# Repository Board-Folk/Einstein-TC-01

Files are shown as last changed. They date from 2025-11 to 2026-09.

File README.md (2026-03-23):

# Einstein TC-01

Repository for the 2025 Board Folk recreation of the main board of the Einstein TC-01 computer from Tatung.

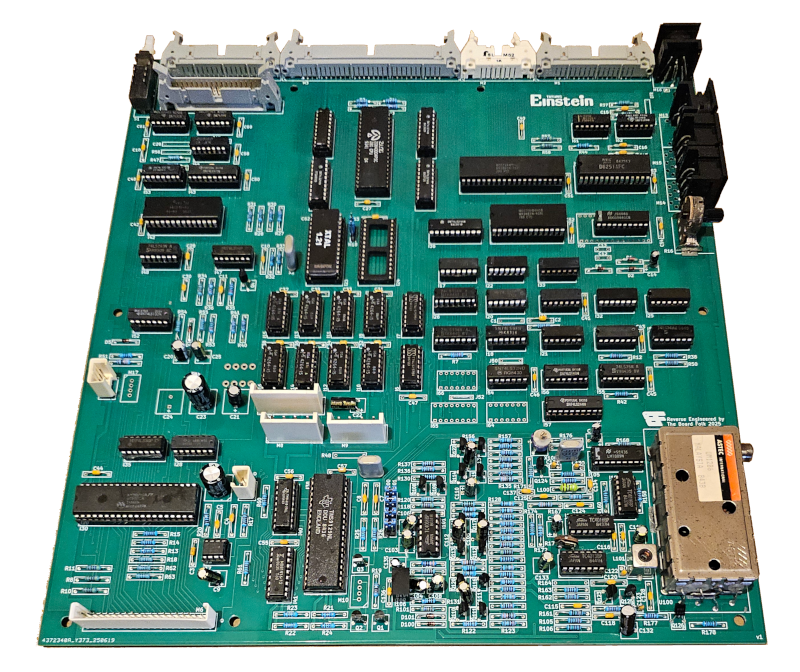
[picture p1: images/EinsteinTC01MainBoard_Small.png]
Built TC-01 board in Green


This repository contains the Bill-of-Materials (iBOM), Gerbers and Kicad files for a remake of the Tatung Einstein TC-01 main board.

Projects are in Kicad 9.

## Revisions

* Version 1.1 Initial Public Release

## Modifications

* The 3 digit references have been abridged so they work in Kicad
* The factory modifications (cuts and bodge wires) for the reset circuit have been included on the board
* Bodge capacitor C70 included on board for printer port strobe delay
* A solder jumper next to socket M16 provides the common modification of 5V power to pin 6 on the video output socket as you'd have on a BBC Micro
* Some small silkscreen improvements have been made to avoid confusion

## Build Notes

* Power connectors are 5.08mm pin headers
* M6 keyboard pin header is 2.5mm not 2.54mm pitch
* Corner line indicator on transistor footprints signifies flat front side direction, NOT pin 1
* BC307 can be subtituted for BC557
* BC308 can be subtituted for BC558
* Reset switch is the same as the one found on the TRS-80 Model I
* The ADC0844 alternative footprint is a µPD7002 which requires C13 populating with 33nF (untested)
* The value/range of L101 "Chrominance Rejector" is at this time unknown

## Archive

Currently contains the original copy of the v1.1 main board, which hasn't changed. The updated main Kicad folder now contains additional symbols and footprints only.

## Credit

Mainboard PCB layout by Rob Taylor @peepouk. Schematics recreated by Ian Cudlip @grandoldian.

## Expansions

### TMSAdapterTC01

Adapter board to allow the use of a TMS9929 chip on the Tatung Einstein TC-01.

### EinsteinTC01PS2

Arduino Nano based PS/2 Keyboard Adapter for the TC-01.

### EinsteinTC01PS2Mini

ATMEGA328 based PS/2 Keyboard Adapter for the TC-01.

### V9958AdapterTC01

Yamaha V9958/V9938 Adapter with 192K Video RAM for the TC-01.

### TC02Mini

Simple non-replica remake of the TC-02 80 column adapter for the TC01.

### Joystick Adapters

#### TC01AtariJoystick

Dual Atari Digital Joystick Adapter.

#### Withdrawn Tandy Joystick Adapter

It turns out the y axis on Tandy joysticks is connected the other way round, which means it will require circuitry to make it work for Einstein games. Trying to think of something clever for that.

## Remixes

### Einstein CE

Simplified Einstein with bits removed to fit on a small board. See description in folder.

## Coming Soon

* Another, comprehensive remix with expansions

## Links

   [10.6875MHz HC-49U Crystal](https://slawmir.com.pl/rezonator-10-6875mhz-hc49u-x5-p-6105.html)  
   [5 pin "Domino" DIN Socket for Serial Port](https://vintage.imitation.parts/products/bbc-micro-parts/din-5-pcb-socket)  
   [Modifyable bracket for holding standard Volume Pot](https://sonicsynths.com/products/pcb_mounting_bracket_for_16mm_commercial_grade_pots)

## Thanks

  * The rest of the Board Folk Team

## Legal

As the product of this project is a replica of a proprietary product, the the author makes no claim of copyright to the schematics nor PCB layouts and releases these into the public domain, solely for the purposes of study and historical preservation.

You are free to produce PCBs based on this project's designs at your own risk and without limitation, for your own use or for sale and/or repair at a reasonable price. Attribution is appreciated. The authors are not obliged to provide support of any kind. 

Under no circumstances will the authors be held responsible or liable in any way for losses, damages or costs resulting from the use of the information and/or resources of this project. 

The resources are provided "as-is" without warranty of any kind, either expressed or implied, including, but not limited to, the implied warranties of merchantability and fitness for a particular purpose.

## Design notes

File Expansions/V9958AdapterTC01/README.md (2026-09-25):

# Einstein TC-01 V9958/V9938 VDP adapter

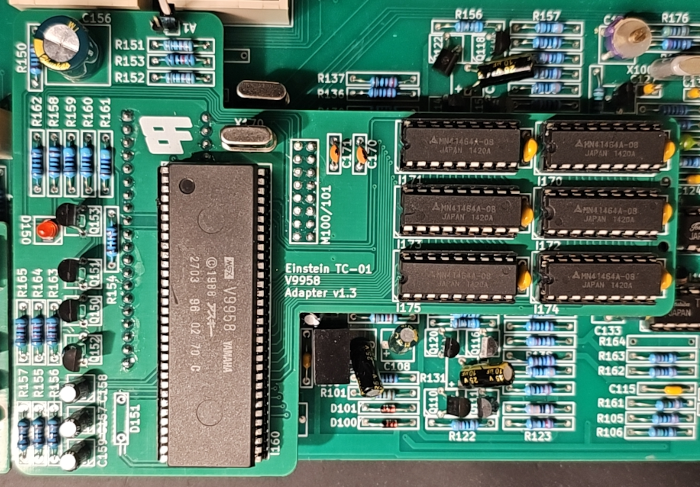
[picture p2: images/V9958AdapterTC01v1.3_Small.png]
Built TC-01 V9958 adapter board in green fitted on a TC-01


Adapter board to allow the use of a Yamaha V9958 or V9938 VDP chip on the Tatung Einstein TC-01. The board requires 192KB RAM, as 6 of 4464 (41464) RAM chips, to make the video capability of the board same as (or better than) the Einstein 256, and works with the ROM from that machine, e.g. XTAL MOS 2.1.

The board plugs into the existing VDP socket, replacing the original TMS VDP chip, and connects to video output by replacing the jumpers at M100/101 outputting RGB to the socket on the back of the TC-01. This disconnects the other video circuitry and RF output on the main board, that being YUV based.

The VDP plug to get the right height has been tested with 2 of 20 pin 15mm single pin headers and for connection for video output, 2x08 PC104 pin plug with a single spacer. Careful, as big pins can bork a DIP-40 socket, so be prepared to change that if necessary. Holes for nylon standoffs have been included at the other end of the board for support, though this isn't really necessary.

Address line A1 needs connecting up for this to function as it's not present on the original VDP socket. This is the pin with a box on the two pin header on the edge of this board. The nearest point on the main board for buffered A1 is pin 3 of I28.

Video output is provided by simple transistor based circuits. It seems fine, but some resistor values may need tweaking.

You do not need to fit the video RAM chips on the main board at I40 and I41 with this installed.

Not used or tested at the moment is the other pin on the header next to A1 which is for /WAIT which may or may not be used by any software at all, don't know about this, so connected this with a diode D151 (flagged DNP) between the VDP and the pin header. There isn't anything on the main board that uses /WAIT - that only connects to the Tatung Tube expansion port. This doesn't need connecting unless software uses it, and isn't required to function generally.

Note: The pre-connected solder bridge on the bottom of the board - required for the V9958 - should be cut if installing a V9938. This has now been tested and works fine.

Some fake/relabelled AliExpress RAM got very hot and died on this board after passing regular RAM tests, so be careful what you use. Not sure of the official speed requirements. Equally, there are plenty of completely fake V9958, many labelled copyright 1901.

## Update

A couple of issues have been noted when installing this on an original factory built TC-01 that didn't crop up in testing on the replica build. The first relating to this board, the second relating to the use of the Einstein 256 ROM in the TC-01.

### Fix 1

The original voltage regulator at I106 as factory fitted is a LM350T5, which with this VDP adapter fitted overheats and cuts out causing the system to crash. This needs replacing with a higher rating compatible regulator, 1 Amp or greater. Fitting the wrong voltage regulator or voltage regulator the wrong way round will cause serious damage. This has been successfully tested with a Traco TSR 1-2450. You can test the voltage either side of C057 (C57 on the replica) before fitting any VDP for 5V.

### Fix 2

On some systems with the Einstein 256 ROM fitted, Alph lock randomly enables and disables. This is due to a port being missing at address 26h that is present on the Einstein 256 and not on the TC-01. A patch to the ROM is needed to stop this happening.

Port 26h is read and checked for bit 0 for the Alph key being pressed in 3 places in the ROM code, first offset 7d8h. The three occurrences of db26e601 can be replaced with with db26e600 - removing the bit comparison for the Alph key.

## Photos

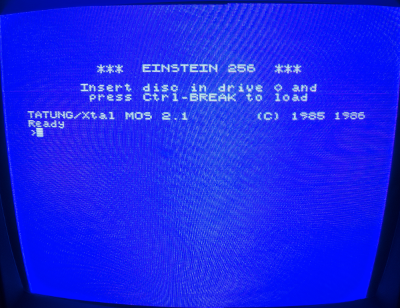
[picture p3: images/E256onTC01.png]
Einstein 256 boot screen on a TC-01


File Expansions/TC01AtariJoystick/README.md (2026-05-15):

# Einstein TC01 Dual Atari Digital Joystick Adapter v1.1

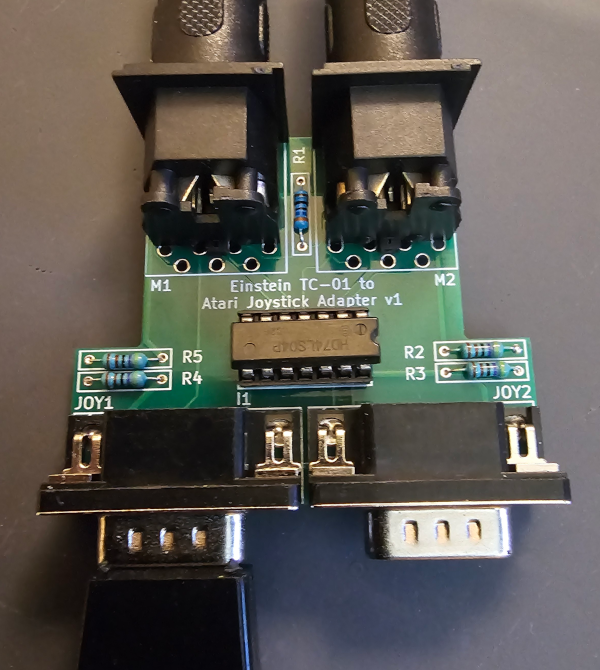
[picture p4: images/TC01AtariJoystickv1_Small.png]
Built TC01 Dual Atari joystick adapter board v1 in Green


Dual joystick adapter for Atari and compatible (Kempston/C64/Amiga/ST etc) digital joysticks. Tested with SVI Quickshot II Plus.

Based on Wizard Development 'BBC' joystick interface. Very clever, many thanks.

Update: Turns out having a fixed resistor at R1 was a bad idea as the output of the Vref circuit seems to be different between main board builds. This makes the analogue centre different. You can patch in a variable resistor/pot as an adjustment. One board needed changing to ~1K. Will post an update soon and some BASIC code for adjustment/tweaking.

## Versions

v1.1 Fix for x direction

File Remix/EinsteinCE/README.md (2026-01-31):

# Einstein CE

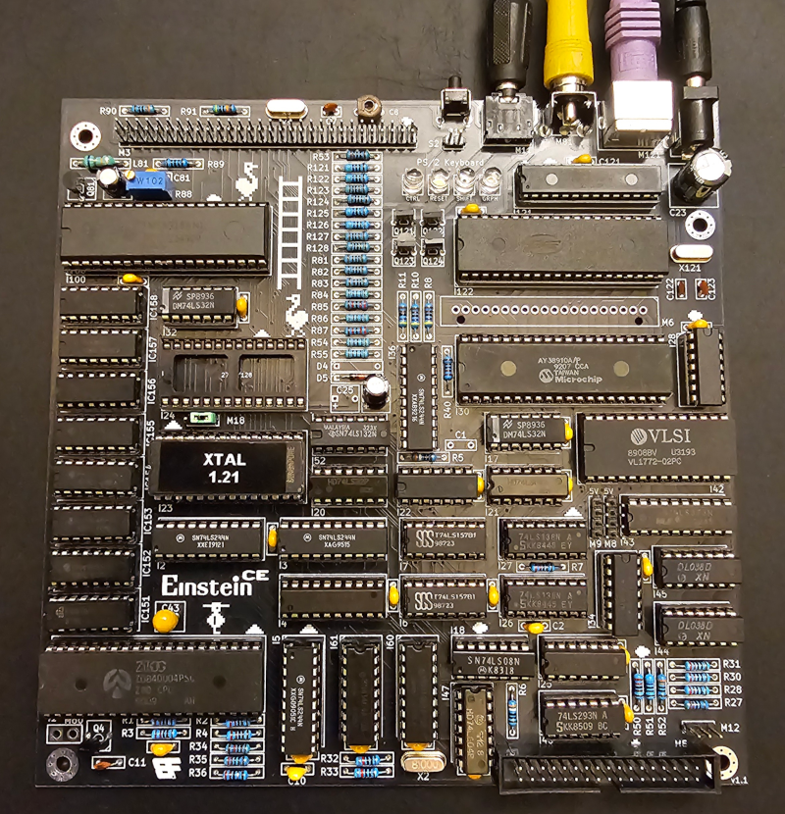
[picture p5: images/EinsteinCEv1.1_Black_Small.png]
Built Einstein CE system board in black


A simplified Einstein.

This isn't particularly serious and it's going to have some haters, so an explanation is needed first off. The idea was to do an as simple as possible Einstein - bits removed or substituted - to fit on a mini-ITX board (170x170mm) as 5V only to prove some schematics. It's cheap to make, being small and the VDP being substituted, the only particularly expensive chip being the WD1770.

The theme, as it suggests is a minimum to run Chuckie Egg. Will runs other games and things too, but nothing that requires the bits removed, with the idea of doing an overlay board to add some things back later if need be. It's not particularly beautiful, it's 50% autorouted then tidied, but it works well enough.

Video output is simple, NTSC colour composite out. PAL would be much more expensive/complex - it wouldn't fit. It's a bit of fun and means to an end.

## Revisions

* Version 1.1 Initial Public Release

## Things Removed

  * CTC
  * PIO
  * Serial port
  * Analogue joystick ports
  * YUV/RGB and RF modulator
  * Audio amplifier

## Things Changed

  * VDP and video RAM - TMS9918 and 8 of 1 bit (16K x 1) RAM
  * 4464/41464 System RAM (not 4164)
  * Simplified keyboard (IO only as no interrupt thing)
  * 2 drive support (not 4)

## Things Added

  * Stereo 3.5mm audio out (similar to Amstrad CPC)
  * PS/2 keyboard interface on board
  * Reset switch (rear right angle, and pin header)
  * Composite out (NTSC)

## Things to Note

### Power

  * Power's provided by a standard DC power jack, 5V regulated, centre positive
  * M60 header is provided as a separate 5V input - might do an adapter for an ATX type supply at some point for this
  * M8 and M9 headers for floppy power are also 5V only, pin 1 is disconnected. This is fine for Gotek

### Video RAM

As it the whole board is 5V only, the video RAM is 5V, *not* the traditional 4116 as you'd typically have with a TMS9918. Specified is MB8118 RAM if you can find it, but cheaper, 8 of the more available 4164 or 41256 RAM can be used in it place (mostly wasted, but it works).

### Known Compatibility Issues

More will follow in time

  * It appears the Einstein Speculator uses the CTC, so that's not going to work sadly

## Build Notes

  * To reiterate (sorry) in Kicad, the square pin is pin 1. On an electrolytic capacitor this is positive, the long leg. On an LED, this is K, cathode, the short leg
  * M6 remains to connect an original keyboard if necessary, and probably isn't required. This is still 2.50mm
  * C8 trims the NTSC clock frequency
  * R88 adjusts the composite brightness
  * 3.5mm Stereo Socket and RCA socket are available from Amazon (links below)
  * TMS9918 is not to be confused with TMS9118

## Links

   [3.5mm Jack Connector](https://www.amazon.co.uk/dp/B07422MCSX)  
   [RCA/Phono Jack Connector](https://www.amazon.co.uk/dp/B07PL9C7X8)  

## Credit

Schematics and PCB Layout by Ian Cudlip @grandoldian. Footprints by Rob Taylor @peepouk.

## Thanks

  * Special thanks to Chrissy (@chris_jh), Jens Restemeier (@JensRestemeier) and Leo Oliveira (@leo__oliveira).
  * The rest of the Board Folk Team.

## Photos

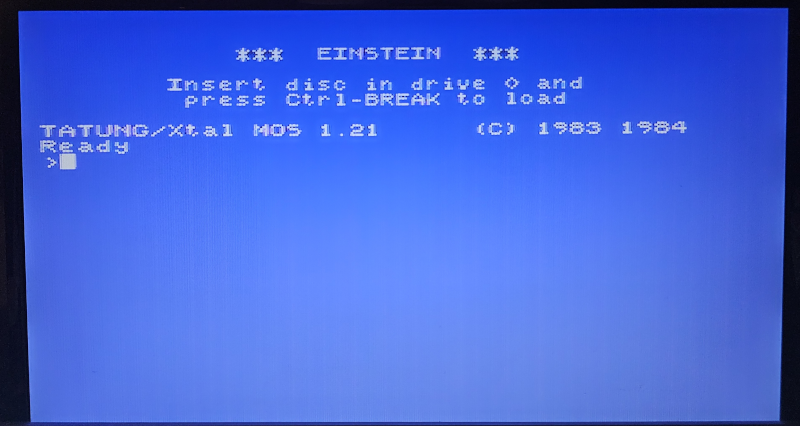
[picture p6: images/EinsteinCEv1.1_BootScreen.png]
Poor photo of Einstein CE on the Boot Screen

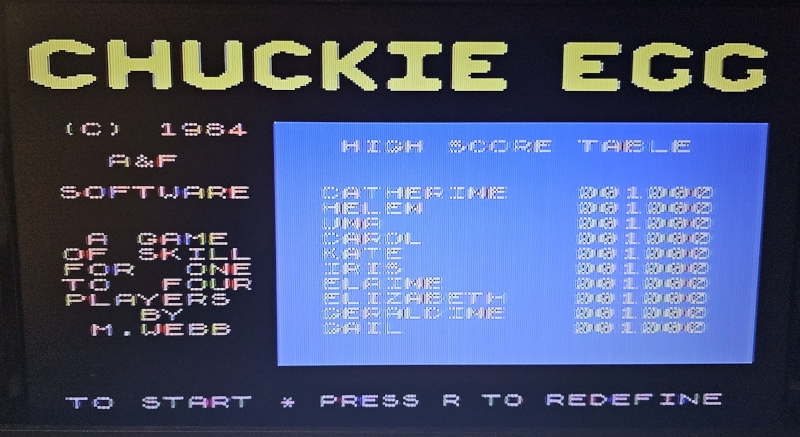
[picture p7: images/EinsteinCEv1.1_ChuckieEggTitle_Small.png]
Poor photo of Chuckie Egg Title Screen

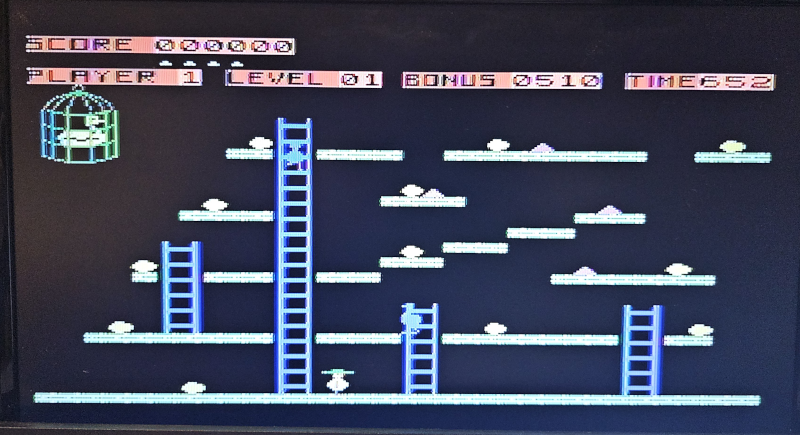
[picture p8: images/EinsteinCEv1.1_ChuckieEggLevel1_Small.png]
Poor photo of Chuckie Egg Level 1


(does look better than the photos show, though clearly NTSC)

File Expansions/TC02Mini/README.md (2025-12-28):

# Einstein TC-02Mini 80 Column Adapter

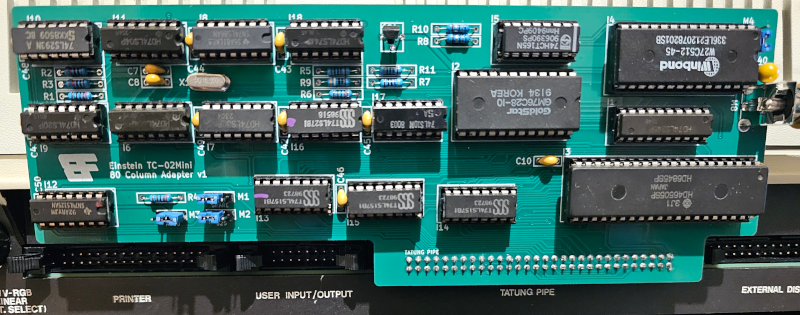
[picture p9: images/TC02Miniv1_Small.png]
Built TC-02Mini v1 adapter board in Green


A simple, non-replica (schematics the same) remake of the TC-02 80 column board. Could be mounted on a ribbon cable, or as pictured on PC104 pin sockets (at full stretch). Required Character ROM at I4 in CHARROM folder. Please see the original manual for instructions for use.

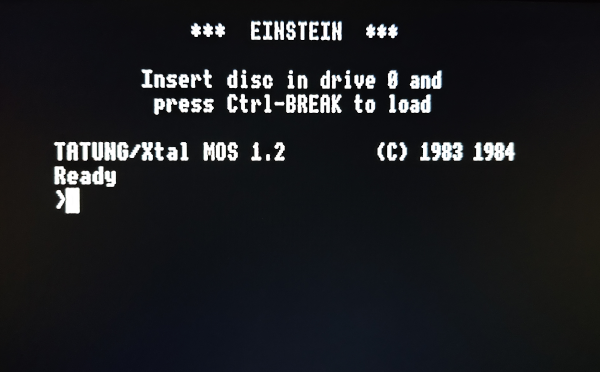
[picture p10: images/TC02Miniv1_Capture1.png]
Screenshot showing the Einstein Boot Screen


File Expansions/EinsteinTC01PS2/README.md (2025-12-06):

# EinsteinTC01PS2 v1.2

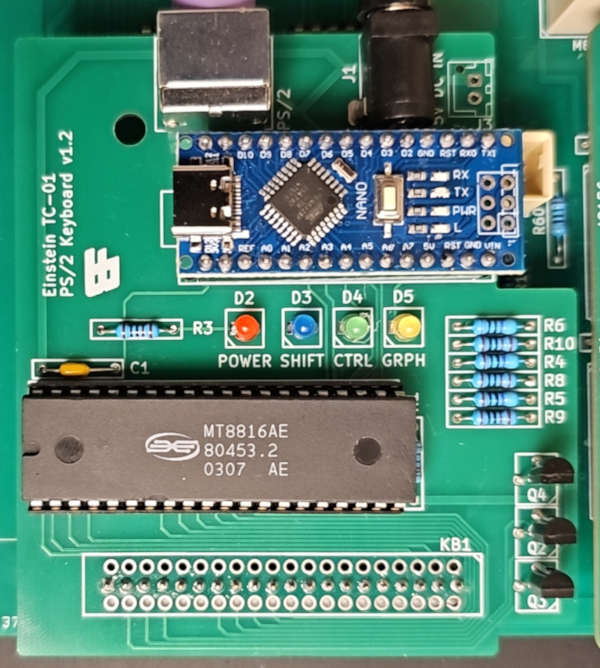
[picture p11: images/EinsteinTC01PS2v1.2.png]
Image of PS2 Nano version 1.2 board in green


The Arduino Nano version of a PS/2 keyboard adapter for the Einstein TC-01. This is a larger version of the board intended for development of the Arduino code for it, though is perfectly usable. The board uses separate pins from the Nano to pull Shift, Ctrl and Grph through BC517 darlington pairs.

The board needs a separate 5V power connection as there is no power output on the Einstein's keyboard header. Footprints for both a barrel jack and 2 pin XH connector are provided for this.

There are 3 rows of pin headers, the centre row being 2.54mm, the other 2 2.50mm same as the main board. This arrangement could be use for passthrough to an existing keyboard if necessary.

## Code

The Arduino folder contains the code and can be loaded with Arduino IDE. This is based on C64Keyboard by Robert VanHazinga. Key mappings can be found in keymapping.h. This code is the same for smaller EinsteinTC02PS2, the built binaries for which are in the build folder.

The code is usable as is, but will improve over time. Sometimes gets stuck needing a hard reset. It includes code for future remix versions of the project, including keyboard reset and separate Alph for the 256.

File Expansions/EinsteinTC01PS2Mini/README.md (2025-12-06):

# EinsteinTC01PS2Mini v1

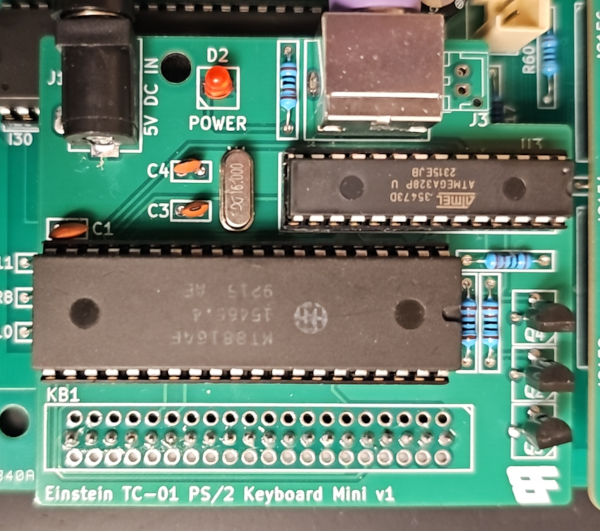
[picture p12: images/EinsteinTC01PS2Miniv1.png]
Image of PS2 ATMEGA328 version 1 board in green


The smaller ATMEGA328 version of a PS/2 keyboard adapter for the Einstein TC-01. The board uses separate pins from the Nano to pull Shift, Ctrl and Grph through BC517 darlington pairs. This version doesn't include indicator LEDs for these.

The board needs a separate 5V power connection as there is no power output on the Einstein's keyboard header. Footprints for both a barrel jack and 2 pin XH connector are provided for this.

There are 3 rows of pin headers, the centre row being 2.54mm, the other 2 2.50mm same as the main board. This arrangement could be use for passthrough to an existing keyboard if necessary.

## Code

Code can be found in the EinsteinTC01PS2 folder, including the compiled binaries for the ATMEGA328. See any notes in there. The Minipro TL866 II can be use to program that. These settings work:

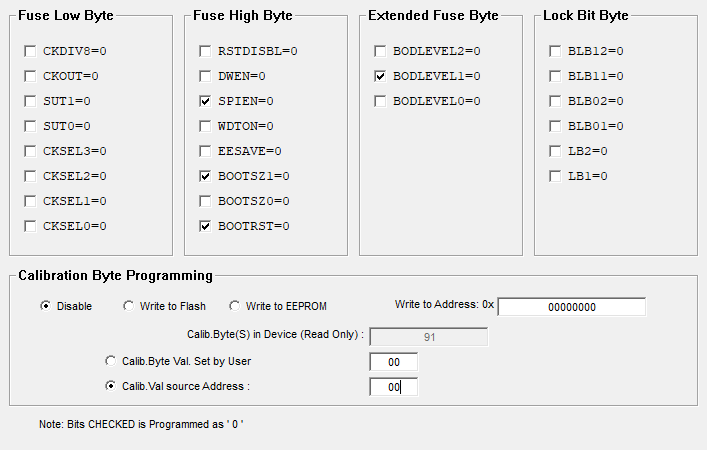
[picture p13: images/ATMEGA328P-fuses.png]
Windows Minipro software settings for programming the ATMEGA328 for this board


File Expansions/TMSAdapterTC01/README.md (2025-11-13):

# Einstein TC-01 TMS9929 adapter

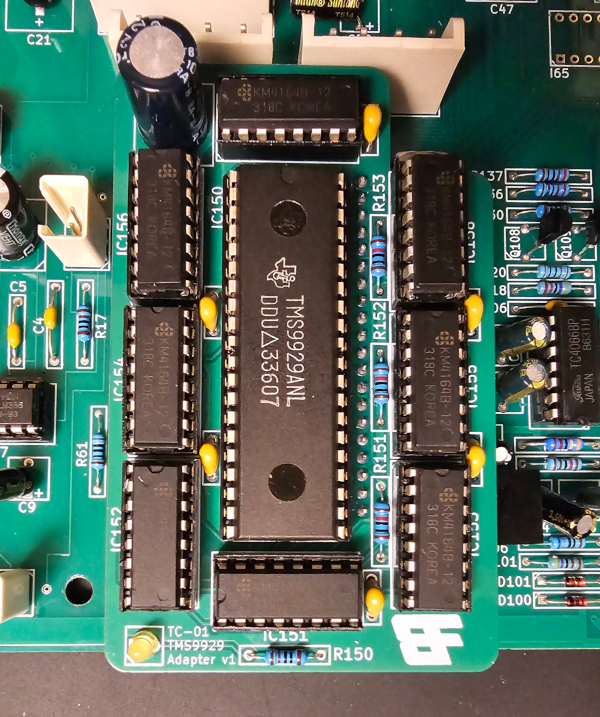
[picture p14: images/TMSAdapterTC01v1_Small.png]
Built TC-01 TMS9929 adapter board in Green


Adapter board to allow the use of a TMS9929 chip on the Tatung Einstein TC-01. The TMS9929 is easier to find than the original VDP, but requires a different type of RAM which needs fitting to the adapter.

Intended to work with 5V 1x16K DRAM chips, e.g. MB8118 or compatible, but can accept 4164 and 41256 RAM, which although is a waste as the majority of the RAM isn't used are more easily and cheaply obtained. This will not work with 4116 RAM as the board doesn't provide the correct voltages.

You do not need to fit the video RAM chips on the main board at I40 and I41 with this installed.

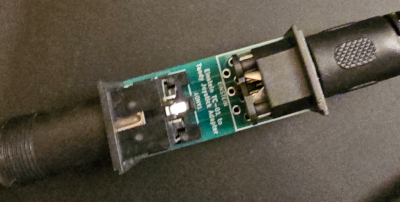
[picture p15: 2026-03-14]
images/TC01TandyJoystickv1_Small.png

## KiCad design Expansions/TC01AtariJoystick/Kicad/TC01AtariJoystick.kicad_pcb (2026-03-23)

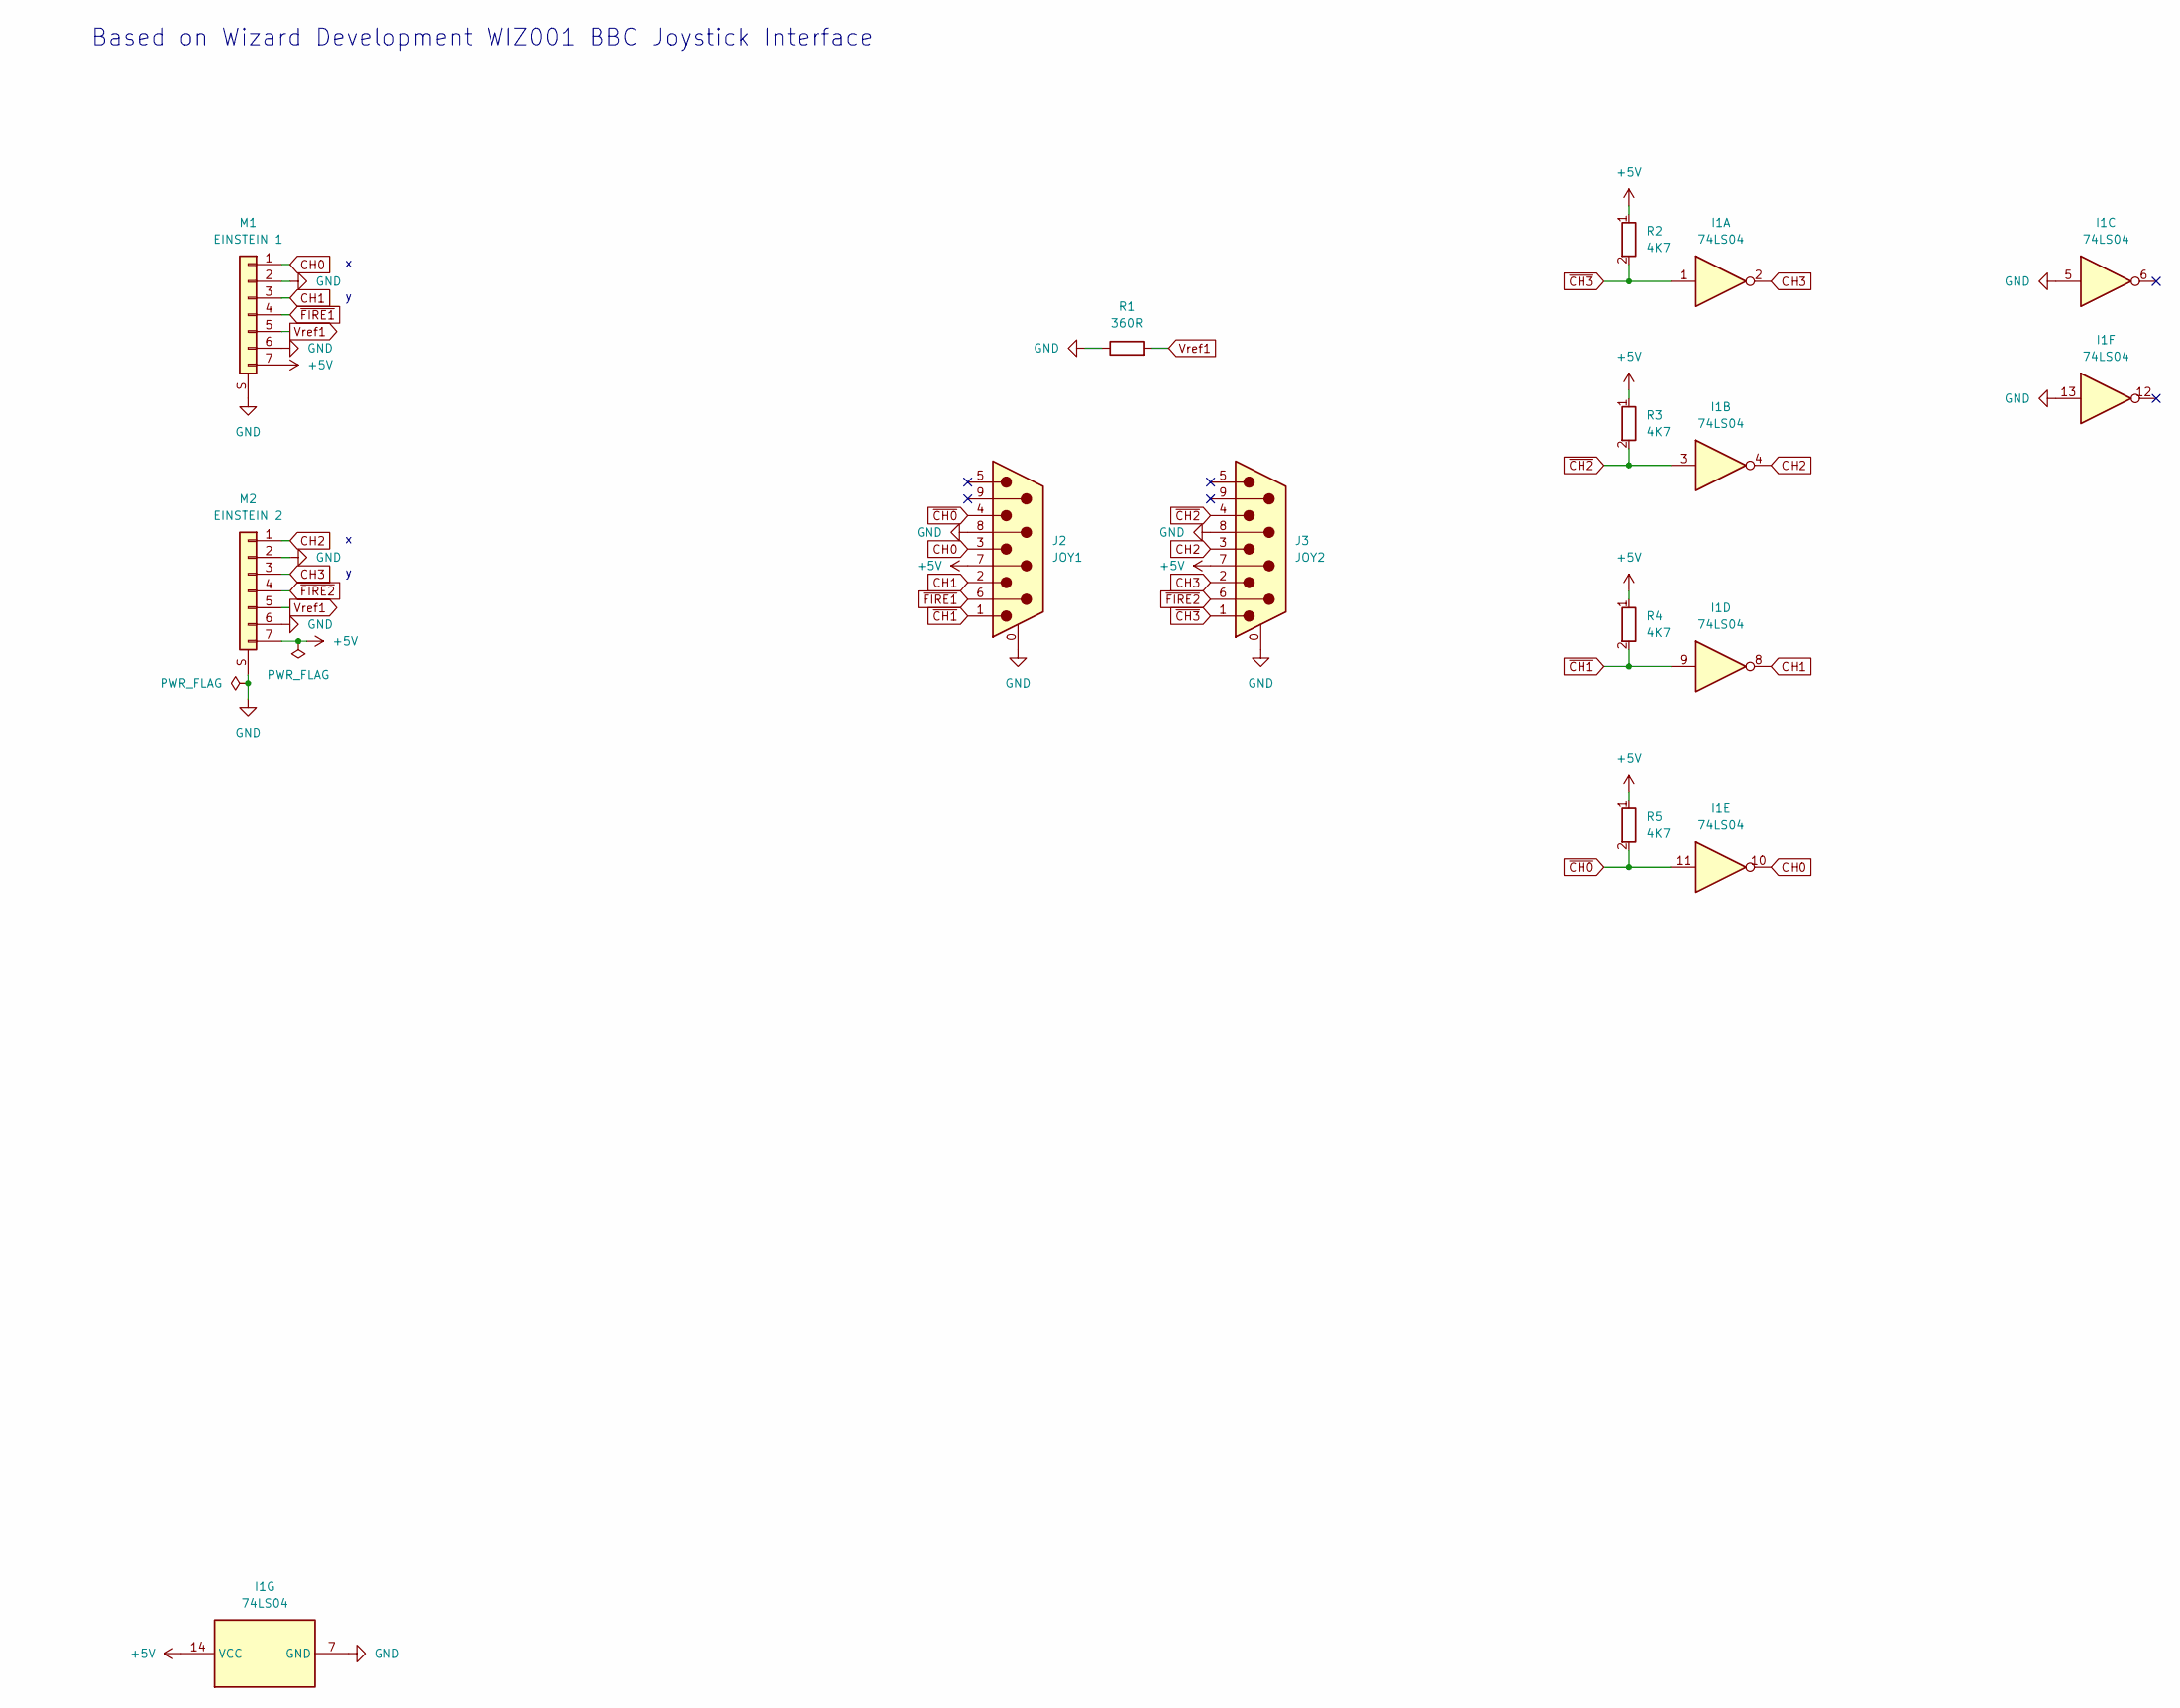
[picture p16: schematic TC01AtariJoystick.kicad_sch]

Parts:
I1: 74LS04; DIP-14_W7.62mm
J2: JOY1; DSUB-9_Pins_7.70mm_9.12mm
J3: JOY2; DSUB-9_Pins_7.70mm_9.12mm
M1: EINSTEIN 1; DIN7_3WAYS
M2: EINSTEIN 2; DIN7_3WAYS
R1: 360R; Resistor 10.16mm
R2, R3, R4, R5: 4K7; Resistor 10.16mm

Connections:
+5V: I1.14 (VCC), J2.7, J3.7, M1.7, M2.7, R2.1, R3.1, R4.1, R5.1
CH0: I1.10, J2.3, M1.1
CH1: I1.8, J2.2, M1.3
CH2: I1.4, J3.3, M2.1
CH3: I1.2, J3.2, M2.3
GND: I1.5, I1.7 (GND), I1.13, J2.0 (PAD), J2.8, J3.0 (PAD), J3.8, M1.2, M1.6, M1.S (Shield), M2.2, M2.6, M2.S (Shield), R1.1
Vref1: M1.5, M2.5, R1.2
~CH0: I1.11, J2.4, R5.2
~CH1: I1.9, J2.1, R4.2
~CH2: I1.3, J3.4, R3.2
~CH3: I1.1, J3.1, R2.2
~FIRE1: J2.6, M1.4
~FIRE2: J3.6, M2.4

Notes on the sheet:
Based on Wizard Development WIZ001 BBC Joystick Interface

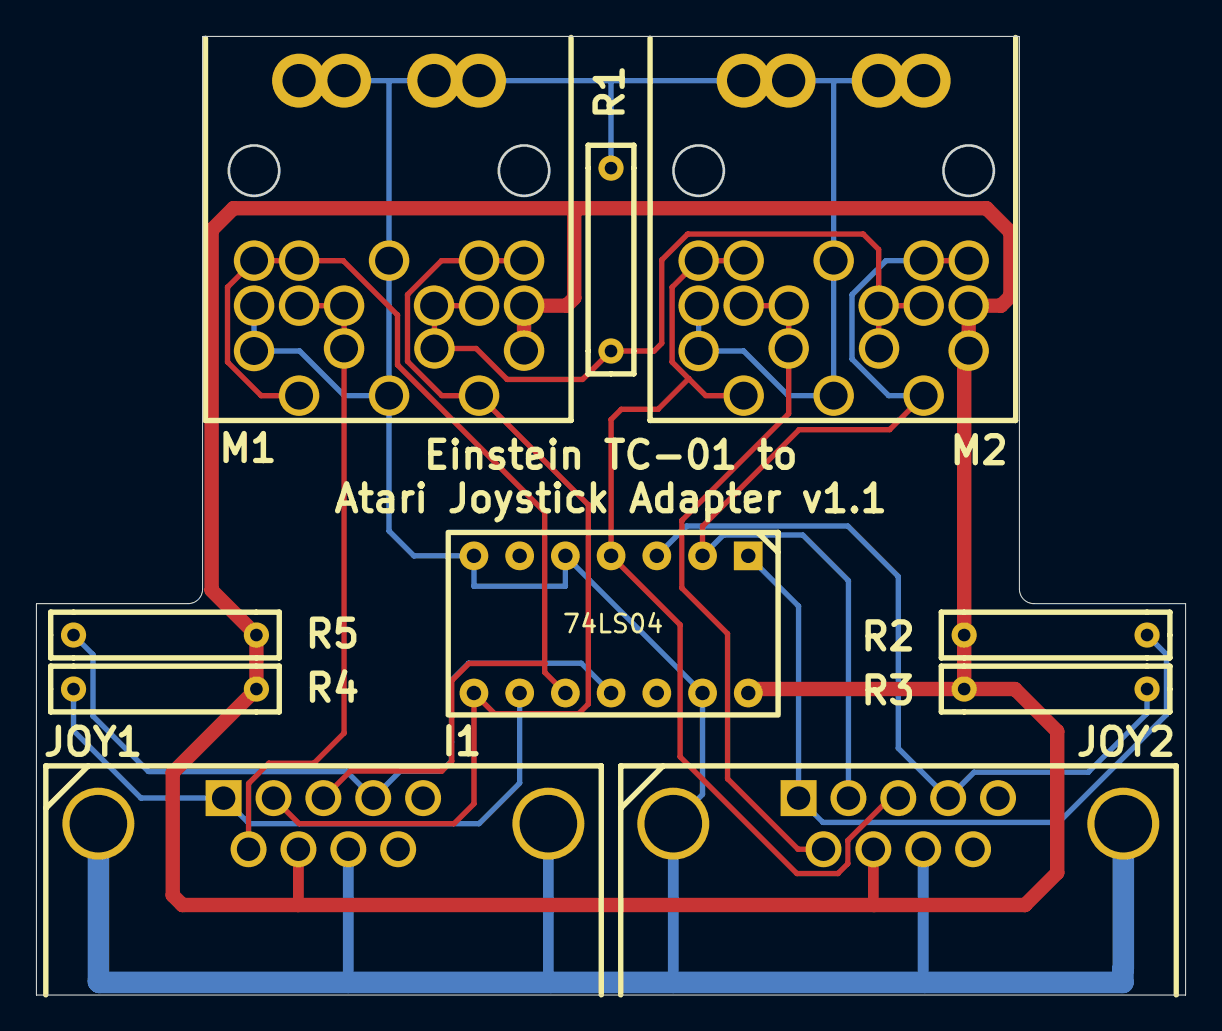
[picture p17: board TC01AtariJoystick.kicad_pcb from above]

Board: 2 copper layers, 63.8 x 53.3 mm, 10 parts (0 on the bottom side), 13 nets.

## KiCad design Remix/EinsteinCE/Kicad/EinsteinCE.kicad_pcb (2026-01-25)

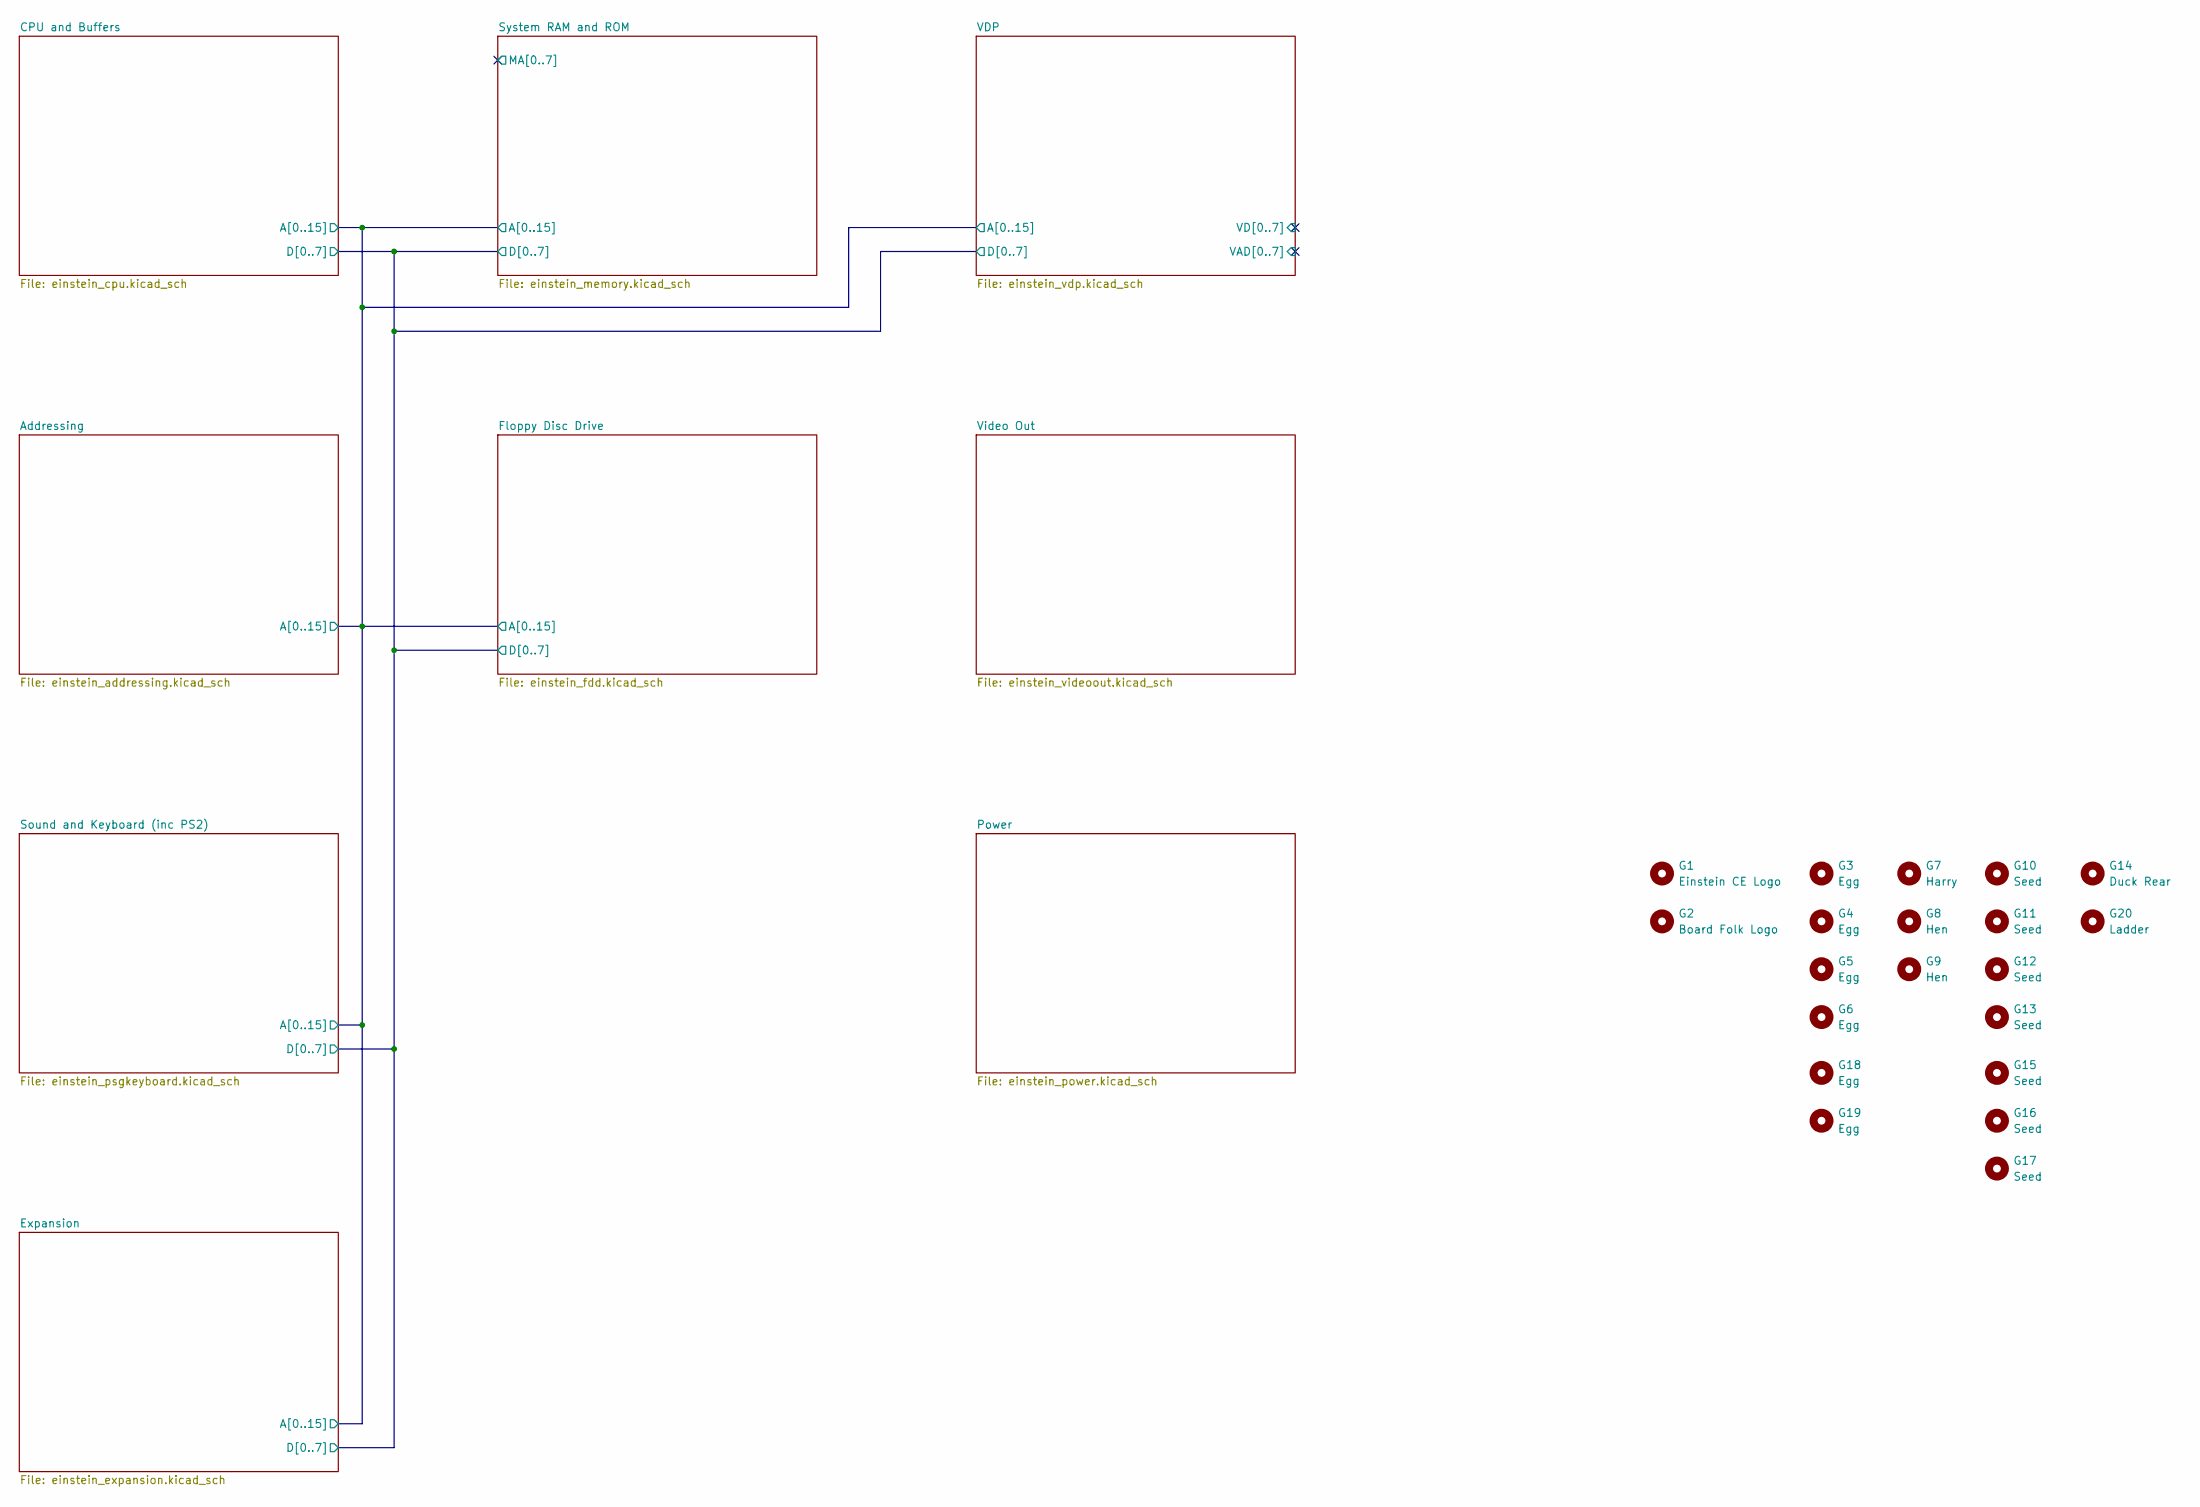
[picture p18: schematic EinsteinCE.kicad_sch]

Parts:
G1: Einstein CE Logo; EinsteinCELogo28mm
G2: Board Folk Logo; BF8
G3, G4, G5, G6, G18, G19: Egg; Egg5mm
G7: Harry; Harry8mm
G8: Hen; Hen8mm
G9: Hen; Hen_Left_8mm
G10, G11, G12, G13, G15, G16, G17: Seed; Seed6mm
G14: Duck Rear; Duck166mm
G20: Ladder

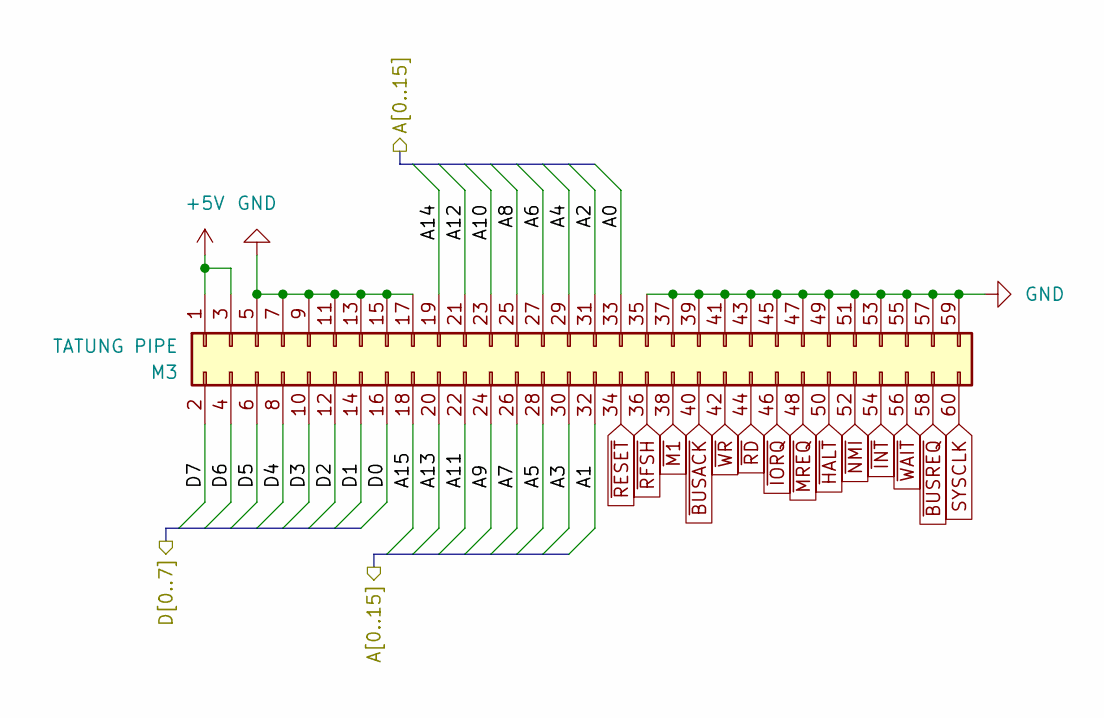
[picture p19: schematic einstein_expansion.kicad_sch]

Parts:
M3: TATUNG PIPE; M3 PinHeader_2x30_P2.54mm

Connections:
+5V: M3.1, M3.3; also elsewhere on the board
/Addressing/A0: M3.33; also elsewhere on the board
/Addressing/A1: M3.32; also elsewhere on the board
/Addressing/A2: M3.31; also elsewhere on the board
/Addressing/A3: M3.30; also elsewhere on the board
/Addressing/A4: M3.29; also elsewhere on the board
/Addressing/A5: M3.28; also elsewhere on the board
/Addressing/A6: M3.27; also elsewhere on the board
/Addressing/A7: M3.26; also elsewhere on the board
/Addressing/A8: M3.25; also elsewhere on the board
/Addressing/A9: M3.24; also elsewhere on the board
/Addressing/A10: M3.23; also elsewhere on the board
/Addressing/A11: M3.22; also elsewhere on the board
/Addressing/A12: M3.21; also elsewhere on the board
/Addressing/A13: M3.20; also elsewhere on the board
/Addressing/A14: M3.19; also elsewhere on the board
/Addressing/A15: M3.18; also elsewhere on the board
/CPU and Buffers/D0: M3.16; also elsewhere on the board
/CPU and Buffers/D1: M3.14; also elsewhere on the board
/CPU and Buffers/D2: M3.12; also elsewhere on the board
/CPU and Buffers/D3: M3.10; also elsewhere on the board
/CPU and Buffers/D4: M3.8; also elsewhere on the board
/CPU and Buffers/D5: M3.6; also elsewhere on the board
/CPU and Buffers/D6: M3.4; also elsewhere on the board
/CPU and Buffers/D7: M3.2; also elsewhere on the board
GND: M3.5, M3.7, M3.9, M3.11, M3.13, M3.15, M3.17, M3.35, M3.37, M3.39, M3.41, M3.43, M3.45, M3.47, M3.49, M3.51, M3.53, M3.55, M3.57, M3.59; also elsewhere on the board
SYSCLK: M3.60; also elsewhere on the board
~BUSACK: M3.40; also elsewhere on the board
~BUSREQ: M3.58; also elsewhere on the board
~HALT: M3.50; also elsewhere on the board
~INT: M3.54; also elsewhere on the board
~IORQ: M3.46; also elsewhere on the board
~M1: M3.38; also elsewhere on the board
~MREQ: M3.48; also elsewhere on the board
~NMI: M3.52; also elsewhere on the board
~RD: M3.44; also elsewhere on the board
~RESET: M3.34; also elsewhere on the board
~RFSH: M3.36; also elsewhere on the board
~WAIT: M3.56; also elsewhere on the board
~WR: M3.42; also elsewhere on the board

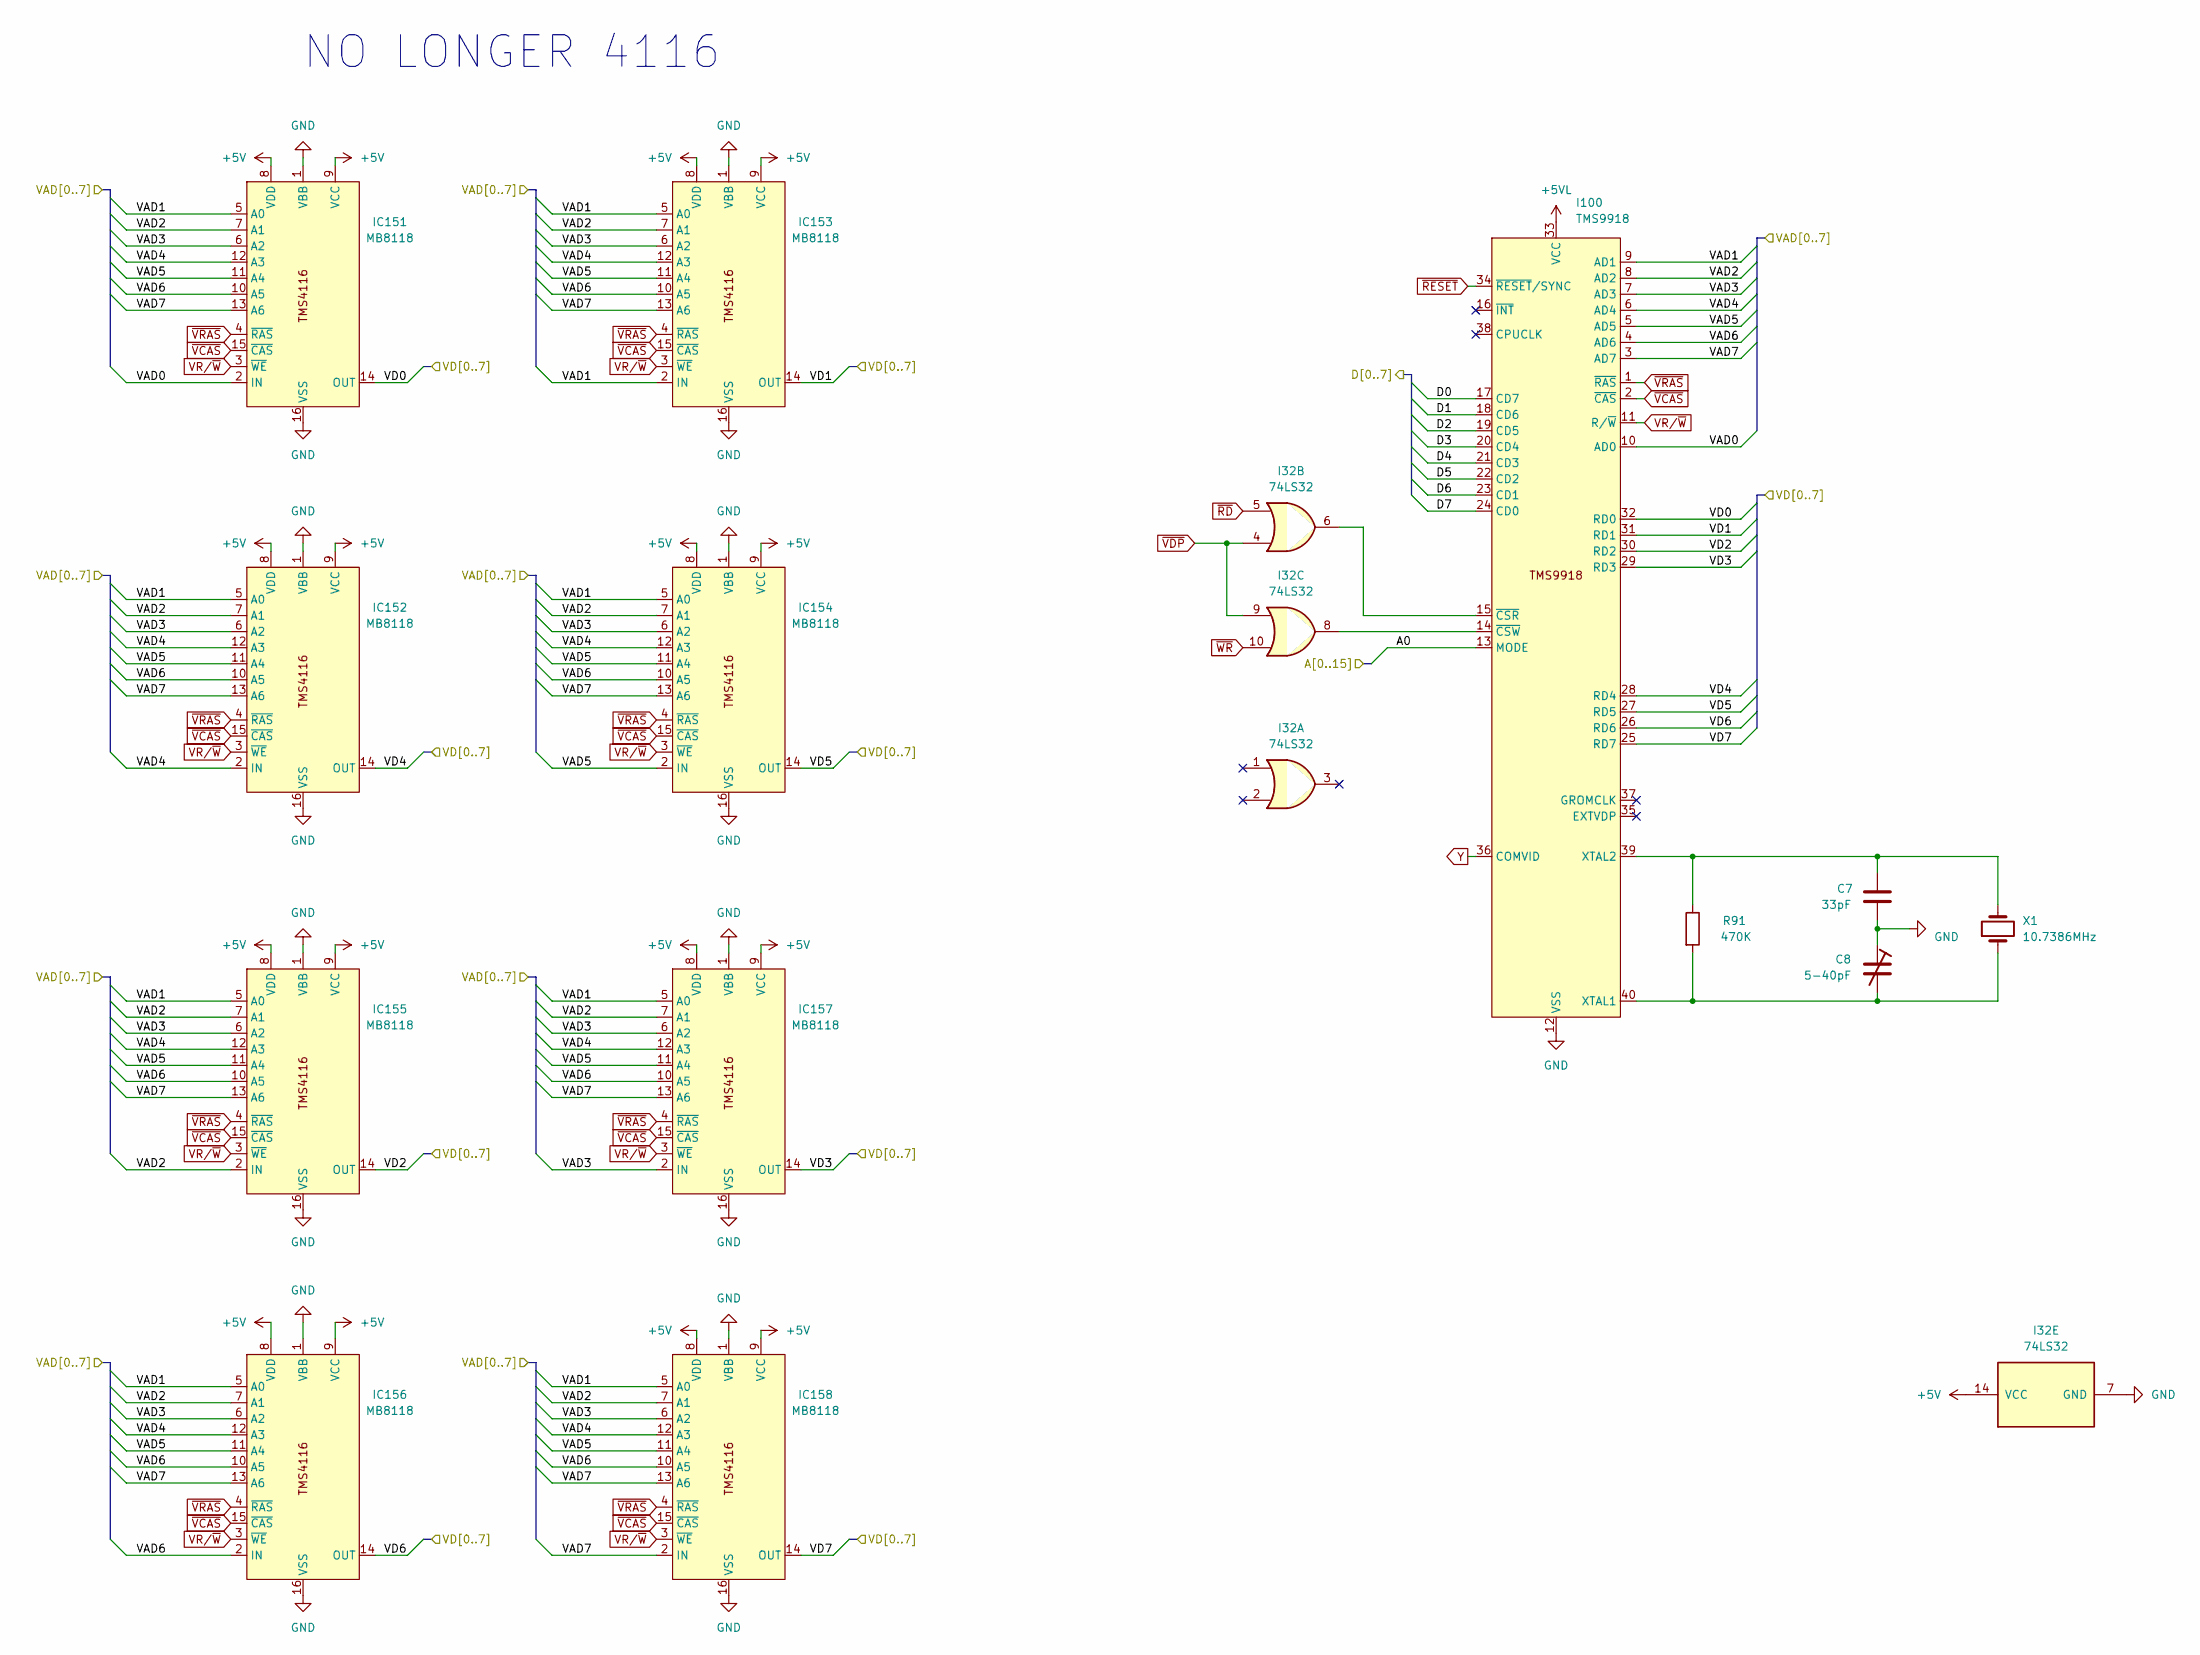
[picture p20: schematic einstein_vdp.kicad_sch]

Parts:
C7: 33pF; C_Disc_2.54mm
C8: 5-40pF; CVN6500
I32: 74LS32; DIP-14_W7.62mm
I100: TMS9918; DIP-40_W15.24mm
IC151, IC152, IC153, IC154, IC155, IC156, IC157, IC158: MB8118; DIP-16_W7.62mm
R91: 470K; Resistor 10.16mm
X1: 10.7386MHz; Crystal

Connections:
+5V: I32.14 (VCC), IC151.8 (VDD), IC151.9 (VCC), IC152.8 (VDD), IC152.9 (VCC), IC153.8 (VDD), IC153.9 (VCC), IC154.8 (VDD), IC154.9 (VCC), IC155.8 (VDD), IC155.9 (VCC), IC156.8 (VDD), IC156.9 (VCC), IC157.8 (VDD), IC157.9 (VCC), IC158.8 (VDD), IC158.9 (VCC); also elsewhere on the board
+5VL: I100.33 (VCC); also elsewhere on the board
/Addressing/A0: I100.13 (MODE); also elsewhere on the board
/CPU and Buffers/D0: I100.17 (CD7); also elsewhere on the board
/CPU and Buffers/D1: I100.18 (CD6); also elsewhere on the board
/CPU and Buffers/D2: I100.19 (CD5); also elsewhere on the board
/CPU and Buffers/D3: I100.20 (CD4); also elsewhere on the board
/CPU and Buffers/D4: I100.21 (CD3); also elsewhere on the board
/CPU and Buffers/D5: I100.22 (CD2); also elsewhere on the board
/CPU and Buffers/D6: I100.23 (CD1); also elsewhere on the board
/CPU and Buffers/D7: I100.24 (CD0); also elsewhere on the board
/VDP/VAD0: I100.10 (AD0), IC151.2 (IN)
/VDP/VAD1: I100.9 (AD1), IC151.5 (A0), IC152.5 (A0), IC153.2 (IN), IC153.5 (A0), IC154.5 (A0), IC155.5 (A0), IC156.5 (A0), IC157.5 (A0), IC158.5 (A0)
/VDP/VAD2: I100.8 (AD2), IC151.7 (A1), IC152.7 (A1), IC153.7 (A1), IC154.7 (A1), IC155.2 (IN), IC155.7 (A1), IC156.7 (A1), IC157.7 (A1), IC158.7 (A1)
/VDP/VAD3: I100.7 (AD3), IC151.6 (A2), IC152.6 (A2), IC153.6 (A2), IC154.6 (A2), IC155.6 (A2), IC156.6 (A2), IC157.2 (IN), IC157.6 (A2), IC158.6 (A2)
/VDP/VAD4: I100.6 (AD4), IC151.12 (A3), IC152.2 (IN), IC152.12 (A3), IC153.12 (A3), IC154.12 (A3), IC155.12 (A3), IC156.12 (A3), IC157.12 (A3), IC158.12 (A3)
/VDP/VAD5: I100.5 (AD5), IC151.11 (A4), IC152.11 (A4), IC153.11 (A4), IC154.2 (IN), IC154.11 (A4), IC155.11 (A4), IC156.11 (A4), IC157.11 (A4), IC158.11 (A4)
/VDP/VAD6: I100.4 (AD6), IC151.10 (A5), IC152.10 (A5), IC153.10 (A5), IC154.10 (A5), IC155.10 (A5), IC156.2 (IN), IC156.10 (A5), IC157.10 (A5), IC158.10 (A5)
/VDP/VAD7: I100.3 (AD7), IC151.13 (A6), IC152.13 (A6), IC153.13 (A6), IC154.13 (A6), IC155.13 (A6), IC156.13 (A6), IC157.13 (A6), IC158.2 (IN), IC158.13 (A6)
/VDP/VD0: I100.32 (RD0), IC151.14 (OUT)
/VDP/VD1: I100.31 (RD1), IC153.14 (OUT)
/VDP/VD2: I100.30 (RD2), IC155.14 (OUT)
/VDP/VD3: I100.29 (RD3), IC157.14 (OUT)
/VDP/VD4: I100.28 (RD4), IC152.14 (OUT)
/VDP/VD5: I100.27 (RD5), IC154.14 (OUT)
/VDP/VD6: I100.26 (RD6), IC156.14 (OUT)
/VDP/VD7: I100.25 (RD7), IC158.14 (OUT)
GND: C7.2, C8.1, I32.7 (GND), I100.12 (VSS), IC151.1 (VBB), IC151.16 (VSS), IC152.1 (VBB), IC152.16 (VSS), IC153.1 (VBB), IC153.16 (VSS), IC154.1 (VBB), IC154.16 (VSS), IC155.1 (VBB), IC155.16 (VSS), IC156.1 (VBB), IC156.16 (VSS), IC157.1 (VBB), IC157.16 (VSS), IC158.1 (VBB), IC158.16 (VSS); also elsewhere on the board
unnamed: C8.2, I100.40 (XTAL1), R91.2, X1.1
unnamed: C7.1, I100.39 (XTAL2), R91.1, X1.2
unnamed: I32.6, I100.15 (~CSR)
unnamed: I32.8, I100.14 (~CSW)
VR/~W: I100.11 (R/~W), IC151.3 (~WE), IC152.3 (~WE), IC153.3 (~WE), IC154.3 (~WE), IC155.3 (~WE), IC156.3 (~WE), IC157.3 (~WE), IC158.3 (~WE)
Y: I100.36 (COMVID); also elsewhere on the board
~RD: I32.5; also elsewhere on the board
~RESET: I100.34 (~RESET/SYNC); also elsewhere on the board
~VCAS: I100.2 (~CAS), IC151.15 (~CAS), IC152.15 (~CAS), IC153.15 (~CAS), IC154.15 (~CAS), IC155.15 (~CAS), IC156.15 (~CAS), IC157.15 (~CAS), IC158.15 (~CAS)
~VDP: I32.4, I32.9; also elsewhere on the board
~VRAS: I100.1 (~RAS), IC151.4 (~RAS), IC152.4 (~RAS), IC153.4 (~RAS), IC154.4 (~RAS), IC155.4 (~RAS), IC156.4 (~RAS), IC157.4 (~RAS), IC158.4 (~RAS)
~WR: I32.10; also elsewhere on the board

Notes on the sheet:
NO LONGER 4116

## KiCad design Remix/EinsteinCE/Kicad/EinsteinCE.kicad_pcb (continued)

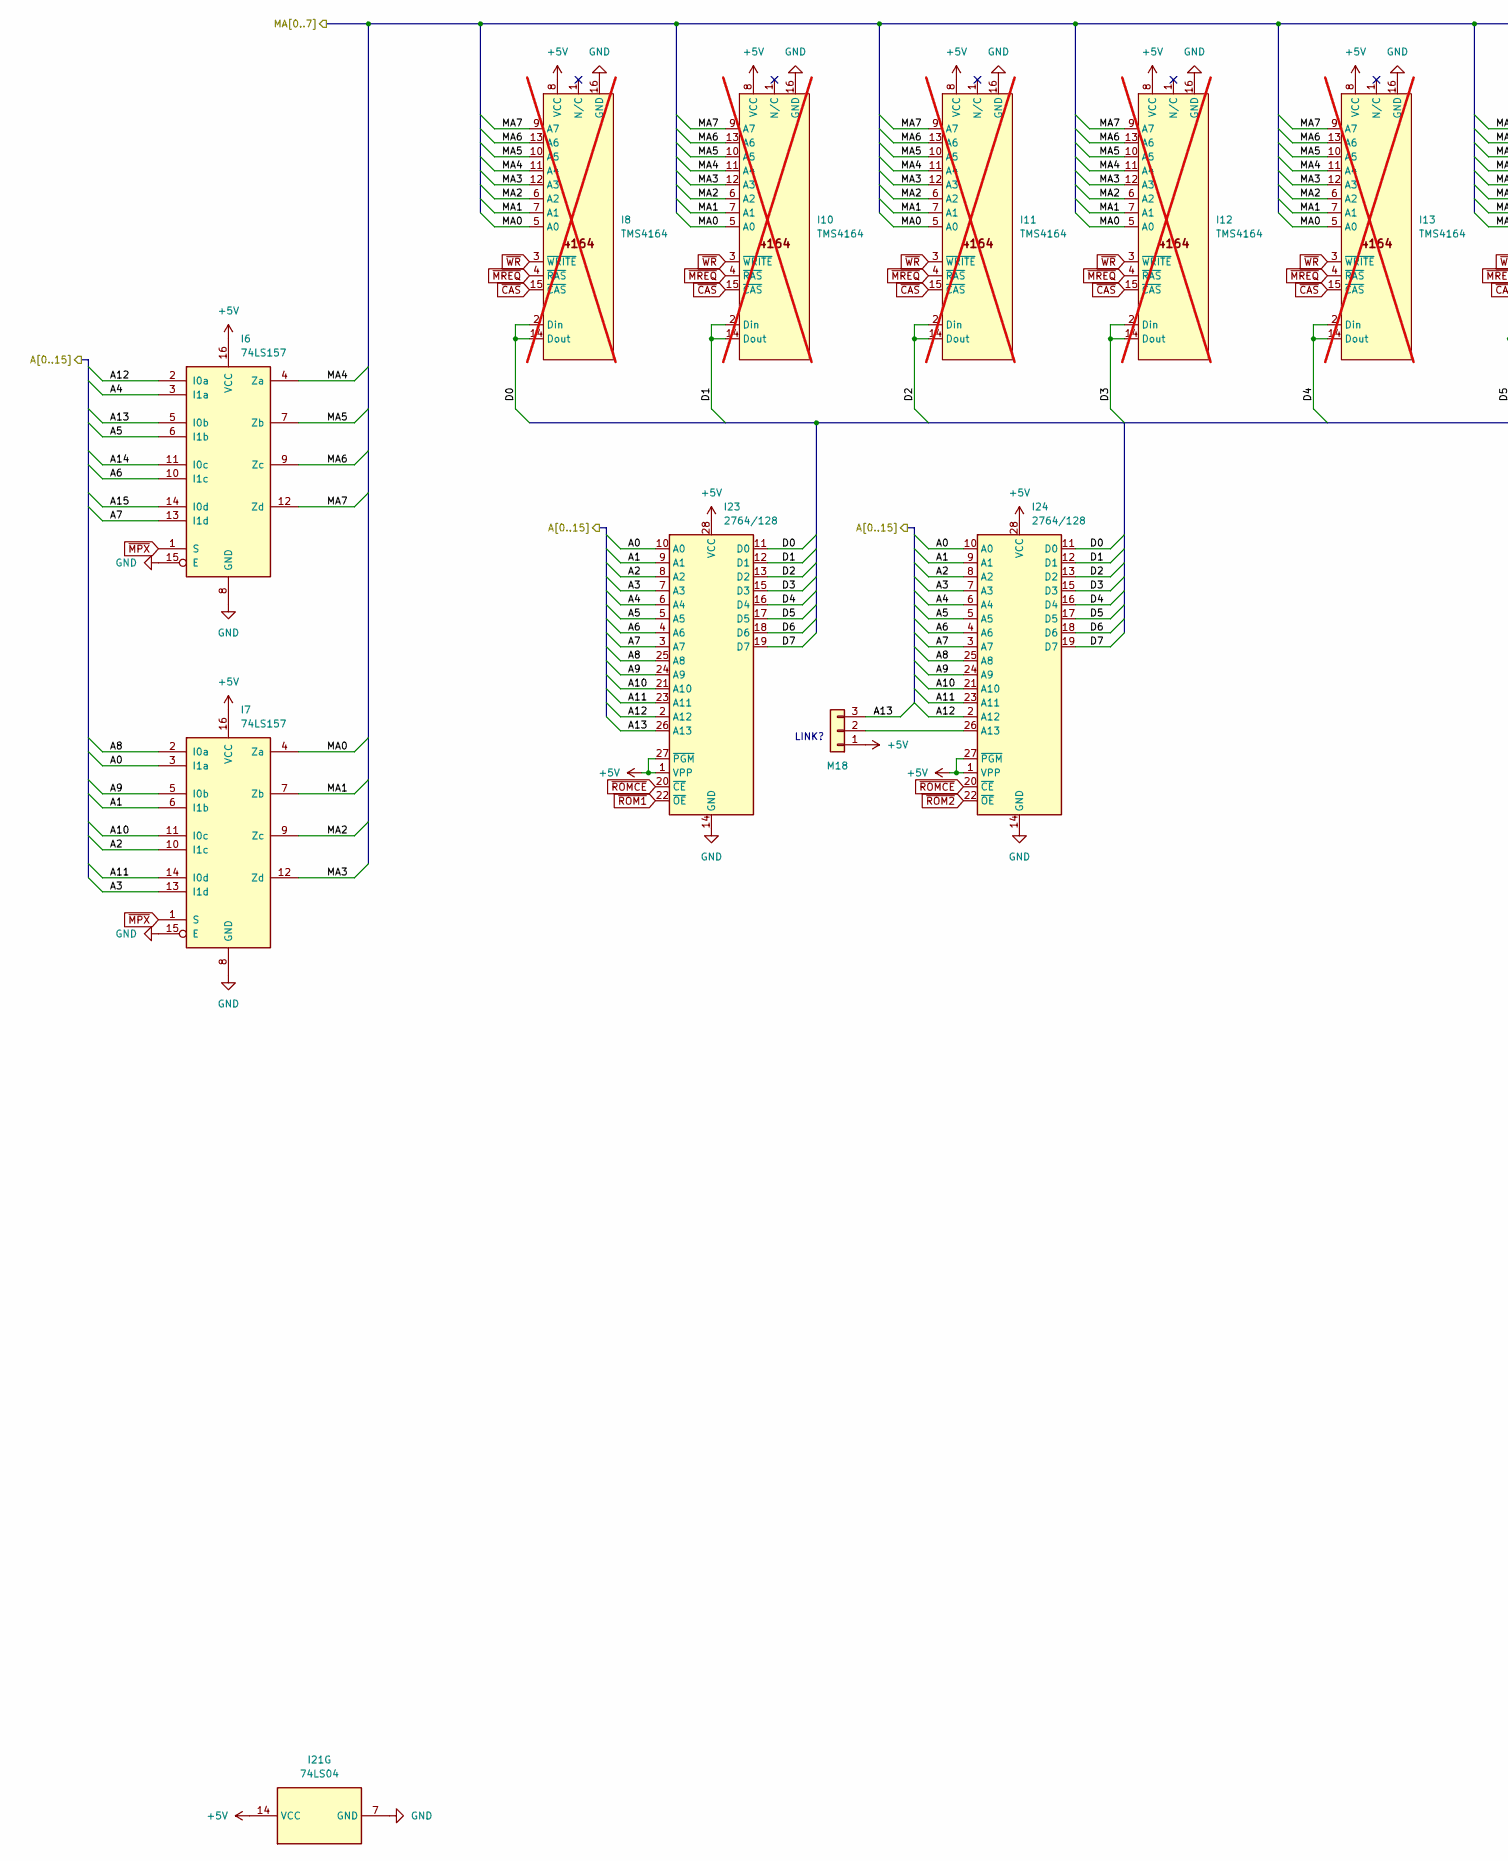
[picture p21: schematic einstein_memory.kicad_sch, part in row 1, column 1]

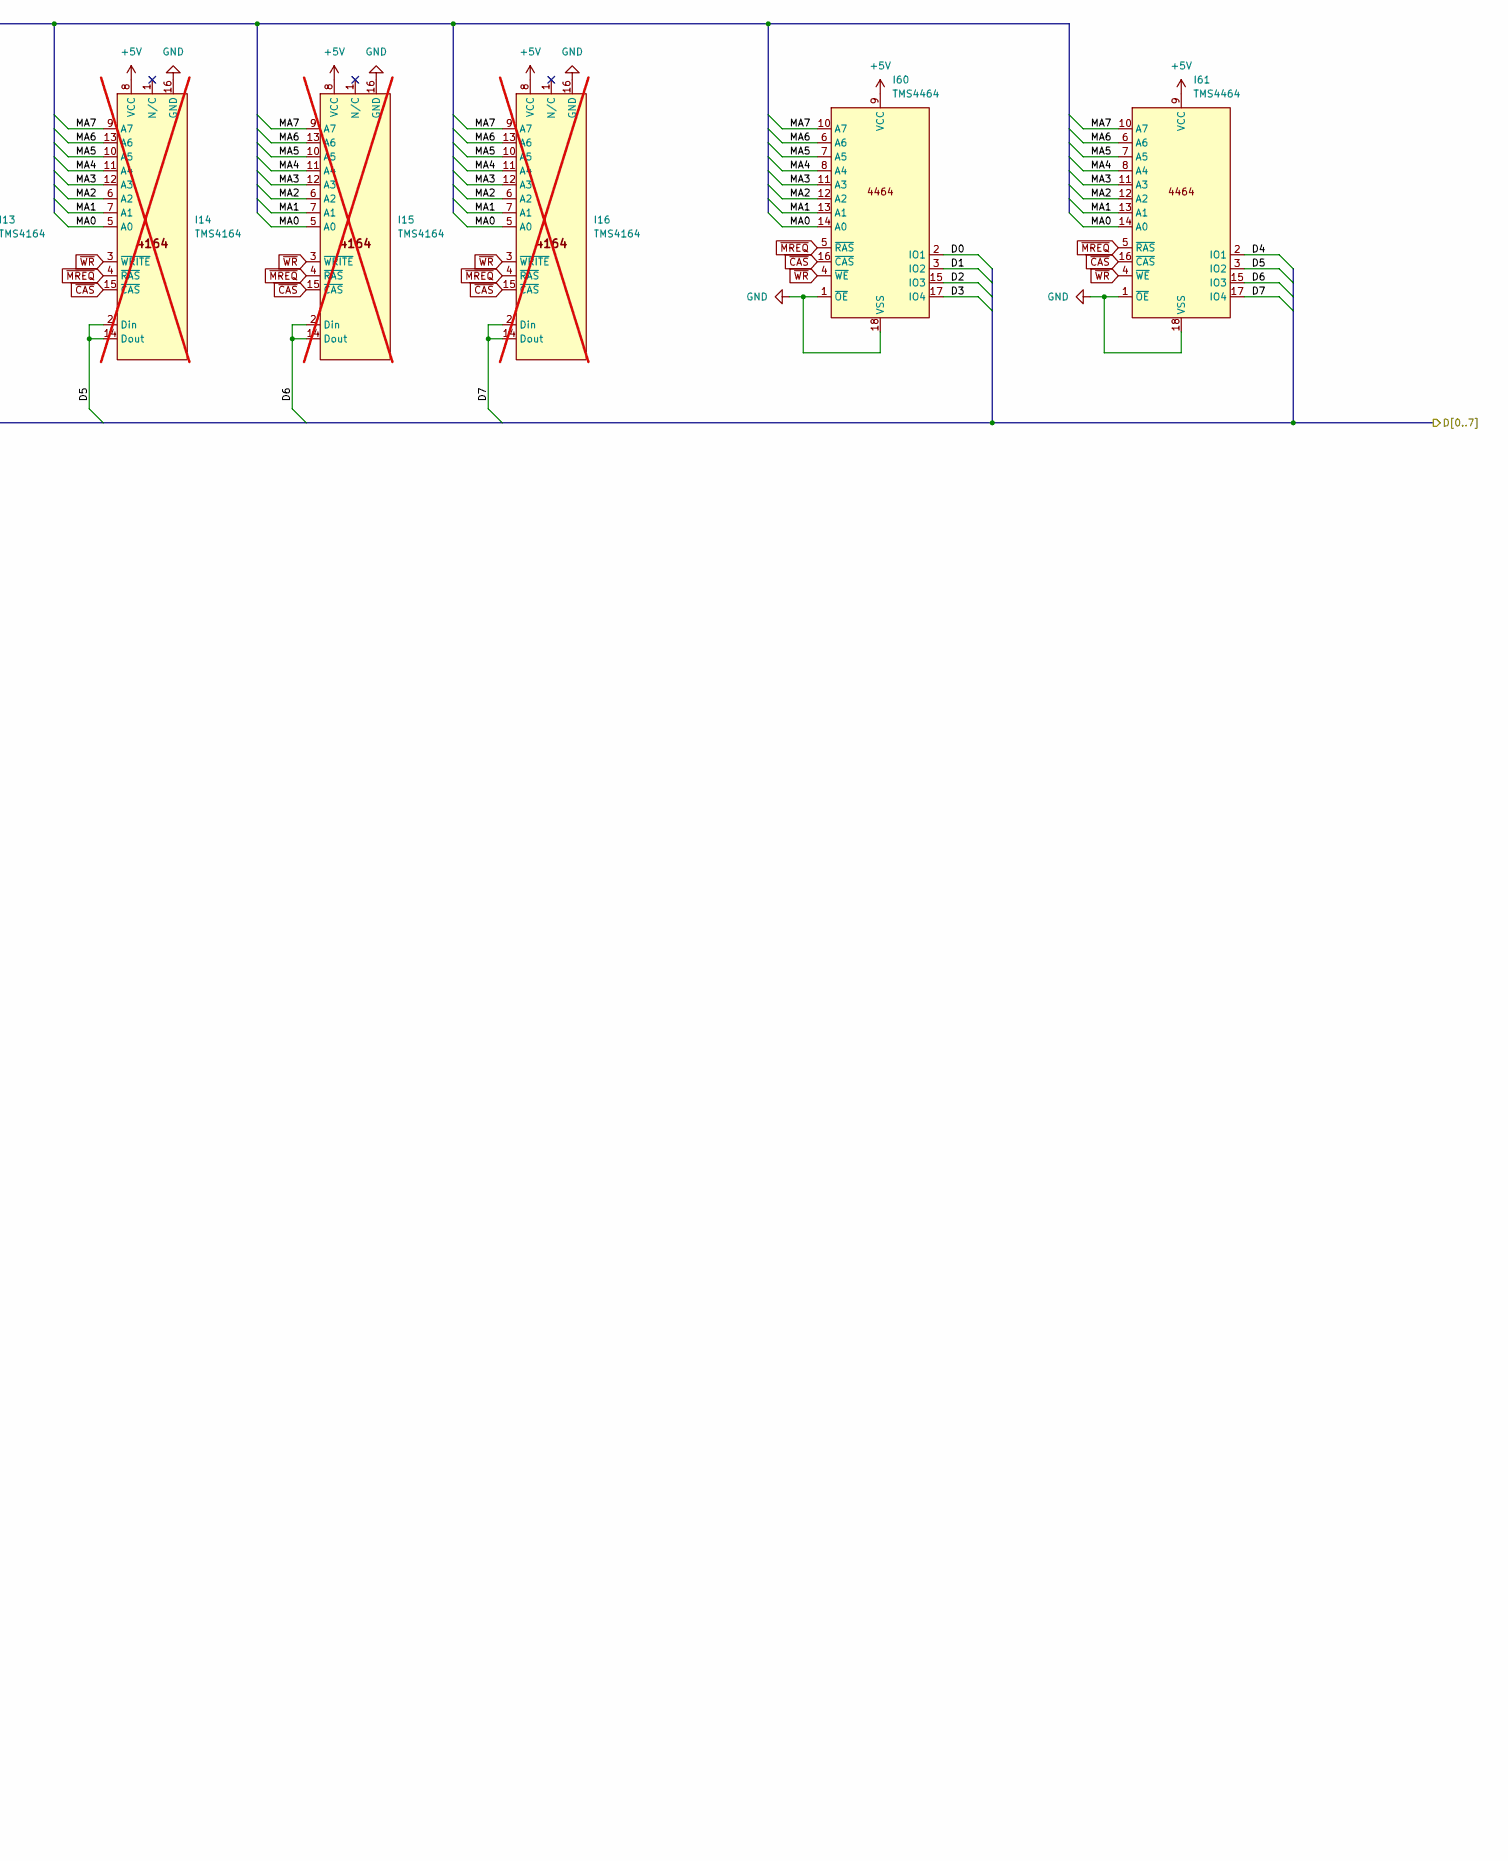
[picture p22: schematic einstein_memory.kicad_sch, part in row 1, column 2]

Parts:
I6, I7: 74LS157; DIP-16_W7.62mm
I8, I10, I11, I12, I13, I14, I15, I16: TMS4164; DIP-16_W7.62mm; not fitted
I21: 74LS04; DIP-14_W7.62mm
I23, I24: 2764/128; DIP-28_W15.24mm
I60, I61: TMS4464; DIP-18_W7.62mm
M18: ROM; M18 PinHeader_1x03_P2.54mm

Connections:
+5V: I6.16 (VCC), I7.16 (VCC), I8.8 (VCC), I10.8 (VCC), I11.8 (VCC), I12.8 (VCC), I13.8 (VCC), I14.8 (VCC), I15.8 (VCC), I16.8 (VCC), I21.14 (VCC), I23.1 (VPP), I23.27 (~PGM), I23.28 (VCC), I24.1 (VPP), I24.27 (~PGM), I24.28 (VCC), I60.9 (VCC), I61.9 (VCC), M18.1; also elsewhere on the board
/Addressing/A0: I7.3 (I1a), I23.10 (A0), I24.10 (A0); also elsewhere on the board
/Addressing/A1: I7.6 (I1b), I23.9 (A1), I24.9 (A1); also elsewhere on the board
/Addressing/A2: I7.10 (I1c), I23.8 (A2), I24.8 (A2); also elsewhere on the board
/Addressing/A3: I7.13 (I1d), I23.7 (A3), I24.7 (A3); also elsewhere on the board
/Addressing/A4: I6.3 (I1a), I23.6 (A4), I24.6 (A4); also elsewhere on the board
/Addressing/A5: I6.6 (I1b), I23.5 (A5), I24.5 (A5); also elsewhere on the board
/Addressing/A6: I6.10 (I1c), I23.4 (A6), I24.4 (A6); also elsewhere on the board
/Addressing/A7: I6.13 (I1d), I23.3 (A7), I24.3 (A7); also elsewhere on the board
/Addressing/A8: I7.2 (I0a), I23.25 (A8), I24.25 (A8); also elsewhere on the board
/Addressing/A9: I7.5 (I0b), I23.24 (A9), I24.24 (A9); also elsewhere on the board
/Addressing/A10: I7.11 (I0c), I23.21 (A10), I24.21 (A10); also elsewhere on the board
/Addressing/A11: I7.14 (I0d), I23.23 (A11), I24.23 (A11); also elsewhere on the board
/Addressing/A12: I6.2 (I0a), I23.2 (A12), I24.2 (A12); also elsewhere on the board
/Addressing/A13: I6.5 (I0b), I23.26 (A13), M18.3; also elsewhere on the board
/Addressing/A14: I6.11 (I0c); also elsewhere on the board
/Addressing/A15: I6.14 (I0d); also elsewhere on the board
/CPU and Buffers/D0: I8.2 (Din), I8.14 (Dout), I23.11 (D0), I24.11 (D0), I60.2 (IO1); also elsewhere on the board
/CPU and Buffers/D1: I10.2 (Din), I10.14 (Dout), I23.12 (D1), I24.12 (D1), I60.3 (IO2); also elsewhere on the board
/CPU and Buffers/D2: I11.2 (Din), I11.14 (Dout), I23.13 (D2), I24.13 (D2), I60.15 (IO3); also elsewhere on the board
/CPU and Buffers/D3: I12.2 (Din), I12.14 (Dout), I23.15 (D3), I24.15 (D3), I60.17 (IO4); also elsewhere on the board
/CPU and Buffers/D4: I13.2 (Din), I13.14 (Dout), I23.16 (D4), I24.16 (D4), I61.2 (IO1); also elsewhere on the board
/CPU and Buffers/D5: I14.2 (Din), I14.14 (Dout), I23.17 (D5), I24.17 (D5), I61.3 (IO2); also elsewhere on the board
/CPU and Buffers/D6: I15.2 (Din), I15.14 (Dout), I23.18 (D6), I24.18 (D6), I61.15 (IO3); also elsewhere on the board
/CPU and Buffers/D7: I16.2 (Din), I16.14 (Dout), I23.19 (D7), I24.19 (D7), I61.17 (IO4); also elsewhere on the board
/System RAM and ROM/MA0: I7.4 (Za), I8.5 (A0), I10.5 (A0), I11.5 (A0), I12.5 (A0), I13.5 (A0), I14.5 (A0), I15.5 (A0), I16.5 (A0), I60.14 (A0), I61.14 (A0)
/System RAM and ROM/MA1: I7.7 (Zb), I8.7 (A1), I10.7 (A1), I11.7 (A1), I12.7 (A1), I13.7 (A1), I14.7 (A1), I15.7 (A1), I16.7 (A1), I60.13 (A1), I61.13 (A1)
/System RAM and ROM/MA2: I7.9 (Zc), I8.6 (A2), I10.6 (A2), I11.6 (A2), I12.6 (A2), I13.6 (A2), I14.6 (A2), I15.6 (A2), I16.6 (A2), I60.12 (A2), I61.12 (A2)
/System RAM and ROM/MA3: I7.12 (Zd), I8.12 (A3), I10.12 (A3), I11.12 (A3), I12.12 (A3), I13.12 (A3), I14.12 (A3), I15.12 (A3), I16.12 (A3), I60.11 (A3), I61.11 (A3)
/System RAM and ROM/MA4: I6.4 (Za), I8.11 (A4), I10.11 (A4), I11.11 (A4), I12.11 (A4), I13.11 (A4), I14.11 (A4), I15.11 (A4), I16.11 (A4), I60.8 (A4), I61.8 (A4)
/System RAM and ROM/MA5: I6.7 (Zb), I8.10 (A5), I10.10 (A5), I11.10 (A5), I12.10 (A5), I13.10 (A5), I14.10 (A5), I15.10 (A5), I16.10 (A5), I60.7 (A5), I61.7 (A5)
/System RAM and ROM/MA6: I6.9 (Zc), I8.13 (A6), I10.13 (A6), I11.13 (A6), I12.13 (A6), I13.13 (A6), I14.13 (A6), I15.13 (A6), I16.13 (A6), I60.6 (A6), I61.6 (A6)
/System RAM and ROM/MA7: I6.12 (Zd), I8.9 (A7), I10.9 (A7), I11.9 (A7), I12.9 (A7), I13.9 (A7), I14.9 (A7), I15.9 (A7), I16.9 (A7), I60.10 (A7), I61.10 (A7)
GND: I6.8 (GND), I6.15 (E), I7.8 (GND), I7.15 (E), I8.16 (GND), I10.16 (GND), I11.16 (GND), I12.16 (GND), I13.16 (GND), I14.16 (GND), I15.16 (GND), I16.16 (GND), I21.7 (GND), I23.14 (GND), I24.14 (GND), I60.1 (~OE), I60.18 (VSS), I61.1 (~OE), I61.18 (VSS); also elsewhere on the board
unnamed: I24.26 (A13), M18.2
~CAS: I8.15 (~CAS), I10.15 (~CAS), I11.15 (~CAS), I12.15 (~CAS), I13.15 (~CAS), I14.15 (~CAS), I15.15 (~CAS), I16.15 (~CAS), I60.16 (~CAS), I61.16 (~CAS); also elsewhere on the board
~MPX: I6.1 (S), I7.1 (S); also elsewhere on the board
~MREQ: I8.4 (~RAS), I10.4 (~RAS), I11.4 (~RAS), I12.4 (~RAS), I13.4 (~RAS), I14.4 (~RAS), I15.4 (~RAS), I16.4 (~RAS), I60.5 (~RAS), I61.5 (~RAS); also elsewhere on the board
~ROM1: I23.22 (~OE); also elsewhere on the board
~ROM2: I24.22 (~OE); also elsewhere on the board
~ROMCE: I23.20 (~CE), I24.20 (~CE); also elsewhere on the board
~WR: I8.3 (~WRITE), I10.3 (~WRITE), I11.3 (~WRITE), I12.3 (~WRITE), I13.3 (~WRITE), I14.3 (~WRITE), I15.3 (~WRITE), I16.3 (~WRITE), I60.4 (~WE), I61.4 (~WE); also elsewhere on the board

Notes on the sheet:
LINK?

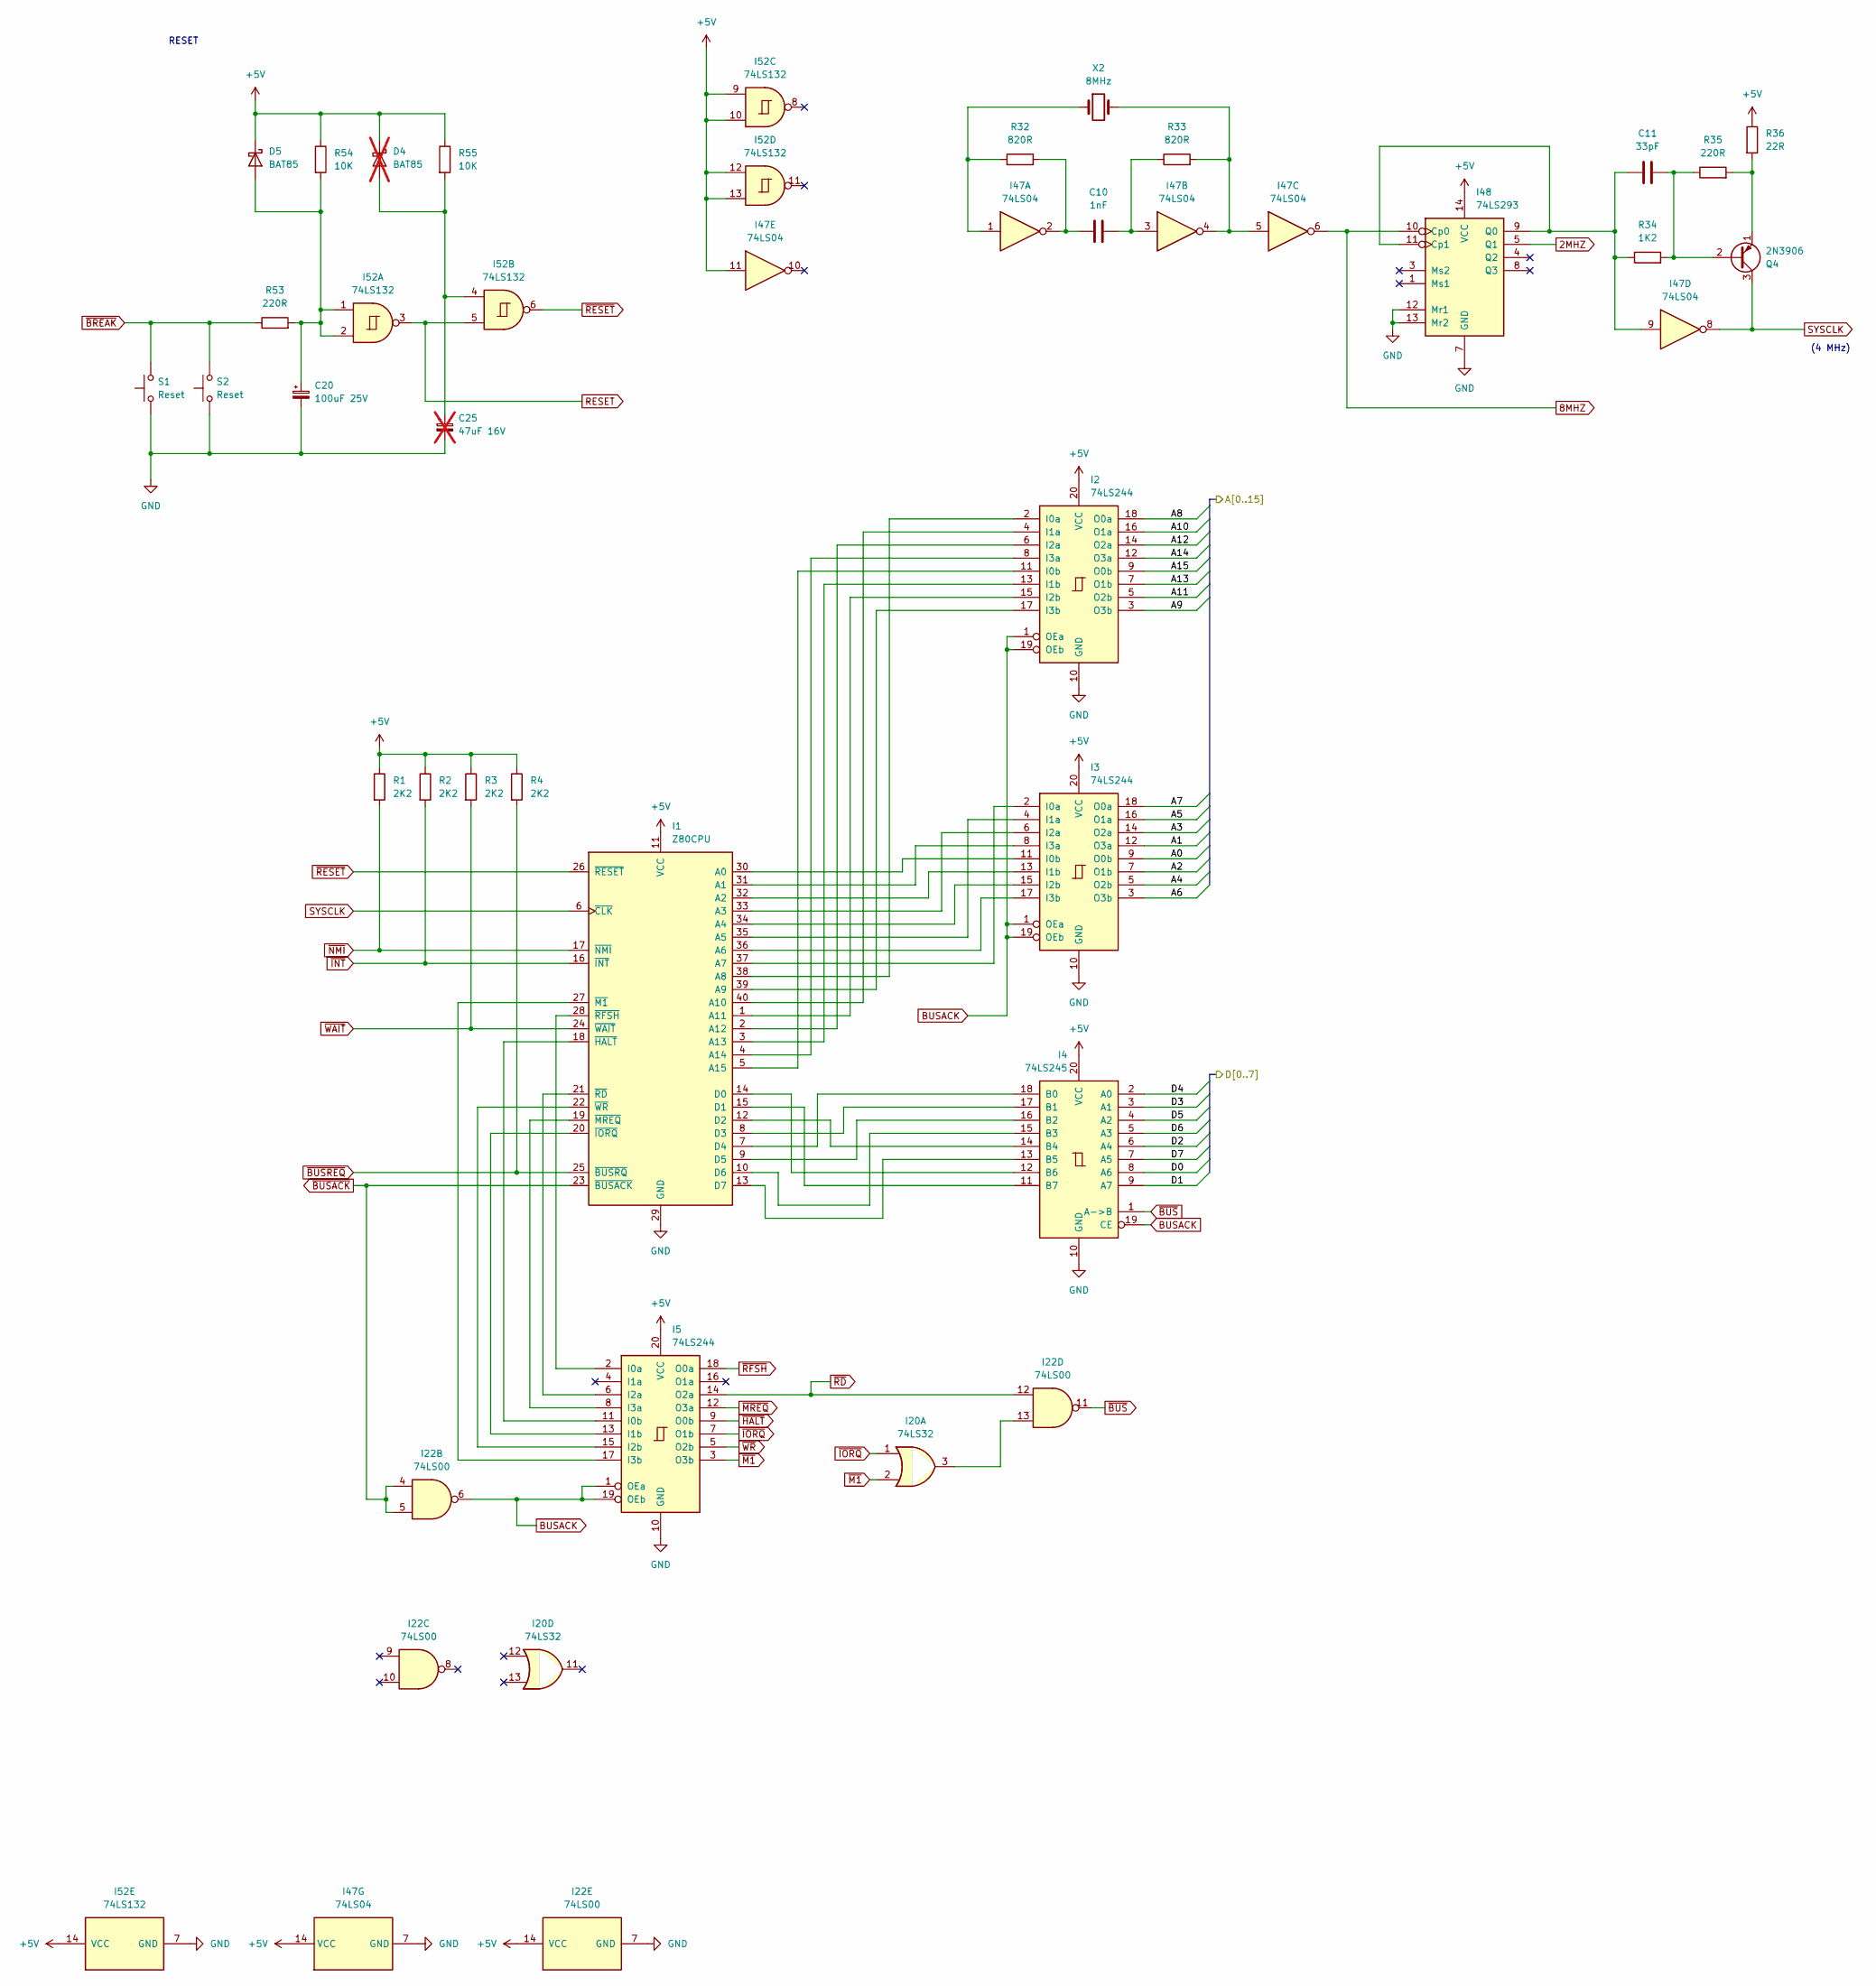
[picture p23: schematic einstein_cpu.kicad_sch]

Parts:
C10: 1nF; C_Disc_5.08mm
C11: 33pF; C_Disc_5.08mm
C20: 100uF 25V; Elec_5.08mm - Box
C25: 47uF 16V; Elec_5.08mm - Box; not fitted
D4: BAT85; Diode 10.16mm; not fitted
D5: BAT85; Diode 10.16mm
I1: Z80CPU; DIP-40_W15.24mm
I2, I3, I5: 74LS244; DIP-20_W7.62mm
I4: 74LS245; DIP-20_W7.62mm
I20: 74LS32; DIP-14_W7.62mm
I22: 74LS00; DIP-14_W7.62mm
I47: 74LS04; DIP-14_W7.62mm
I48: 74LS293; DIP-14_W7.62mm
I52: 74LS132; DIP-14_W7.62mm
Q4: 2N3906; Transistor - Box 1 (Alt 1+3) No corner marking
R1, R2, R3, R4: 2K2; Resistor 10.16mm
R32, R33: 820R; Resistor 10.16mm
R34: 1K2; Resistor 10.16mm
R35, R53: 220R; Resistor 10.16mm
R36: 22R; Resistor 10.16mm
R54, R55: 10K; Resistor 10.16mm
S1: Reset; SW_Tactile_SPST_Angled_PTS645Vx58-2LFS_RESET
S2: Reset; LK 2-pin 2.54mm - No Box
X2: 8MHz; Crystal

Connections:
2MHZ: I48.5 (Q1); also elsewhere on the board
8MHZ: I47.6, I48.10 (Cp0); also elsewhere on the board
+5V: D4.1 (K), D5.1 (K), I1.11 (VCC), I2.20 (VCC), I3.20 (VCC), I4.20 (VCC), I5.20 (VCC), I22.14 (VCC), I47.11, I47.14 (VCC), I48.14 (VCC), I52.9, I52.10, I52.12, I52.13, I52.14 (VCC), R1.1, R2.1, R3.1, R4.1, R36.1, R54.1, R55.1; also elsewhere on the board
/Addressing/A0: I3.9 (O0b); also elsewhere on the board
/Addressing/A1: I3.12 (O3a); also elsewhere on the board
/Addressing/A2: I3.7 (O1b); also elsewhere on the board
/Addressing/A3: I3.14 (O2a); also elsewhere on the board
/Addressing/A4: I3.5 (O2b); also elsewhere on the board
/Addressing/A5: I3.16 (O1a); also elsewhere on the board
/Addressing/A6: I3.3 (O3b); also elsewhere on the board
/Addressing/A7: I3.18 (O0a); also elsewhere on the board
/Addressing/A8: I2.18 (O0a); also elsewhere on the board
/Addressing/A9: I2.3 (O3b); also elsewhere on the board
/Addressing/A10: I2.16 (O1a); also elsewhere on the board
/Addressing/A11: I2.5 (O2b); also elsewhere on the board
/Addressing/A12: I2.14 (O2a); also elsewhere on the board
/Addressing/A13: I2.7 (O1b); also elsewhere on the board
/Addressing/A14: I2.12 (O3a); also elsewhere on the board
/Addressing/A15: I2.9 (O0b); also elsewhere on the board
/CPU and Buffers/D0: I4.8 (A6); also elsewhere on the board
/CPU and Buffers/D1: I4.9 (A7); also elsewhere on the board
/CPU and Buffers/D2: I4.6 (A4); also elsewhere on the board
/CPU and Buffers/D3: I4.3 (A1); also elsewhere on the board
/CPU and Buffers/D4: I4.2 (A0); also elsewhere on the board
/CPU and Buffers/D5: I4.4 (A2); also elsewhere on the board
/CPU and Buffers/D6: I4.5 (A3); also elsewhere on the board
/CPU and Buffers/D7: I4.7 (A5); also elsewhere on the board
BUSACK: I2.1 (OEa), I2.19 (OEb), I3.1 (OEa), I3.19 (OEb), I4.19 (CE), I5.1 (OEa), I5.19 (OEb), I22.6
GND: C20.2, C25.2, I1.29 (GND), I2.10 (GND), I3.10 (GND), I4.10 (GND), I5.10 (GND), I22.7 (GND), I47.7 (GND), I48.7 (GND), I48.12 (Mr1), I48.13 (Mr2), I52.7 (GND), S1.1, S2.1; also elsewhere on the board
unnamed: C10.1, I47.3, R33.1
unnamed: C10.2, I47.2, R32.1
unnamed: C25.1, D4.2 (A), I52.4, R55.2
unnamed: C20.1, D5.2 (A), I52.1, I52.2, R53.2, R54.2
unnamed: I1.30 (A0), I3.11 (I0b)
unnamed: I1.31 (A1), I3.8 (I3a)
unnamed: I1.32 (A2), I3.13 (I1b)
unnamed: I1.33 (A3), I3.6 (I2a)
unnamed: I1.34 (A4), I3.15 (I2b)
unnamed: I1.35 (A5), I3.4 (I1a)
unnamed: I1.36 (A6), I3.17 (I3b)
unnamed: I1.37 (A7), I3.2 (I0a)
unnamed: I1.38 (A8), I2.2 (I0a)
unnamed: I1.39 (A9), I2.17 (I3b)
unnamed: I1.40 (A10), I2.4 (I1a)
unnamed: I1.1 (A11), I2.15 (I2b)
unnamed: I1.2 (A12), I2.6 (I2a)
unnamed: I1.3 (A13), I2.13 (I1b)
unnamed: I1.4 (A14), I2.8 (I3a)
unnamed: I1.5 (A15), I2.11 (I0b)
unnamed: I1.14 (D0), I4.12 (B6)
unnamed: I1.15 (D1), I4.11 (B7)
unnamed: I1.12 (D2), I4.14 (B4)
unnamed: I1.8 (D3), I4.17 (B1)
unnamed: I1.7 (D4), I4.18 (B0)
unnamed: I1.9 (D5), I4.16 (B2)
unnamed: I1.10 (D6), I4.15 (B3)
unnamed: I1.13 (D7), I4.13 (B5)
unnamed: I1.18 (~HALT), I5.11 (I0b)
unnamed: I1.20 (~IORQ), I5.13 (I1b)
unnamed: I1.27 (~M1), I5.17 (I3b)
unnamed: I1.19 (~MREQ), I5.8 (I3a)
unnamed: I1.21 (~RD), I5.6 (I2a)
unnamed: I1.28 (~RFSH), I5.2 (I0a)
unnamed: I1.22 (~WR), I5.15 (I2b)
unnamed: I20.3, I22.13
unnamed: I47.1, R32.2, X2.1
unnamed: I47.4, I47.5, R33.2, X2.2
unnamed: C11.2, I47.9, I48.9 (Q0), I48.11 (Cp1), R34.1
unnamed: C11.1, Q4.2 (B), R34.2, R35.1
unnamed: Q4.1 (E), R35.2, R36.2
RESET: I52.3, I52.5; also elsewhere on the board
SYSCLK: I1.6 (~CLK), I47.8, Q4.3 (C); also elsewhere on the board
~BREAK: R53.1, S1.2, S2.2; also elsewhere on the board
~BUSACK: I1.23 (~BUSACK), I22.4, I22.5; also elsewhere on the board
~BUSREQ: I1.25 (~BUSRQ), R4.2; also elsewhere on the board
~BUS: I4.1 (A->B), I22.11
~HALT: I5.9 (O0b); also elsewhere on the board
~INT: I1.16 (~INT), R2.2; also elsewhere on the board
~IORQ: I5.7 (O1b), I20.1; also elsewhere on the board
~M1: I5.3 (O3b), I20.2; also elsewhere on the board
~MREQ: I5.12 (O3a); also elsewhere on the board
~NMI: I1.17 (~NMI), R1.2; also elsewhere on the board
~RD: I5.14 (O2a), I22.12; also elsewhere on the board
~RESET: I1.26 (~RESET), I52.6; also elsewhere on the board
~RFSH: I5.18 (O0a); also elsewhere on the board
~WAIT: I1.24 (~WAIT), R3.2; also elsewhere on the board
~WR: I5.5 (O2b); also elsewhere on the board

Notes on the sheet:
(4 MHz)
RESET

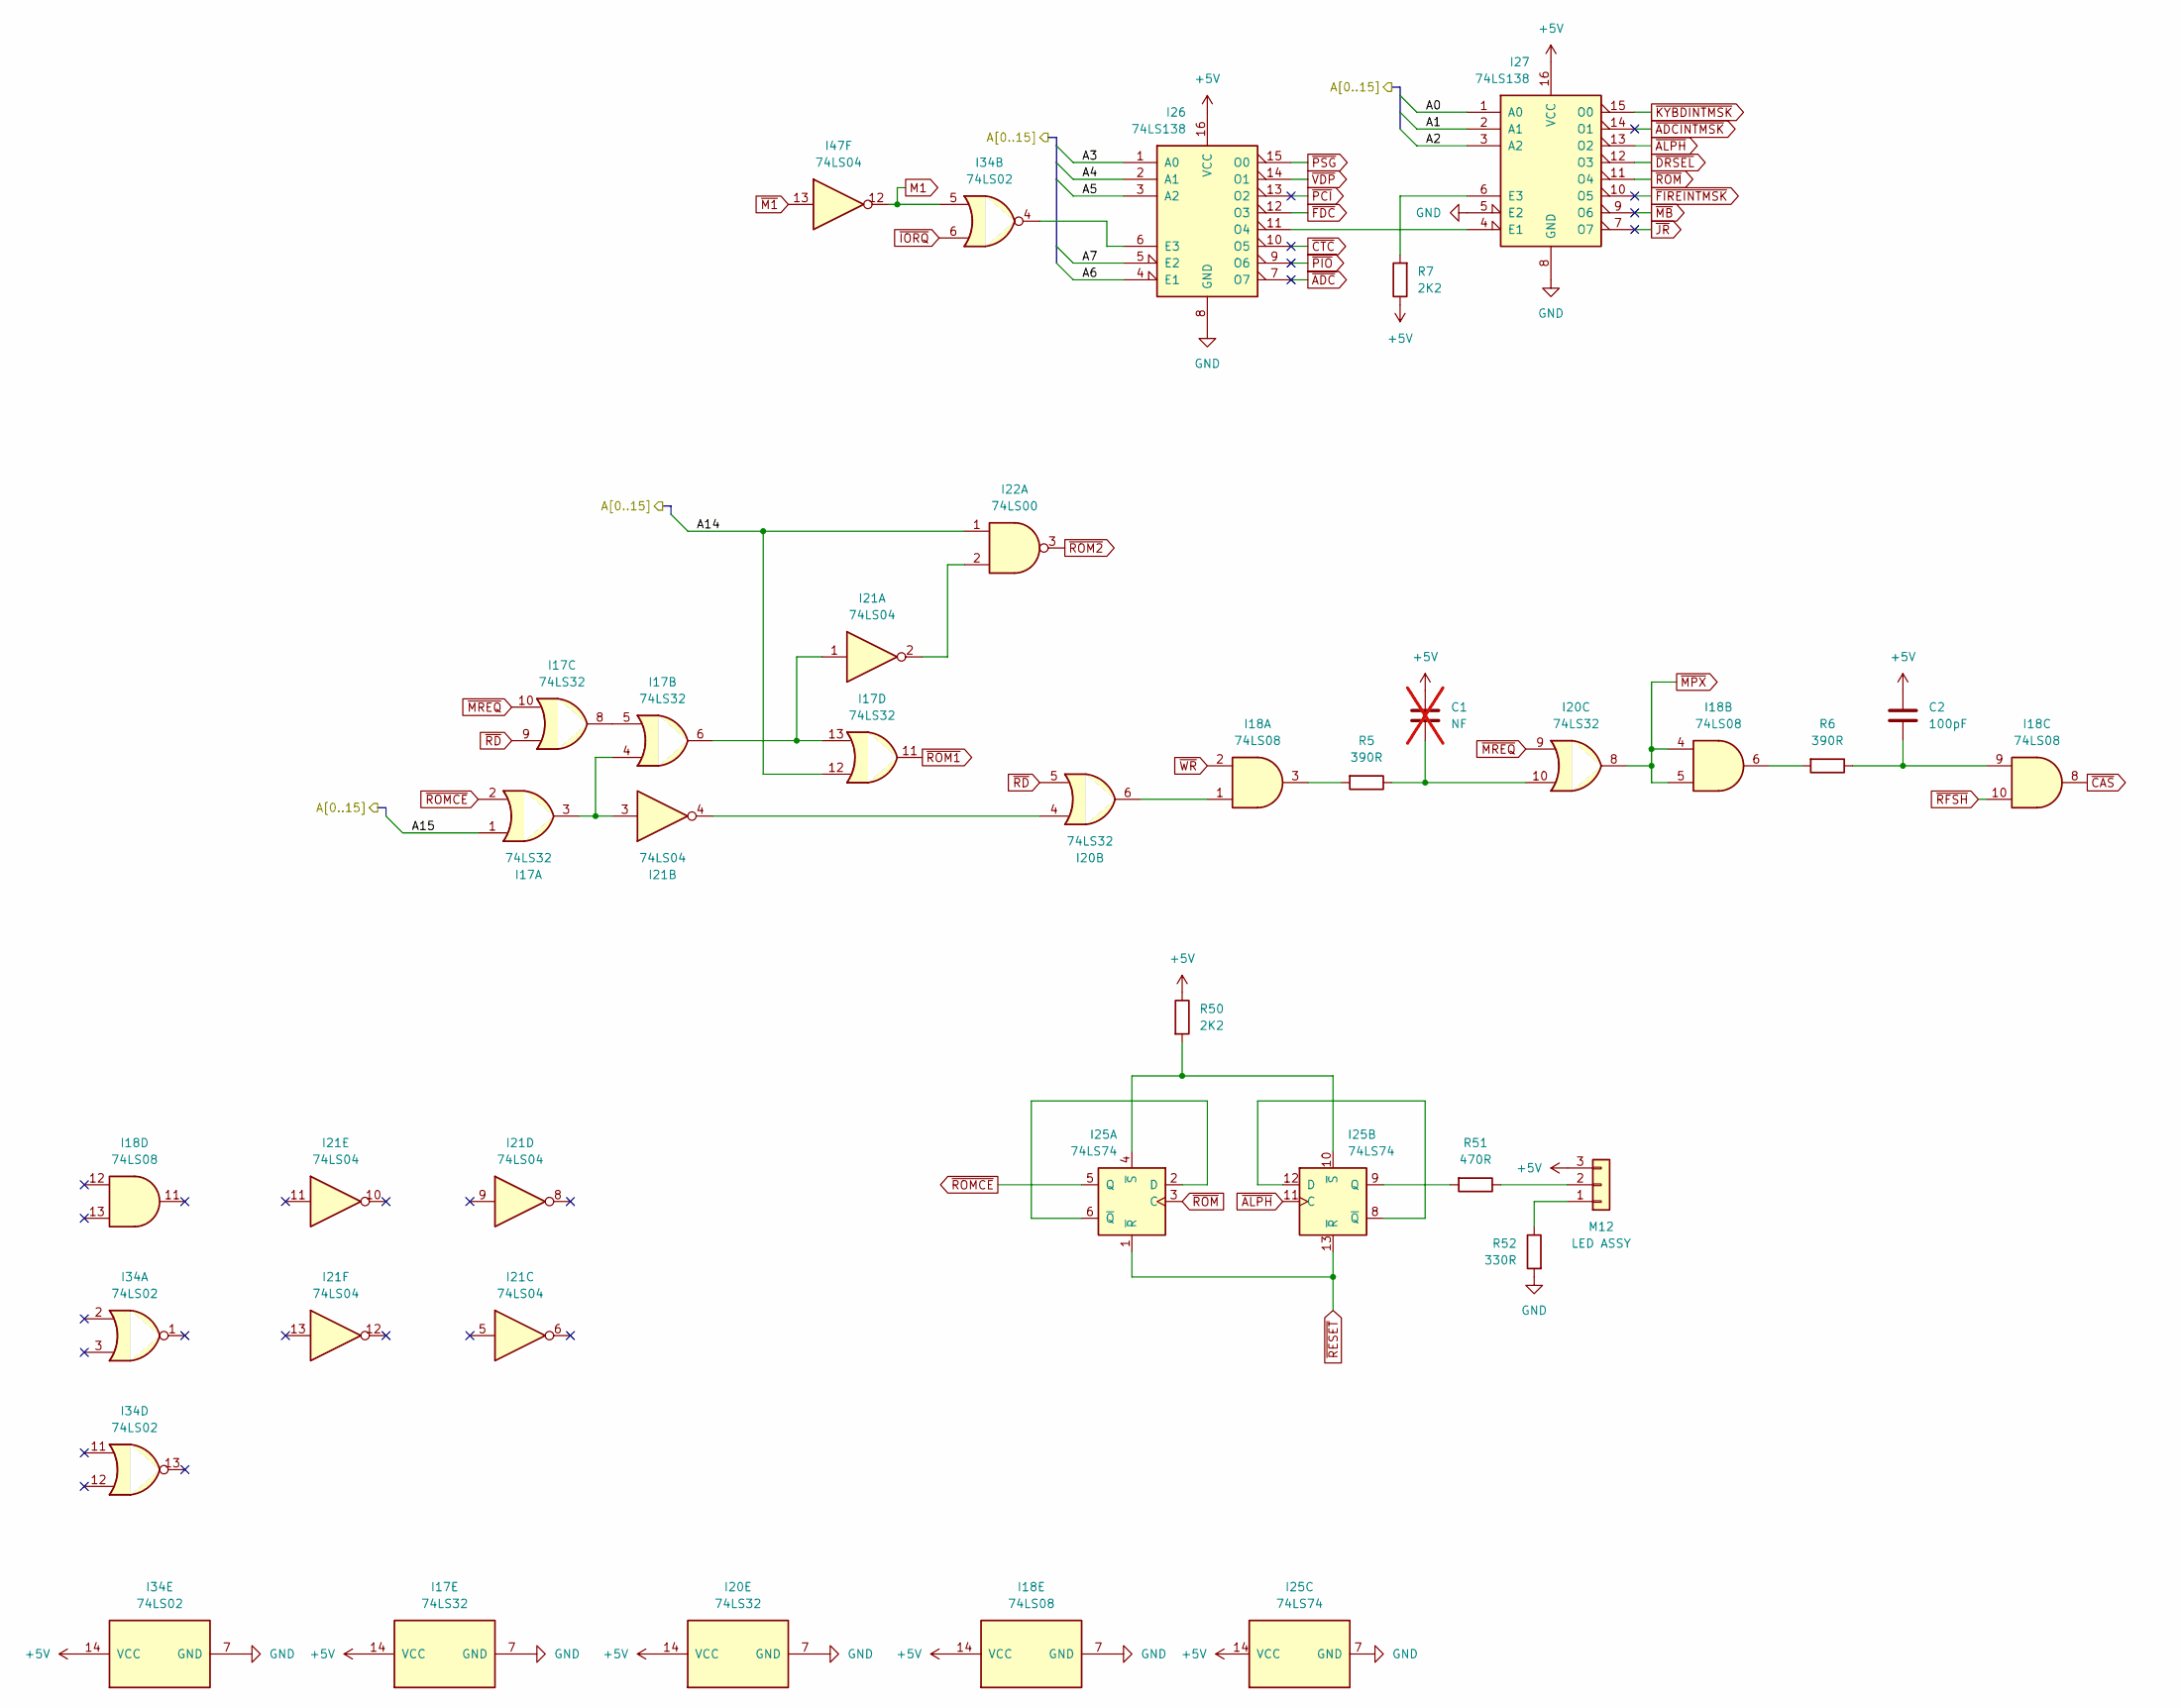
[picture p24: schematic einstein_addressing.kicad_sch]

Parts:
C1: NF; C_Disc_5.08mm; not fitted
C2: 100pF; C_Disc_5.08mm
I17, I20: 74LS32; DIP-14_W7.62mm
I18: 74LS08; DIP-14_W7.62mm
I21, I47: 74LS04; DIP-14_W7.62mm
I22: 74LS00; DIP-14_W7.62mm
I25: 74LS74; DIP-14_W7.62mm
I26, I27: 74LS138; DIP-16_W7.62mm
I34: 74LS02; DIP-14_W7.62mm
M12: LED ASSY; M12 PinHeader_1x03_P2.54mm
R5, R6: 390R; Resistor 10.16mm
R7, R50: 2K2; Resistor 10.16mm
R51: 470R; Resistor 10.16mm
R52: 330R; Resistor 10.16mm

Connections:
+5V: C1.1, C2.1, I17.14 (VCC), I18.14 (VCC), I20.14 (VCC), I25.14 (VCC), I26.16 (VCC), I27.16 (VCC), I34.14 (VCC), M12.3, R7.1, R50.1; also elsewhere on the board
/Addressing/A0: I27.1 (A0); also elsewhere on the board
/Addressing/A1: I27.2 (A1); also elsewhere on the board
/Addressing/A2: I27.3 (A2); also elsewhere on the board
/Addressing/A3: I26.1 (A0); also elsewhere on the board
/Addressing/A4: I26.2 (A1); also elsewhere on the board
/Addressing/A5: I26.3 (A2); also elsewhere on the board
/Addressing/A6: I26.4 (E1); also elsewhere on the board
/Addressing/A7: I26.5 (E2); also elsewhere on the board
/Addressing/A14: I17.12, I22.1; also elsewhere on the board
/Addressing/A15: I17.1; also elsewhere on the board
GND: I17.7 (GND), I18.7 (GND), I20.7 (GND), I25.7 (GND), I26.8 (GND), I27.5 (E2), I27.8 (GND), I34.7 (GND), R52.2; also elsewhere on the board
M1: I34.5, I47.12
unnamed: C1.2, I20.10, R5.1
unnamed: C2.2, I18.9, R6.1
unnamed: I17.3, I17.4, I21.3
unnamed: I17.5, I17.8
unnamed: I17.6, I17.13, I21.1
unnamed: I18.1, I20.6
unnamed: I18.3, R5.2
unnamed: I18.6, R6.2
unnamed: I20.4, I21.4
unnamed: I21.2, I22.2
unnamed: I25.2 (D), I25.6 (~Q)
unnamed: I25.4 (~S), I25.10 (~S), R50.2
unnamed: I25.8 (~Q), I25.12 (D)
unnamed: I25.9 (Q), R51.2
unnamed: I26.6 (E3), I34.4
unnamed: I26.11 (O4), I27.4 (E1)
unnamed: I27.6 (E3), R7.2
unnamed: M12.1, R52.1
unnamed: M12.2, R51.1
~ADCINTMSK: I27.14 (O1)
~ADC: I26.7 (O7)
~ALPH: I25.11 (C), I27.13 (O2)
~CAS: I18.8; also elsewhere on the board
~CTC: I26.10 (O5)
~DRSEL: I27.12 (O3); also elsewhere on the board
~FDC: I26.12 (O3); also elsewhere on the board
~FIREINTMSK: I27.10 (O5)
~IORQ: I34.6; also elsewhere on the board
~JR: I27.7 (O7)
~KYBDINTMSK: I27.15 (O0); also elsewhere on the board
~M1: I47.13; also elsewhere on the board
~MB: I27.9 (O6)
~MPX: I18.4, I18.5, I20.8; also elsewhere on the board
~MREQ: I17.10, I20.9; also elsewhere on the board
~PCI: I26.13 (O2)
~PIO: I26.9 (O6)
~PSG: I26.15 (O0); also elsewhere on the board
~RD: I17.9, I20.5; also elsewhere on the board
~RESET: I25.1 (~R), I25.13 (~R); also elsewhere on the board
~RFSH: I18.10; also elsewhere on the board
~ROM1: I17.11; also elsewhere on the board
~ROM2: I22.3; also elsewhere on the board
~ROMCE: I17.2, I25.5 (Q); also elsewhere on the board
~ROM: I25.3 (C), I27.11 (O4)
~VDP: I26.14 (O1); also elsewhere on the board
~WR: I18.2; also elsewhere on the board

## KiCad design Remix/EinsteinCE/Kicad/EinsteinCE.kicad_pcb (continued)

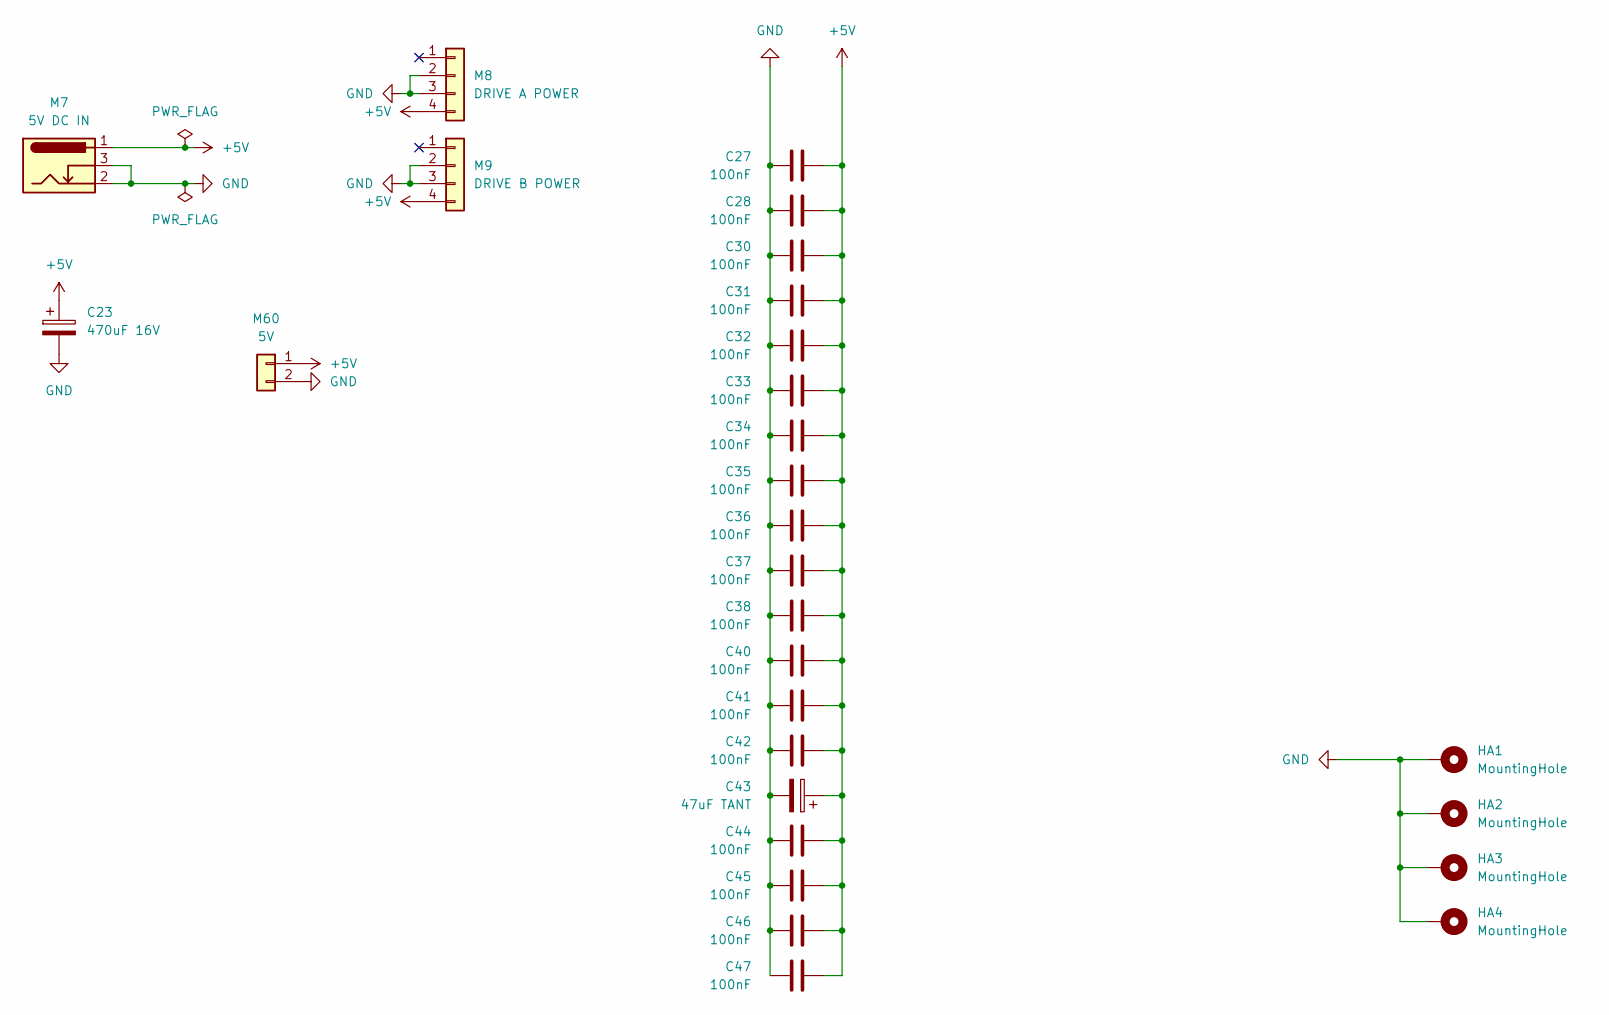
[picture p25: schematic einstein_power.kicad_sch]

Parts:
C23: 470uF 16V; Elec_5.08mm - Big Box
C27, C28, C30, C31, C32, C33, C34, C35, C36, C37, C38, C40, C41, C42, C44, C45, C46, C47: 100nF; C_Disc_5.08mm
C43: 47uF TANT; Elec_2.5mm - Box
HA1, HA2, HA3, HA4: MountingHole; Hole3.81_Pad_Via
M7: 5V DC IN; BarrelJack_Horizontal
M8: DRIVE A POWER; M10 PinHeader_1x04_P2.54mm
M9: DRIVE B POWER; M10 PinHeader_1x04_P2.54mm
M60: 5V; Power Header 3.96mm

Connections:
+5V: C23.1, C27.2, C28.2, C30.2, C31.2, C32.2, C33.2, C34.2, C35.2, C36.2, C37.2, C38.2, C40.2, C41.2, C42.2, C43.1, C44.2, C45.2, C46.2, C47.2, M7.1, M8.4, M9.4, M60.1; also elsewhere on the board
GND: C23.2, C27.1, C28.1, C30.1, C31.1, C32.1, C33.1, C34.1, C35.1, C36.1, C37.1, C38.1, C40.1, C41.1, C42.1, C43.2, C44.1, C45.1, C46.1, C47.1, HA1.1, HA2.1, HA3.1, HA4.1, M7.2, M7.3, M8.2, M8.3, M9.2, M9.3, M60.2; also elsewhere on the board

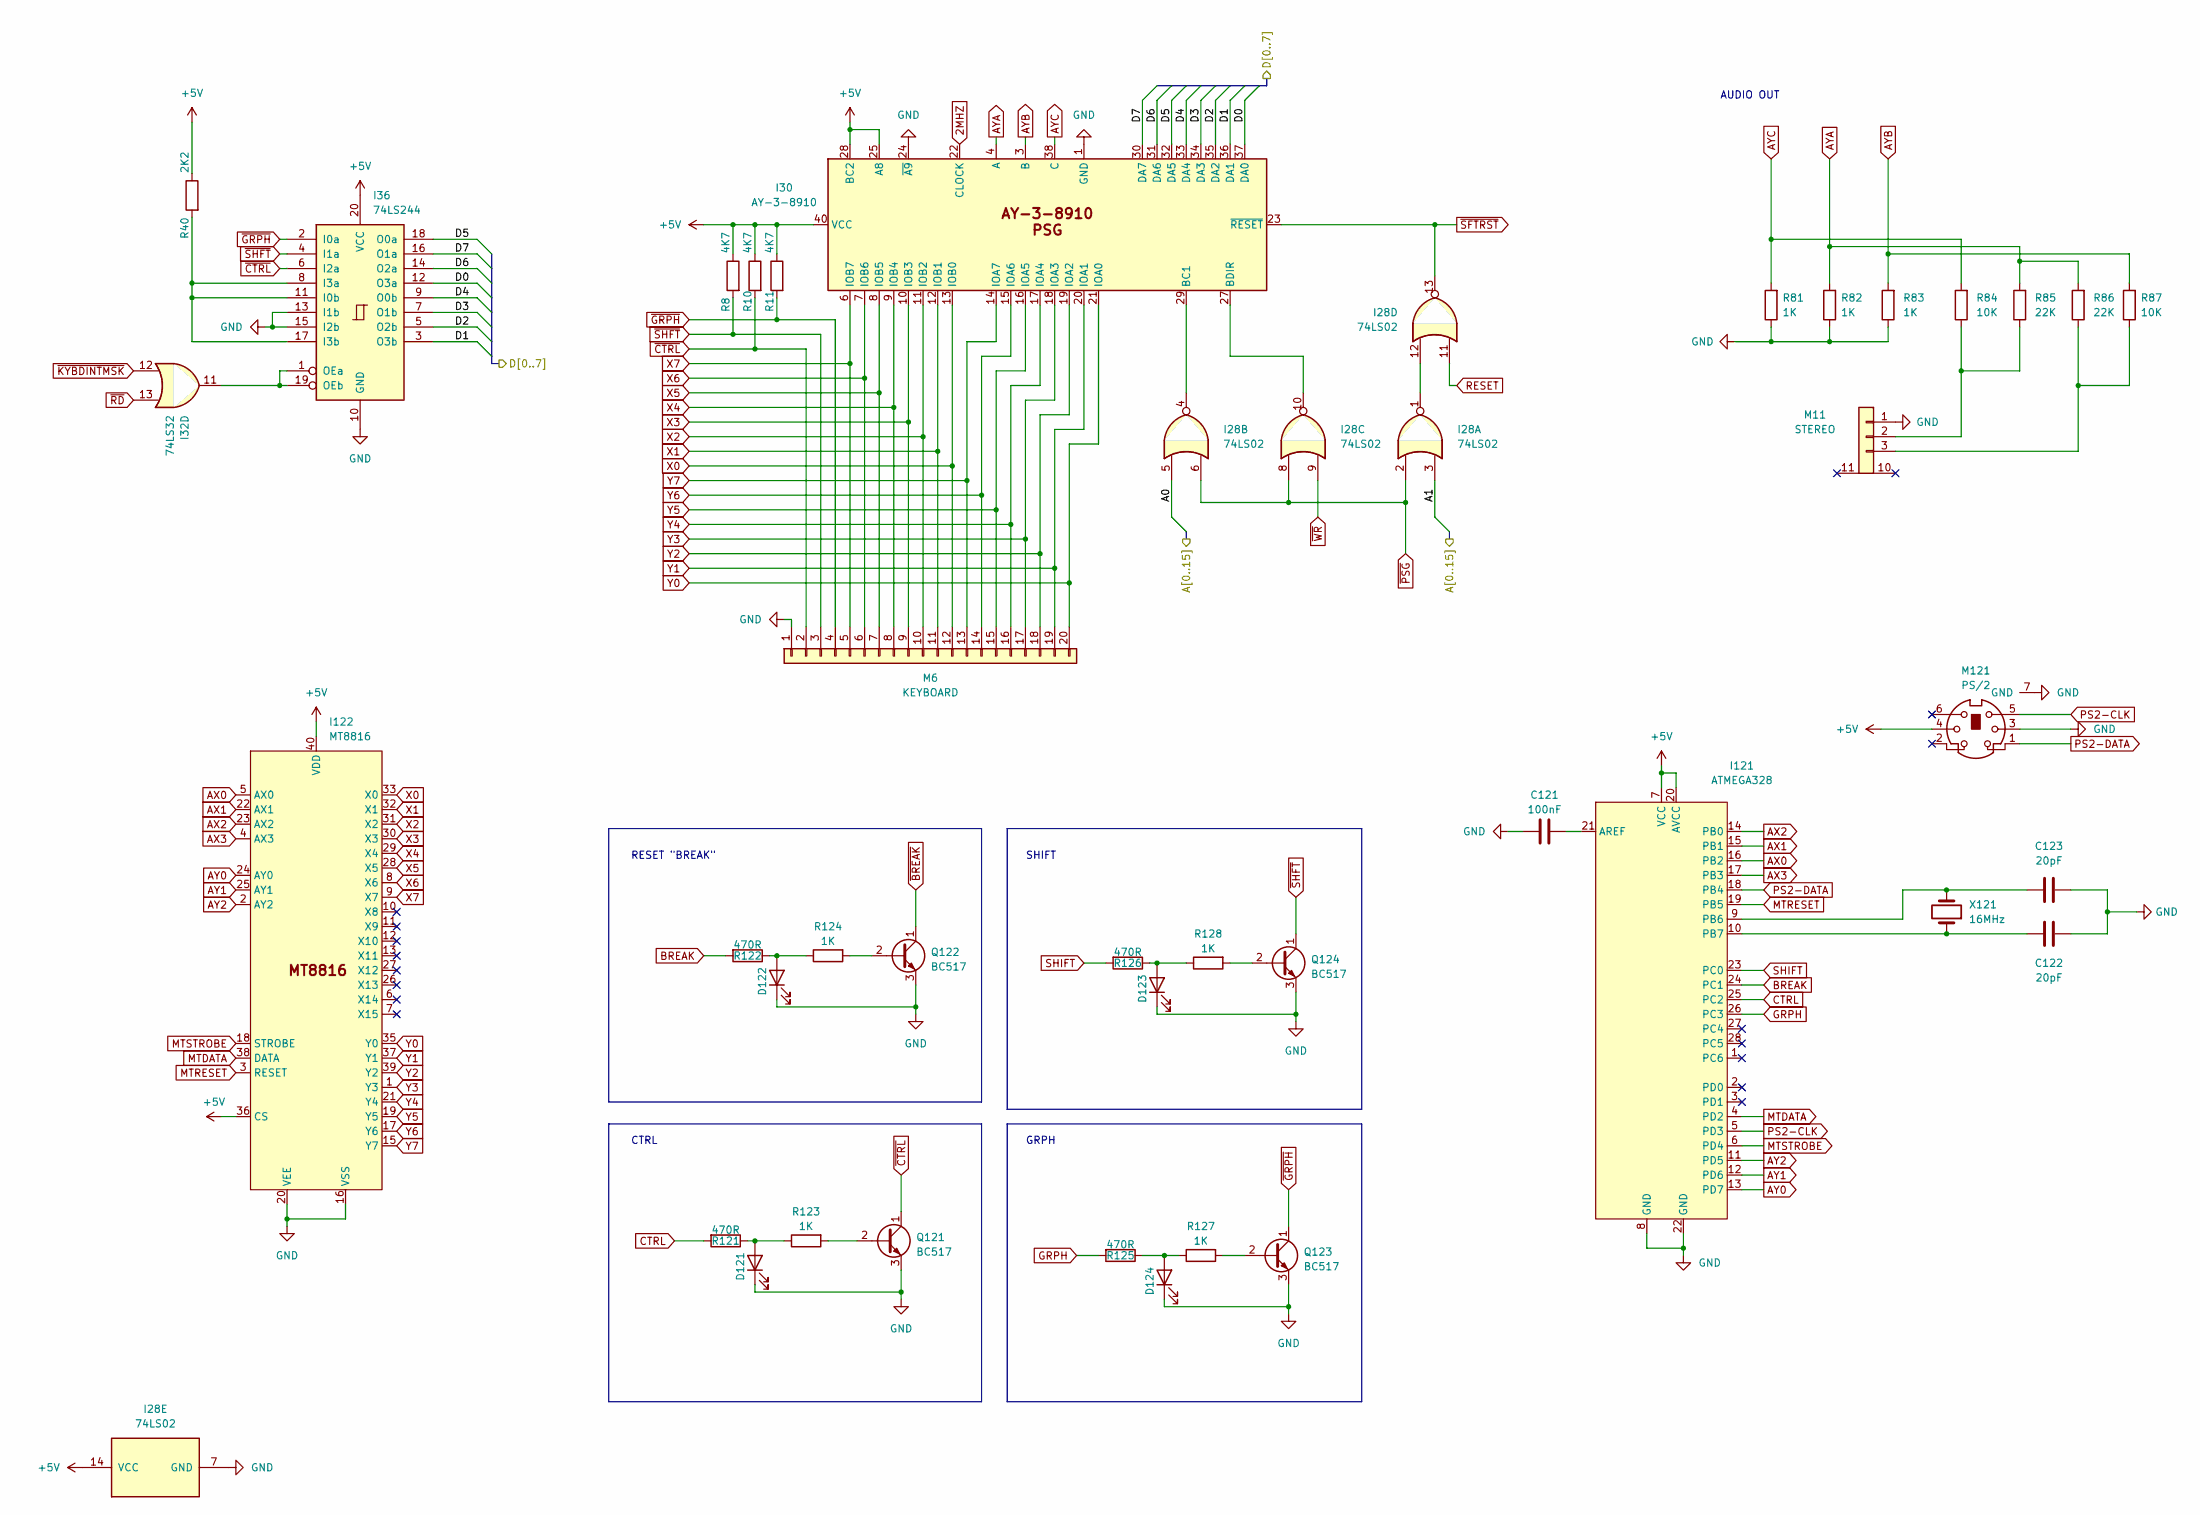
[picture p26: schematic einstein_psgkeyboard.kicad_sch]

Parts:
C121: 100nF; C_Disc_5.08mm
C122, C123: 20pF; C_Disc_2.54mm
D121: CTRL; LED_D3.0mm
D122: RESET; LED_D3.0mm
D123: SHIFT; LED_D3.0mm
D124: GRPH; LED_D3.0mm
I28: 74LS02; DIP-14_W7.62mm
I30: AY-3-8910; DIP-40_W15.24mm
I32: 74LS32; DIP-14_W7.62mm
I36: 74LS244; DIP-20_W7.62mm
I121: ATMEGA328; DIP-28_W7.62mm
I122: MT8816; DIP-40_W15.24mm
M6: KEYBOARD; Keyboard
M11: STEREO; Stereo_Jack
M121: PS/2; Connector_Mini-DIN_Female_6Pin_2rows
Q121, Q122, Q123, Q124: BC517; Transistor - Box 1 (Leg Rear)
R8, R10, R11: 4K7; Resistor 10.16mm
R40: 2K2; Resistor 10.16mm
R81, R82, R83: 1K; Resistor 10.16mm; LCSC C482939
R84, R87: 10K; Resistor 10.16mm; LCSC C84376
R85, R86: 22K; Resistor 10.16mm; LCSC C114565
R121, R122, R125, R126: 470R; Resistor 10.16mm
R123, R124, R127, R128: 1K; Resistor 10.16mm
X121: 16MHz; Crystal

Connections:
2MHZ: I30.22 (CLOCK); also elsewhere on the board
+5V: I28.14 (VCC), I30.25 (A8), I30.28 (BC2), I30.40 (VCC), I36.20 (VCC), I121.7 (VCC), I121.20 (AVCC), I122.36 (CS), I122.40 (VDD), M121.4, R8.1, R10.1, R11.1, R40.1; also elsewhere on the board
/Addressing/A0: I28.5; also elsewhere on the board
/Addressing/A1: I28.3; also elsewhere on the board
/CPU and Buffers/D0: I30.37 (DA0), I36.12 (O3a); also elsewhere on the board
/CPU and Buffers/D1: I30.36 (DA1), I36.3 (O3b); also elsewhere on the board
/CPU and Buffers/D2: I30.35 (DA2), I36.5 (O2b); also elsewhere on the board
/CPU and Buffers/D3: I30.34 (DA3), I36.7 (O1b); also elsewhere on the board
/CPU and Buffers/D4: I30.33 (DA4), I36.9 (O0b); also elsewhere on the board
/CPU and Buffers/D5: I30.32 (DA5), I36.18 (O0a); also elsewhere on the board
/CPU and Buffers/D6: I30.31 (DA6), I36.14 (O2a); also elsewhere on the board
/CPU and Buffers/D7: I30.30 (DA7), I36.16 (O1a); also elsewhere on the board
AX0: I121.16 (PB2), I122.5 (AX0)
AX1: I121.15 (PB1), I122.22 (AX1)
AX2: I121.14 (PB0), I122.23 (AX2)
AX3: I121.17 (PB3), I122.4 (AX3)
AY0: I121.13 (PD7), I122.24 (AY0)
AY1: I121.12 (PD6), I122.25 (AY1)
AY2: I121.11 (PD5), I122.2 (AY2)
AYA: I30.4 (A), R82.2, R85.2, R86.2
AYB: I30.3 (B), R83.2, R87.2
AYC: I30.38 (C), R81.2, R84.2
BREAK: I121.24 (PC1), R122.2
CTRL: I121.25 (PC2), R121.2
GND: C121.1, C122.2, C123.2, D121.1 (K), D122.1 (K), D123.1 (K), D124.1 (K), I28.7 (GND), I30.1 (GND), I30.24 (~A9), I36.10 (GND), I36.13 (I1b), I36.15 (I2b), I121.8 (GND), I121.22 (GND), I122.16 (VSS), I122.20 (VEE), M6.1, M11.1, M121.3, M121.7 (GND), Q121.3 (E), Q122.3 (E), Q123.3 (E), Q124.3 (E), R81.1, R82.1, R83.1; also elsewhere on the board
GRPH: I121.26 (PC3), R125.2
MTDATA: I121.4 (PD2), I122.38 (DATA)
MTRESET: I121.19 (PB5), I122.3 (RESET)
MTSTROBE: I121.6 (PD4), I122.18 (STROBE)
unnamed: D121.2 (A), R121.1, R123.1
unnamed: D122.2 (A), R122.1, R124.1
unnamed: D123.2 (A), R126.1, R128.1
unnamed: D124.2 (A), R125.1, R127.1
unnamed: I28.1, I28.12
unnamed: I28.4, I30.29 (BC1)
unnamed: I28.10, I30.27 (BDIR)
unnamed: I36.8 (I3a), I36.11 (I0b), I36.17 (I3b), R40.2
unnamed: I32.11, I36.1 (OEa), I36.19 (OEb)
unnamed: C121.2, I121.21 (AREF)
unnamed: C123.1, I121.9 (PB6), X121.2
unnamed: C122.1, I121.10 (PB7), X121.1
unnamed: M11.3 (Ground), R86.1, R87.1
unnamed: M11.2, R84.1, R85.1
unnamed: Q121.2 (B), R123.2
unnamed: Q122.2 (B), R124.2
unnamed: Q123.2 (B), R127.2
unnamed: Q124.2 (B), R128.2
PS2-CLK: I121.5 (PD3), M121.5
PS2-DATA: I121.18 (PB4), M121.1
RESET: I28.11; also elsewhere on the board
SHIFT: I121.23 (PC0), R126.2
X0: I30.13 (IOB0), I122.33 (X0), M6.12
X1: I30.12 (IOB1), I122.32 (X1), M6.11
X2: I30.11 (IOB2), I122.31 (X2), M6.10
X3: I30.10 (IOB3), I122.30 (X3), M6.9
X4: I30.9 (IOB4), I122.29 (X4), M6.8
X5: I30.8 (IOB5), I122.28 (X5), M6.7
X6: I30.7 (IOB6), I122.8 (X6), M6.6
X7: I30.6 (IOB7), I122.9 (X7), M6.5
Y0: I30.21 (IOA0), I122.35 (Y0), M6.20
Y1: I30.20 (IOA1), I122.37 (Y1), M6.19
Y2: I30.19 (IOA2), I122.39 (Y2), M6.18
Y3: I30.18 (IOA3), I122.1 (Y3), M6.17
Y4: I30.17 (IOA4), I122.21 (Y4), M6.16
Y5: I30.16 (IOA5), I122.19 (Y5), M6.15
Y6: I30.15 (IOA6), I122.17 (Y6), M6.14
Y7: I30.14 (IOA7), I122.15 (Y7), M6.13
~BREAK: Q122.1 (C); also elsewhere on the board
~CTRL: I36.6 (I2a), M6.2, Q121.1 (C), R10.2
~GRPH: I36.2 (I0a), M6.4, Q123.1 (C), R11.2
~KYBDINTMSK: I32.12; also elsewhere on the board
~PSG: I28.2, I28.6, I28.8; also elsewhere on the board
~RD: I32.13; also elsewhere on the board
~SFTRST: I28.13, I30.23 (~RESET); also elsewhere on the board
~SHFT: I36.4 (I1a), M6.3, Q124.1 (C), R8.2
~WR: I28.9; also elsewhere on the board

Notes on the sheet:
SHIFT
GRPH
CTRL
AUDIO OUT
RESET "BREAK"

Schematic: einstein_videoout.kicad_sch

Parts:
C81: 47nF; C_Disc_5.08mm
C82: 100uF; Elec_2.5mm - Box
L81: 10uH; Resistor 12.70mm
M81: COMPOSITE; RCA
Q81: BC549; Transistor - Box 1 (Leg Rear)
R88: 1K; Pot Straight
R89: 100R; Resistor 10.16mm
R90: 330R; Resistor 10.16mm

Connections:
+5V: L81.1; also elsewhere on the board
+5VL: C81.1, C82.1, L81.2, Q81.1 (C); also elsewhere on the board
GND: C81.2, C82.2, M81.2 (Ext), R89.2, R90.2; also elsewhere on the board
unnamed: M81.1 (In), Q81.3 (E), R90.1
unnamed: R88.2, R89.1
Y: Q81.2 (B), R88.1; also elsewhere on the board

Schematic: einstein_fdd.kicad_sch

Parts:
I34: 74LS02; DIP-14_W7.62mm
I42: WD1770; DIP-28_W15.24mm
I43: 74LS373; DIP-20_W7.62mm
I44, I45: 74LS38; DIP-14_W7.62mm
M4: EXTERNAL; PinHeader_2x17_P2.54mm; not fitted
M5: INTERNAL; PinHeader_2x17_P2.54mm
R27, R28, R30, R31: 220R; Resistor 10.16mm

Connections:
8MHZ: I42.18 (CLK); also elsewhere on the board
+5V: I42.15 (VCC), I43.20 (VCC), I44.14 (VCC), I45.14 (VCC), R27.1, R28.1, R30.1, R31.1; also elsewhere on the board
/Addressing/A0: I42.3 (A0); also elsewhere on the board
/Addressing/A1: I42.4 (A1); also elsewhere on the board
/CPU and Buffers/D0: I42.5 (DAL0), I43.3 (D0); also elsewhere on the board
/CPU and Buffers/D1: I42.6 (DAL1), I43.4 (D1); also elsewhere on the board
/CPU and Buffers/D2: I42.7 (DAL2), I43.7 (D2); also elsewhere on the board
/CPU and Buffers/D3: I42.8 (DAL3), I43.8 (D3); also elsewhere on the board
/CPU and Buffers/D4: I42.9 (DAL4), I43.13 (D4); also elsewhere on the board
/CPU and Buffers/D5: I42.10 (DAL5), I43.14 (D5); also elsewhere on the board
/CPU and Buffers/D6: I42.11 (DAL6), I43.17 (D6); also elsewhere on the board
/CPU and Buffers/D7: I42.12 (DAL7), I43.18 (D7); also elsewhere on the board
GND: I42.14 (GND), I42.26 (~DDEN), I43.1 (OE), I43.10 (GND), I44.7 (GND), I45.7 (GND), M4.1, M4.3, M4.5, M4.7, M4.9, M4.11, M4.13, M4.15, M4.17, M4.19, M4.21, M4.23, M4.25, M4.27, M4.29, M4.31, M4.33, M5.1, M5.3, M5.5, M5.7, M5.9, M5.11, M5.13, M5.15, M5.17, M5.19, M5.21, M5.23, M5.25, M5.27, M5.29, M5.31, M5.33; also elsewhere on the board
unnamed: I42.17 (DIRC), I44.9, I44.10
unnamed: I42.20 (MO), I45.1, I45.4, I45.9, I45.10
unnamed: I42.16 (STEP), I44.12, I44.13
unnamed: I42.22 (WD), I44.1, I44.2
unnamed: I42.21 (WG), I44.4, I44.5
unnamed: I34.10, I43.11 (LE)
unnamed: I43.2 (O0), I45.2
unnamed: I43.5 (O1), I45.5
unnamed: I43.12 (O4), I45.12, I45.13
fDIR: I44.8, M4.18, M5.18
fDRIVE0: I45.3, M4.10, M5.10
fDRIVE1: I45.6, M4.12, M5.12
fDRIVE2: M4.14, M5.14
fDRIVE3: M4.6, M5.6
fINDEX: I42.24 (~IP), M4.8, M5.8, R30.2
fMOTOR1: I45.8, M4.16, M5.16
fREAD: I42.19 (~RD), M4.30, M5.30, R31.2
fSIDE1: I45.11, M4.32, M5.32
fSTEP: I44.11, M4.20, M5.20
fTRACK0: I42.23 (~TR00), M4.26, M5.26, R27.2
fWDATA: I44.3, M4.22, M5.22
fWGATE: I44.6, M4.24, M5.24
fWRITEPROT: I42.25 (~WPRT), M4.28, M5.28, R28.2
~DRSEL: I34.8; also elsewhere on the board
~FDC: I42.1 (~CS); also elsewhere on the board
~SFTRST: I42.13 (~MR); also elsewhere on the board
~WR: I34.9, I42.2 (R~W); also elsewhere on the board

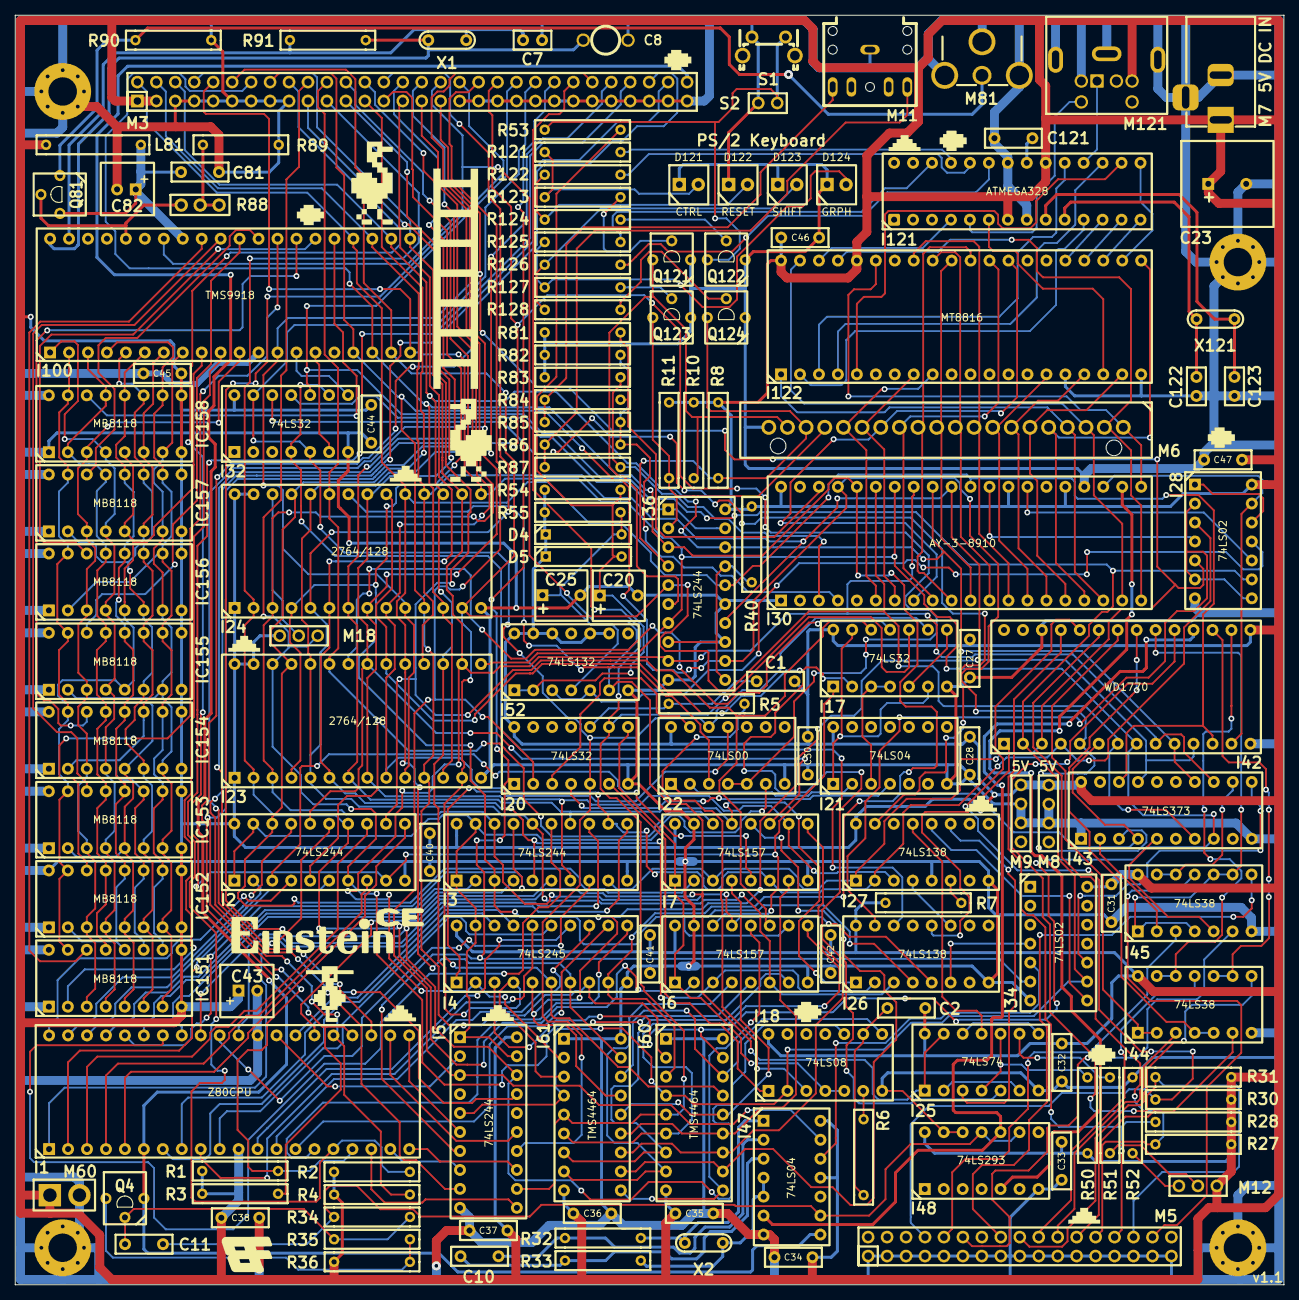
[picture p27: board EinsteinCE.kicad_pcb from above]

Board: 2 copper layers, 170.0 x 170.1 mm, 174 parts (1 on the bottom side), 233 nets.

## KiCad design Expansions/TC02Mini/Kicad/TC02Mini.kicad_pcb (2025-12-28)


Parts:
C40: 47uF 16V; Elec_5.08mm - No Box
C41, C42, C43, C44, C45, C46, C47, C48, C49, C50: 100nF; C_Disc_5.08mm
G1: Board Folk Logo; BF12

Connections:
+5V: C40.1, C41.1, C42.1, C43.1, C44.1, C45.1, C46.1, C47.1, C48.1, C49.1, C50.1; also elsewhere on the board
GND: C40.2, C41.2, C42.2, C43.2, C44.2, C45.2, C46.2, C47.2, C48.2, C49.2, C50.2; also elsewhere on the board

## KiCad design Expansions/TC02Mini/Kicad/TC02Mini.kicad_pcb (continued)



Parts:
C7: 10nF; C_Disc_5.08mm
C8: 33pF; C_Disc_5.08mm
C10: 47pF; C_Disc_5.08mm
I1: 74LS245; DIP-20_W7.62mm
I2: 2128 RAM; DIP-24_W15.24mm
I3: 6845 CRTC; DIP-40_W15.24mm
I4: 27C64; DIP-28_W15.24mm
I5: 74LS165; DIP-16_W7.62mm
I6, I11: 74LS04; DIP-14_W7.62mm
I7: 74LS32; DIP-14_W7.62mm
I8: 74LS86; DIP-14_W7.62mm
I9: 74LS20; DIP-14_W7.62mm
I10: 74LS293; DIP-14_W7.62mm
I12: 74LS125; DIP-14_W7.62mm
I13, I14, I15: 74LS157; DIP-16_W7.62mm
I16: 74LS27; DIP-14_W7.62mm
I17: 74LS10; DIP-14_W7.62mm
I18: 74LS74; DIP-14_W7.62mm
M1: SPARE; LK 3-Pin 2.54mm - Box
M2: 525; LK 3-Pin 2.54mm - Box
M3: AU80; LK 3-Pin 2.54mm - Box
M4: BANK; LK 3-Pin 2.54mm - Box
M8: COMPOSITE VIDEO; RCA
Q1: BC307; Transistor - Box 1 (Leg Rear)
R1, R4, R6: 2K2; Resistor 10.16mm
R2, R3: 820R; Resistor 10.16mm
R5, R11: 1K; Resistor 10.16mm
R7: 470R; Resistor 10.16mm
R8, R10: 68R; Resistor 10.16mm
R9: 390R; Resistor 10.16mm
X1: 16MHz; Crystal

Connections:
+5V: I1.20 (VCC), I2.24 (Vcc), I3.2 (~RESET), I3.20 (VCC), I4.1 (VPP), I4.26 (A13), I4.27 (~PGM), I4.28 (VCC), I5.16 (VCC), I6.14 (VCC), I7.14 (VCC), I8.14 (VCC), I9.14 (VCC), I10.14 (VCC), I11.14 (VCC), I12.14 (VCC), I13.16 (VCC), I14.16 (VCC), I15.16 (VCC), I16.14 (VCC), I17.14 (VCC), I18.14 (VCC), M4.1, R1.1, R4.1, R6.1, R10.1, R11.1; also elsewhere on the board
/80 Column Schematic/A0: I3.24 (RS), I15.2 (I0a); also elsewhere on the board
/80 Column Schematic/A1: I15.5 (I0b); also elsewhere on the board
/80 Column Schematic/A2: I7.10, I15.11 (I0c), I17.10; also elsewhere on the board
/80 Column Schematic/A3: I6.3, I17.2; also elsewhere on the board
/80 Column Schematic/A4: I16.3; also elsewhere on the board
/80 Column Schematic/A5: I16.4; also elsewhere on the board
/80 Column Schematic/A6: I17.1, I17.3; also elsewhere on the board
/80 Column Schematic/A7: I16.5; also elsewhere on the board
/80 Column Schematic/A8: I13.2 (I0a); also elsewhere on the board
/80 Column Schematic/A9: I13.5 (I0b); also elsewhere on the board
/80 Column Schematic/A10: I13.11 (I0c); also elsewhere on the board
/80 Column Schematic/A11: I13.14 (I0d); also elsewhere on the board
/80 Column Schematic/A12: I14.2 (I0a); also elsewhere on the board
/80 Column Schematic/A13: I14.5 (I0b); also elsewhere on the board
/80 Column Schematic/A14: I14.11 (I0c); also elsewhere on the board
/80 Column Schematic/A15: I14.14 (I0d); also elsewhere on the board
/80 Column Schematic/D0: I1.18 (B0), I3.33 (D0), I12.3; also elsewhere on the board
/80 Column Schematic/D1: I1.17 (B1), I3.32 (D1), I12.6; also elsewhere on the board
/80 Column Schematic/D2: I1.16 (B2), I3.31 (D2), I12.8; also elsewhere on the board
/80 Column Schematic/D3: I1.15 (B3), I3.30 (D3), I12.11; also elsewhere on the board
/80 Column Schematic/D4: I1.14 (B4), I3.29 (D4); also elsewhere on the board
/80 Column Schematic/D5: I1.13 (B5), I3.28 (D5); also elsewhere on the board
/80 Column Schematic/D6: I1.12 (B6), I3.27 (D6); also elsewhere on the board
/80 Column Schematic/D7: I1.11 (B7), I3.26 (D7); also elsewhere on the board
BANK: I4.2 (A12), M4.2
DISEN: C10.1, I3.18 (DE), I18.12 (D)
EN: I3.23 (E), I6.2
EN2: I6.10, I17.11
GND: C8.1, C10.2, I1.10 (GND), I2.12 (GND), I2.18 (~CS), I3.1 (GND), I3.3 (LPSTB), I4.14 (GND), I4.20 (~CE), I4.22 (~OE), I5.8 (GND), I5.10 (DS), I5.15 (~CE), I6.7 (GND), I7.7 (GND), I8.5, I8.7 (GND), I9.7 (GND), I10.7 (GND), I10.10 (Cp0), I10.12 (Mr1), I10.13 (Mr2), I11.7 (GND), I12.7 (GND), I13.8 (GND), I13.15 (E), I14.8 (GND), I14.15 (E), I15.8 (GND), I15.13 (I1d), I15.14 (I0d), I15.15 (E), I16.7 (GND), I17.7 (GND), I18.7 (GND), M1.3, M2.3, M3.3, M4.3, M8.2 (Ext), Q1.1 (C), R7.2; also elsewhere on the board
HS: I3.39 (HS), I16.1, I16.2
unnamed: C7.1, I11.12, R2.2
unnamed: C7.2, I11.11, R3.1
unnamed: C8.2, I11.9, I11.10, R3.2, X1.2
unnamed: I1.2 (A0), I2.9 (D0), I4.7 (A3)
unnamed: I1.3 (A1), I2.10 (D1), I4.6 (A4)
unnamed: I1.4 (A2), I2.11 (D2), I4.5 (A5)
unnamed: I1.5 (A3), I2.13 (D3), I4.4 (A6)
unnamed: I1.6 (A4), I2.14 (D4), I4.3 (A7)
unnamed: I1.7 (A5), I2.15 (D5), I4.25 (A8)
unnamed: I1.8 (A6), I2.16 (D6), I4.24 (A9)
unnamed: I1.9 (A7), I2.17 (D7), I4.21 (A10)
unnamed: I4.11 (D0), I5.11 (D0)
unnamed: I4.12 (D1), I5.12 (D1)
unnamed: I4.13 (D2), I5.13 (D2)
unnamed: I4.15 (D3), I5.14 (D3)
unnamed: I4.16 (D4), I5.3 (D4)
unnamed: I4.17 (D5), I5.4 (D5)
unnamed: I4.18 (D6), I5.5 (D6)
unnamed: I4.19 (D7), I5.6 (D7)
unnamed: I5.2 (CP), I11.2
unnamed: I5.9 (Q7), I8.2
unnamed: I5.1 (~PL), I6.9, I9.8
unnamed: I6.12, I7.2
unnamed: I8.3, I9.1, I9.2
unnamed: I8.6, I9.5
unnamed: I8.9, I9.6
unnamed: I8.4, I8.10, I8.12, I8.13, R1.2
unnamed: I9.13, I10.11 (Cp1), I11.1, I11.8
unnamed: I9.10, I10.5 (Q1)
unnamed: I10.4 (Q2), I11.3
unnamed: I3.21 (CLK), I10.8 (Q3), I11.5
unnamed: I9.12, I11.4
unnamed: I9.9, I11.6
unnamed: I11.13, R2.1, X1.1
unnamed: I3.4 (MA0), I13.3 (I1a)
unnamed: I3.5 (MA1), I13.6 (I1b)
unnamed: I3.6 (MA2), I13.10 (I1c)
unnamed: I3.7 (MA3), I13.13 (I1d)
unnamed: I2.8 (A0), I13.4 (Za)
unnamed: I2.7 (A1), I13.7 (Zb)
unnamed: I2.6 (A2), I13.9 (Zc)
unnamed: I2.5 (A3), I13.12 (Zd)
unnamed: I3.8 (MA4), I14.3 (I1a)
unnamed: I3.9 (MA5), I14.6 (I1b)
unnamed: I3.10 (MA6), I14.10 (I1c)
unnamed: I3.11 (MA7), I14.13 (I1d)
unnamed: I2.4 (A4), I14.4 (Za)
unnamed: I2.3 (A5), I14.7 (Zb)
unnamed: I2.2 (A6), I14.9 (Zc)
unnamed: I2.1 (A7), I14.12 (Zd)
unnamed: I3.12 (MA8), I15.3 (I1a)
unnamed: I3.13 (MA9), I15.6 (I1b)
unnamed: I3.14 (MA10), I15.10 (I1c)
unnamed: I2.23 (A8), I15.4 (Za)
unnamed: I2.22 (A9), I15.7 (Zb)
unnamed: I2.19 (A10), I15.9 (Zc)
unnamed: I16.6, I17.5, I17.13
unnamed: I6.4, I17.4
unnamed: I7.5, I17.6
unnamed: I7.13, I17.8
unnamed: I7.9, I7.12, I17.12
unnamed: I6.8, I18.3 (C), I18.11 (C)
unnamed: I3.19 (CURSOR), I18.2 (D)
unnamed: I8.1, I18.5 (Q)
unnamed: I18.1 (~R), I18.4 (~S), I18.10 (~S), I18.13 (~R), R6.2
unnamed: M1.1, M2.1, M3.1, R4.2
unnamed: I12.12, M1.2
unnamed: I12.9, M2.2
unnamed: I12.5, M3.2
unnamed: M8.1 (In), R8.2
unnamed: Q1.2 (B), R5.2, R7.1, R9.2, R11.2
unnamed: Q1.3 (E), R8.1, R10.2
RA0: I3.38 (RA0), I4.10 (A0)
RA1: I3.37 (RA1), I4.9 (A1)
RA2: I3.36 (RA2), I4.8 (A2)
RA3: I3.35 (RA3), I4.23 (A11)
VIDEO: I8.8, R9.1
VS: I3.40 (VS), I16.13
~CRTCS: I3.25 (~CS), I7.8
~CSYNC: I16.12, R5.1
~DISEN: I9.4, I12.2, I18.9 (Q)
~EN: I6.1, I6.11, I7.3, I7.4
~IORQ: I7.1; also elsewhere on the board
~M1: I6.13; also elsewhere on the board
~MUX: I1.19 (CE), I7.6, I13.1 (S), I14.1 (S), I15.1 (S), I16.9
~RAMOE: I2.20 (~OE), I6.5, I16.8
~RAMWR: I1.1 (A->B), I2.21 (R/W), I6.6
~SELCS: I7.11, I12.1, I12.4, I12.10, I12.13
~WR: I3.22 (R/~W), I16.10, I16.11, I17.9; also elsewhere on the board

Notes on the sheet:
(SPARE)


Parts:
M300: TATUNG PIPE; M3 PinHeader_2x30_P2.54mm

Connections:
+5V: M300.1, M300.3; also elsewhere on the board
/80 Column Schematic/A0: M300.33; also elsewhere on the board
/80 Column Schematic/A1: M300.32; also elsewhere on the board
/80 Column Schematic/A2: M300.31; also elsewhere on the board
/80 Column Schematic/A3: M300.30; also elsewhere on the board
/80 Column Schematic/A4: M300.29; also elsewhere on the board
/80 Column Schematic/A5: M300.28; also elsewhere on the board
/80 Column Schematic/A6: M300.27; also elsewhere on the board
/80 Column Schematic/A7: M300.26; also elsewhere on the board
/80 Column Schematic/A8: M300.25; also elsewhere on the board
/80 Column Schematic/A9: M300.24; also elsewhere on the board
/80 Column Schematic/A10: M300.23; also elsewhere on the board
/80 Column Schematic/A11: M300.22; also elsewhere on the board
/80 Column Schematic/A12: M300.21; also elsewhere on the board
/80 Column Schematic/A13: M300.20; also elsewhere on the board
/80 Column Schematic/A14: M300.19; also elsewhere on the board
/80 Column Schematic/A15: M300.18; also elsewhere on the board
/80 Column Schematic/D0: M300.16; also elsewhere on the board
/80 Column Schematic/D1: M300.14; also elsewhere on the board
/80 Column Schematic/D2: M300.12; also elsewhere on the board
/80 Column Schematic/D3: M300.10; also elsewhere on the board
/80 Column Schematic/D4: M300.8; also elsewhere on the board
/80 Column Schematic/D5: M300.6; also elsewhere on the board
/80 Column Schematic/D6: M300.4; also elsewhere on the board
/80 Column Schematic/D7: M300.2; also elsewhere on the board
GND: M300.5, M300.7, M300.9, M300.11, M300.13, M300.15, M300.17, M300.35, M300.37, M300.39, M300.41, M300.43, M300.45, M300.47, M300.49, M300.51, M300.53, M300.55, M300.57, M300.59; also elsewhere on the board
SYSCLK: M300.60
~BUSACK: M300.40
~BUSREQ: M300.58
~HALT: M300.50
~INT: M300.54
~IORQ: M300.46; also elsewhere on the board
~M1: M300.38; also elsewhere on the board
~MREQ: M300.48
~NMI: M300.52
~RD: M300.44
~RESET: M300.34
~RFSH: M300.36
~WAIT: M300.56
~WR: M300.42; also elsewhere on the board


Board: 2 copper layers, 199.6 x 74.2 mm, 52 parts (0 on the bottom side), 120 nets.

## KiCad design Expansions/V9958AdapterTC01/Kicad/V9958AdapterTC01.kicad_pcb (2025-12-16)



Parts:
C150, C151, C152, C153, C154, C155: 100nF; C_Disc_5.08mm
C156: 220uF; Elec_5.08mm - Big Box
C157, C158, C159: 1uF; CP_2.5MM
C170, C171: 27pF; C_Disc_5.08mm
D150: 5V; LED_D3.0mm
D151: 1N914; Diode 7.62mm
G150: Board Folk Logo; BF12
I160: V9958; DIP-64_1.78mm Pitch_Socket
I170, I171, I172, I173, I174, I175: TMS4464; DIP-18_W7.62mm
J150: VDP PLUG; DIP-40_W15.24mm_Plug
J151: DAC Power; SolderJumper-2_P1.3mm_Bridged_RoundedPad1.0x1.5mm
J153: A1 & /WAIT; M11 PinHeader_1x02_P2.54mm
M100: M100/101; PinSocket_2x08_P2.54mm_Vertical
Q150, Q151, Q152, Q153: BC547; Transistor - Box 1 (Leg Rear)
R150, R154, R158: 1K; Resistor 10.16mm
R151, R152, R153: 10K; Resistor 10.16mm
R155, R156, R157: 1K8; Resistor 10.16mm
R159, R160, R161: 470R; Resistor 10.16mm
R162: 100R; Resistor 10.16mm
R163, R164, R165: 12K; Resistor 10.16mm
X170: 21.47727MHz; Crystal

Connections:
+5E: I160.4 (~VRESET), I160.7 (BLEO), I160.11 (CBDR), I160.27 (~HRESET), R154.1
+5V: C150.2, C151.2, C152.2, C153.2, C154.2, C155.2, C156.1, I160.58 (VDD), I170.9 (VCC), I171.9 (VCC), I172.9 (VCC), I173.9 (VCC), I174.9 (VCC), I175.9 (VCC), J150.33 (VCC), J151.2 (B), Q150.1 (C), Q151.1 (C), Q152.1 (C), Q153.1 (C), R150.1, R151.2, R152.2, R153.2, R154.2, R163.2, R164.2, R165.2
/A0: I160.29 (MODE0), J150.13 (MODE)
/A1: I160.28 (MODE1), J153.1
/D0: I160.40 (CD0), J150.17 (CD7)
/D1: I160.39 (CD1), J150.18 (CD6)
/D2: I160.38 (CD2), J150.19 (CD5)
/D3: I160.37 (CD3), J150.20 (CD4)
/D4: I160.36 (CD4), J150.21 (CD3)
/D5: I160.35 (CD5), J150.22 (CD2)
/D6: I160.34 (CD6), J150.23 (CD1)
/D7: I160.32 (CD7), J150.24 (CD0)
/VAD0: I160.49 (AD0), I170.14 (A0), I171.14 (A0), I172.14 (A0), I173.14 (A0), I174.14 (A0), I175.14 (A0)
/VAD1: I160.50 (AD1), I170.13 (A1), I171.13 (A1), I172.13 (A1), I173.13 (A1), I174.13 (A1), I175.13 (A1)
/VAD2: I160.51 (AD2), I170.12 (A2), I171.12 (A2), I172.12 (A2), I173.12 (A2), I174.12 (A2), I175.12 (A2)
/VAD3: I160.52 (AD3), I170.11 (A3), I171.11 (A3), I172.11 (A3), I173.11 (A3), I174.11 (A3), I175.11 (A3)
/VAD4: I160.53 (AD4), I170.8 (A4), I171.8 (A4), I172.8 (A4), I173.8 (A4), I174.8 (A4), I175.8 (A4)
/VAD5: I160.54 (AD5), I170.7 (A5), I171.7 (A5), I172.7 (A5), I173.7 (A5), I174.7 (A5), I175.7 (A5)
/VAD6: I160.55 (AD6), I170.6 (A6), I171.6 (A6), I172.6 (A6), I173.6 (A6), I174.6 (A6), I175.6 (A6)
/VAD7: I160.56 (AD7), I170.10 (A7), I171.10 (A7), I172.10 (A7), I173.10 (A7), I174.10 (A7), I175.10 (A7)
/VD0: I160.41 (RD0), I170.17 (IO4), I172.17 (IO4), I174.17 (IO4)
/VD1: I160.42 (RD1), I170.15 (IO3), I172.15 (IO3), I174.15 (IO3)
/VD2: I160.43 (RD2), I170.3 (IO2), I172.3 (IO2), I174.3 (IO2)
/VD3: I160.44 (RD3), I170.2 (IO1), I172.2 (IO1), I174.2 (IO1)
/VD4: I160.45 (RD4), I171.17 (IO4), I173.17 (IO4), I175.17 (IO4)
/VD5: I160.46 (RD5), I171.15 (IO3), I173.15 (IO3), I175.15 (IO3)
/VD6: I160.47 (RD6), I171.3 (IO2), I173.3 (IO2), I175.3 (IO2)
/VD7: I160.48 (RD7), I171.2 (IO1), I173.2 (IO1), I175.2 (IO1)
B: M100.14, Q152.3 (E), R161.2
G: M100.10, Q151.3 (E), R160.2
GND: C150.1, C151.1, C152.1, C153.1, C154.1, C155.1, C156.2, C170.2, C171.2, D150.1 (K), I160.1 (GND), I160.20 (GND_DAC), I170.1 (~OE), I170.18 (VSS), I171.1 (~OE), I171.18 (VSS), I172.1 (~OE), I172.18 (VSS), I173.1 (~OE), I173.18 (VSS), I174.1 (~OE), I174.18 (VSS), I175.1 (~OE), I175.18 (VSS), J150.12 (GND), M100.4, R155.1, R156.1, R157.1, R159.1, R160.1, R161.1, R162.1
unnamed: D150.2 (A), R150.2
unnamed: D151.1 (K), I160.26 (~WAIT)
unnamed: I160.21 (VDD_DAC), J151.1 (A)
unnamed: C170.1, I160.63 (XTAL1), X170.1
unnamed: C171.1, I160.64 (XTAL2), X170.2
unnamed: J150.11 (R/~W), R152.1
unnamed: J150.2 (~CAS), R153.1
unnamed: J150.1 (~RAS), R151.1
unnamed: C157.1, Q150.2 (B), R163.1
unnamed: C158.1, Q151.2 (B), R165.1
unnamed: C159.1, Q152.2 (B), R164.1
unnamed: Q153.2 (B), R158.2
R: M100.6, Q150.3 (E), R159.2
VB: C159.2, I160.24 (B), R157.2
VG: C158.2, I160.22 (G), R156.2
VR: C157.2, I160.23 (R), R155.2
VR/~W: I160.57 (R/~W), I170.4 (~WE), I171.4 (~WE), I172.4 (~WE), I173.4 (~WE), I174.4 (~WE), I175.4 (~WE)
~CSR: I160.31 (~CSR), J150.15 (~CSR)
~CSW: I160.30 (~CSW), J150.14 (~CSW)
~CSYNC: M100.2, Q153.3 (E), R162.2
~INTVDP: I160.25 (~INT), J150.16 (~INT)
~RST: I160.9 (~RESET), J150.34 (~RESET/SYNC)
~VCAS0: I160.61 (~CAS0), I170.16 (~CAS), I171.16 (~CAS)
~VCAS1: I160.60 (~CAS1), I172.16 (~CAS), I173.16 (~CAS)
~VCASX: I160.59 (~CASX), I174.16 (~CAS), I175.16 (~CAS)
~VCSYNC: I160.6 (~CSYNC), R158.1
~VDPWAIT: D151.2 (A), J153.2
~VRAS: I160.62 (~RAS), I170.5 (~RAS), I171.5 (~RAS), I172.5 (~RAS), I173.5 (~RAS), I174.5 (~RAS), I175.5 (~RAS)

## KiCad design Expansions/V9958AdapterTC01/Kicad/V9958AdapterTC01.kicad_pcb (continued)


Board: 2 copper layers, 131.1 x 91.4 mm, 47 parts (1 on the bottom side), 59 nets.

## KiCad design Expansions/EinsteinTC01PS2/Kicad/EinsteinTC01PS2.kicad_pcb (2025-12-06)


Board: 2 copper layers, 77.9 x 86.5 mm, 23 parts (0 on the bottom side), 44 nets.

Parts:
C1: 100nF; C_Disc_10.16mm
D2: POWER; LED_D3.0mm
D3: SHIFT; LED_D3.0mm
D4: CTRL; LED_D3.0mm
D5: GRPH; LED_D3.0mm
G1: Board Folk Logo; BF8
J1: 5V DC IN; BarrelJack_Horizontal
J2: PS/2; Connector_Mini-DIN_Female_6Pin_2rows
J3: 5V DC IN; JST_XH_B2B-XH-AM_1x02_P2.50mm_Vertical
KB1: COMPUTER INTERFACE; Keyboard_Triple
Q2, Q3, Q4: BC517; Transistor - Box 1 (Leg Rear)
R1: 10K; Resistor 10.16mm
R3, R8, R9, R10: 1K; Resistor 10.16mm
R4, R5, R6: 470R; Resistor 10.16mm
U1: MT8816; DIP-40_W15.24mm
U2: NANO; Arduino_Nano_WithMountingHoles

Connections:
+5V: C1.1, D2.2 (A), J1.1, J2.4, J3.1, U1.36 (CS), U1.40 (VDD), U2.27 (5V)
AX0: U1.5 (AX0), U2.13 (D10)
AX1: U1.22 (AX1), U2.12 (D9)
AX2: U1.23 (AX2), U2.11 (D8)
AX3: U1.4 (AX3), U2.14 (D11)
AY0: U1.24 (AY0), U2.10 (D7)
AY1: U1.25 (AY1), U2.9 (D6)
AY2: U1.2 (AY2), U2.8 (D5)
CTRL: R5.2, U2.21 (A2)
GND: C1.2, D3.1 (K), D4.1 (K), D5.1 (K), J1.2, J1.3, J2.3, J2.7 (GND), J3.2, KB1.1, Q2.3 (E), Q3.3 (E), Q4.3 (E), R1.2, R3.2, U1.16 (VSS), U1.20 (VEE), U2.4 (GND), U2.29 (GND)
GRPH: R6.2, U2.22 (A3)
MTDATA: U1.38 (DATA), U2.5 (D2)
MTRESET: U1.3 (RESET), U2.16 (D13)
MTSTROBE: U1.18 (STROBE), U2.7 (D4)
unnamed: D2.1 (K), R3.1
unnamed: D3.2 (A), R4.1, R8.1
unnamed: D4.2 (A), R5.1, R9.1
unnamed: D5.2 (A), R6.1, R10.1
unnamed: Q2.2 (B), R8.2
unnamed: Q3.2 (B), R9.2
unnamed: Q4.2 (B), R10.2
unnamed: R1.1, U1.6 (X14), U1.7 (X15), U1.10 (X8), U1.11 (X9), U1.12 (X10), U1.13 (X11), U1.26 (X13), U1.27 (X12)
PS2-CLK: J2.5, U2.6 (D3)
PS2-DATA: J2.1, U2.15 (D12)
SHIFT: R4.2, U2.19 (A0)
X0: KB1.12, U1.33 (X0)
X1: KB1.11, U1.32 (X1)
X2: KB1.10, U1.31 (X2)
X3: KB1.9, U1.30 (X3)
X4: KB1.8, U1.29 (X4)
X5: KB1.7, U1.28 (X5)
X6: KB1.6, U1.8 (X6)
X7: KB1.5, U1.9 (X7)
Y0: KB1.20, U1.35 (Y0)
Y1: KB1.19, U1.37 (Y1)
Y2: KB1.18, U1.39 (Y2)
Y3: KB1.17, U1.1 (Y3)
Y4: KB1.16, U1.21 (Y4)
Y5: KB1.15, U1.19 (Y5)
Y6: KB1.14, U1.17 (Y6)
Y7: KB1.13, U1.15 (Y7)
~CTRL: KB1.2, Q3.1 (C)
~GRPH: KB1.4, Q4.1 (C)
~SHIFT: KB1.3, Q2.1 (C)

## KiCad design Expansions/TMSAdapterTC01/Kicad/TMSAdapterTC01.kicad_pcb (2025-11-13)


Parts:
C150, C151, C152, C153, C154, C155: 100nF; C_Disc_5.08mm
C156: 220uF; Elec_5.08mm - Big Box
D150: 5V; LED_D3.0mm
G150: Board Folk Logo; BF12
IC150: TMS9929A; DIP-40_W15.24mm
IC151, IC152, IC153, IC154, IC155, IC156, IC157, IC158: MB8118; DIP-16_W7.62mm
J150: VDP PLUG; DIP-40_W15.24mm_Plug
R150: 1K; Resistor 10.16mm
R151, R152, R153: 10K; Resistor 10.16mm

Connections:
+5V: C150.2, C151.2, C152.2, C153.2, C154.2, C155.2, C156.1, IC150.33 (VCC), IC151.8 (VDD), IC151.9 (VCC), IC152.8 (VDD), IC152.9 (VCC), IC153.8 (VDD), IC153.9 (VCC), IC154.8 (VDD), IC154.9 (VCC), IC155.8 (VDD), IC155.9 (VCC), IC156.8 (VDD), IC156.9 (VCC), IC157.8 (VDD), IC157.9 (VCC), IC158.8 (VDD), IC158.9 (VCC), J150.33 (VCC), R150.1, R151.2, R152.2, R153.2
/A0: IC150.13 (MODE), J150.13 (MODE)
/D0: IC150.24 (CD0), J150.24 (CD0)
/D1: IC150.23 (CD1), J150.23 (CD1)
/D2: IC150.22 (CD2), J150.22 (CD2)
/D3: IC150.21 (CD3), J150.21 (CD3)
/D4: IC150.20 (CD4), J150.20 (CD4)
/D5: IC150.19 (CD5), J150.19 (CD5)
/D6: IC150.18 (CD6), J150.18 (CD6)
/D7: IC150.17 (CD7), J150.17 (CD7)
/VAD0: IC150.10 (AD0), IC151.2 (IN)
/VAD1: IC150.9 (AD1), IC151.5 (A0), IC152.5 (A0), IC153.2 (IN), IC153.5 (A0), IC154.5 (A0), IC155.5 (A0), IC156.5 (A0), IC157.5 (A0), IC158.5 (A0)
/VAD2: IC150.8 (AD2), IC151.7 (A1), IC152.7 (A1), IC153.7 (A1), IC154.7 (A1), IC155.2 (IN), IC155.7 (A1), IC156.7 (A1), IC157.7 (A1), IC158.7 (A1)
/VAD3: IC150.7 (AD3), IC151.6 (A2), IC152.6 (A2), IC153.6 (A2), IC154.6 (A2), IC155.6 (A2), IC156.6 (A2), IC157.2 (IN), IC157.6 (A2), IC158.6 (A2)
/VAD4: IC150.6 (AD4), IC151.12 (A3), IC152.2 (IN), IC152.12 (A3), IC153.12 (A3), IC154.12 (A3), IC155.12 (A3), IC156.12 (A3), IC157.12 (A3), IC158.12 (A3)
/VAD5: IC150.5 (AD5), IC151.11 (A4), IC152.11 (A4), IC153.11 (A4), IC154.2 (IN), IC154.11 (A4), IC155.11 (A4), IC156.11 (A4), IC157.11 (A4), IC158.11 (A4)
/VAD6: IC150.4 (AD6), IC151.10 (A5), IC152.10 (A5), IC153.10 (A5), IC154.10 (A5), IC155.10 (A5), IC156.2 (IN), IC156.10 (A5), IC157.10 (A5), IC158.10 (A5)
/VAD7: IC150.3 (AD7), IC151.13 (A6), IC152.13 (A6), IC153.13 (A6), IC154.13 (A6), IC155.13 (A6), IC156.13 (A6), IC157.13 (A6), IC158.2 (IN), IC158.13 (A6)
/VD0: IC150.32 (RD0), IC151.14 (OUT)
/VD1: IC150.31 (RD1), IC153.14 (OUT)
/VD2: IC150.30 (RD2), IC155.14 (OUT)
/VD3: IC150.29 (RD3), IC157.14 (OUT)
/VD4: IC150.28 (RD4), IC152.14 (OUT)
/VD5: IC150.27 (RD5), IC154.14 (OUT)
/VD6: IC150.26 (RD6), IC156.14 (OUT)
/VD7: IC150.25 (RD7), IC158.14 (OUT)
B-Y: IC150.35 (EXTVDP), J150.35 (B-Y)
GND: C150.1, C151.1, C152.1, C153.1, C154.1, C155.1, C156.2, D150.1 (K), IC150.12 (VSS), IC151.1 (VBB), IC151.16 (VSS), IC152.1 (VBB), IC152.16 (VSS), IC153.1 (VBB), IC153.16 (VSS), IC154.1 (VBB), IC154.16 (VSS), IC155.1 (VBB), IC155.16 (VSS), IC156.1 (VBB), IC156.16 (VSS), IC157.1 (VBB), IC157.16 (VSS), IC158.1 (VBB), IC158.16 (VSS), J150.12 (GND)
unnamed: D150.2 (A), R150.2
unnamed: J150.11 (R/~W), R152.1
unnamed: J150.2 (~CAS), R153.1
unnamed: J150.1 (~RAS), R151.1
R-Y: IC150.38 (CPUCLK), J150.38 (R-Y)
VR/~W: IC150.11 (R/~W), IC151.3 (~WE), IC152.3 (~WE), IC153.3 (~WE), IC154.3 (~WE), IC155.3 (~WE), IC156.3 (~WE), IC157.3 (~WE), IC158.3 (~WE)
XTAL1: IC150.40 (XTAL1), J150.40 (XTAL1)
XTAL2: IC150.39 (XTAL2), J150.39 (XTAL2)
Y: IC150.36 (COMVID), J150.36 (Y)
~CSR: IC150.15 (~CSR), J150.15 (~CSR)
~CSW: IC150.14 (~CSW), J150.14 (~CSW)
~INTVDP: IC150.16 (~INT), J150.16 (~INT)
~RST: IC150.34 (~RESET/SYNC), J150.34 (~RESET/SYNC)
~VCAS: IC150.2 (~CAS), IC151.15 (~CAS), IC152.15 (~CAS), IC153.15 (~CAS), IC154.15 (~CAS), IC155.15 (~CAS), IC156.15 (~CAS), IC157.15 (~CAS), IC158.15 (~CAS)
~VRAS: IC150.1 (~RAS), IC151.4 (~RAS), IC152.4 (~RAS), IC153.4 (~RAS), IC154.4 (~RAS), IC155.4 (~RAS), IC156.4 (~RAS), IC157.4 (~RAS), IC158.4 (~RAS)

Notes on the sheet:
NO LONGER 4116


Board: 2 copper layers, 55.9 x 88.9 mm, 23 parts (0 on the bottom side), 43 nets.

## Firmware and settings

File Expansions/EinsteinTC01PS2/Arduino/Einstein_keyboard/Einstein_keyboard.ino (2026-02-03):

/*
  Einsteinkeyboard - Tatung Einstein TC-01 / Einstein Remix Keyboard Library
  Adapted by Ian Cudlip
  v0.3 03/02/2026

  Based on C64keyboard - Commodore Keyboard library by Hartland PC LLC
  Copyright (c) 2022 Hartland PC LLC
  Written by Robert VanHazinga

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
  You should have received a copy of the GNU Lesser General Public
  License along with this library; if not, write to the Free Software
  Foundation, Inc., 51 Franklin St, Fifth Floor, Boston, MA  02110-1301  USA
*/

#include <PS2KeyAdvanced.h>
#include "Einsteinkeyboard.h"

PS2KeyAdvanced keyboard;
Einsteinkeyboard ckey;
static volatile uint8_t  currkeymap = 1, flags;
static const EinsteinKeymap_t *keymap = NULL;
static volatile bool lshift=false, rshift=false, capslock=false, Einsteingrph=false, Einsteinshift=false, Einsteinshift2=false, Einsteinctrl=false, Einsteinctrl2=false, Einsteinkreset=false, Einsteinalph=false;

void setup() {
  ckey.begin();
  // Configure the keyboard library
  keyboard.begin( DATA_PIN, IRQ_PIN );
  keyboard.setNoRepeat (1);
  keyboard.setNoBreak (0);
  if (debug) {Serial.begin( 9600 );
  Serial.println("Startup..");
  }
}

void loop() {
 if ( keyboard.available() )
 {
   Einsteinkey(keyboard.read());  
 }
}

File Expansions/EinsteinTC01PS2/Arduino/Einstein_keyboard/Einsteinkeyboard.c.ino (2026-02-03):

/*
  Einsteinkeyboard - Tatung Einstein TC-01 / Einstein Remix Keyboard Library
  Adapted by Ian Cudlip

  Based on C64keyboard - Commodore Keyboard library by Hartland PC LLC
  Copyright (c) 2022 Hartland PC LLC
  Written by Robert VanHazinga

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
  You should have received a copy of the GNU Lesser General Public
  License along with this library; if not, write to the Free Software
  Foundation, Inc., 51 Franklin St, Fifth Floor, Boston, MA  02110-1301  USA
*/
#include "Einsteinkeyboard.h"

void resetMT88(void) {
  digitalWrite(ANALOG_SW_DATA , LOW);
  digitalWrite(ANALOG_SW_RESET, HIGH);
  digitalWrite(ANALOG_SW_STROBE, HIGH);
  digitalWrite(ANALOG_SW_RESET, LOW);
  digitalWrite(ANALOG_SW_STROBE, LOW);
  digitalWrite(ANALOG_SW_DATA , HIGH);
  keyboard.setLock (PS2_LOCK_SCROLL && 0);
  capslock = false;
  lshift = false;
  rshift = false;
  currkeymap = 1;
  }

void setswitch(uint16_t c){
  int bitr;
  bool state;
  
  // Fix logic table hole in MT8812/16 and things
  // AX3 line control. There must be a more logical way of working this out.
  if (!MT8808) {
    // any required modifiers here, hopefully none.
    if (c>63) {
      digitalWrite(ANALOG_SW_AX3, LOW);
    } else {
      digitalWrite(ANALOG_SW_AX3, HIGH);
    }
  }

  if (debug){
    Serial.println(c);
  }
  
  if (c < 160) {
    for ( int currentPin = ANALOG_SW_ARRAY_START; currentPin <= ANALOG_SW_ARRAY_END; ++currentPin) {
      bitr = (currentPin - ANALOG_SW_ARRAY_START);
      state =  bitRead(c, bitr);
      digitalWrite(currentPin, state);
    }
    digitalWrite( ANALOG_SW_STROBE, HIGH);
    digitalWrite( ANALOG_SW_STROBE, LOW);
  }
  if (!MT8808){digitalWrite(ANALOG_SW_AX3, LOW);}

}

void setfswitch(uint16_t c){
  int bitr;
  bool state;
  
   digitalWrite(ANALOG_SW_AX3, HIGH);

  if (c < 160) {
    for ( int currentPin = ANALOG_SW_ARRAY_START; currentPin <= ANALOG_SW_ARRAY_END; ++currentPin) {
      bitr = (currentPin - ANALOG_SW_ARRAY_START);
      state =  bitRead(c, bitr);
      digitalWrite(currentPin, state);
    }
    digitalWrite( ANALOG_SW_STROBE, HIGH);
    digitalWrite( ANALOG_SW_STROBE, LOW);
  }
  
  digitalWrite(ANALOG_SW_AX3, LOW);

}

void debugkey (uint16_t c,uint8_t flags,uint8_t kc){
    Serial.print ("Einstein Keycode: ");
    Serial.print (c);
    Serial.print ("  (ASCII Code: ");
    Serial.print (kc);
    Serial.print (" Hex: ");
    Serial.print (kc, HEX);
    Serial.print (")  Flags: ");
      for (int i = 7; i >= 0; i--)
    {
        bool b = bitRead(flags, i);
        Serial.print(b);
    }
    Serial.println();
  }
    
void Einsteinkey(uint16_t k) {
   flags = k >> 8;
   uint8_t kc= k & 0xFF;
   uint16_t c = 0;

  if (currkeymap == 2) {
    if (bitRead(flags, 6)) {
      c = pgm_read_word(keymap->shift_2 + kc);
    }
    else {
      c = pgm_read_word(keymap->noshift_2 + kc);
    }
  }

   if (currkeymap == 1) {
    if (bitRead(flags, 6)) {
      c = pgm_read_word(keymap->shift_1 + kc);
    }
    else {
      c = pgm_read_word(keymap->noshift_1 + kc);
    }
  }
  
//  debug output
    if (debug){debugkey(c,flags,kc);}

    // Ignore extended codes 
    if (kc == 250){
      if (debug){
        Serial.println("Ignore");
      }
      c=IGNORE_KEYCODE;
      }

    // Einstein Keyboard Reset Key (Remixes Only)
    if (kc == EinsteinKRESET) {
      if (bitRead(flags, 7)) {
        Einsteinkreset=false;
        digitalWrite(EinsteinKRESET_PIN, LOW);
        if (debug) {
          Serial.println("Keyboard Reset Off");
        } 
      } else {
        Einsteinkreset=true;
        digitalWrite(EinsteinKRESET_PIN, HIGH);
        if (debug) {
          Serial.println("Keyboard Reset On");
        } 
      }
      c=IGNORE_KEYCODE;
    }

    // Einstein GRPH Key
    if (kc == EinsteinGRPH) {
      if (bitRead(flags, 7)) {
        Einsteingrph=false;
        digitalWrite(EinsteinGRPH_PIN, LOW);
        if (debug) {
          Serial.println("GRPH Off");
        } 
      } else {     
        Einsteingrph=true;
        digitalWrite(EinsteinGRPH_PIN, HIGH);
        if (debug) {
          Serial.println("GRPH On");
        } 
      }
      c=IGNORE_KEYCODE;
    }

    // Einstein ALPH (256) Key - Remix - 26h bit 0 - v0.2 now inverted as keyboard doesn't work the other way (!?)
    if (kc == EinsteinALPH) {
      if (bitRead(flags, 7)) {
        Einsteinalph=false;
        digitalWrite(EinsteinALPH_PIN, HIGH);
        if (debug) {
          Serial.println("ALPH (256) Off");
        } 
      } else {     
        Einsteinalph=true;
        digitalWrite(EinsteinALPH_PIN, LOW);
        if (debug) {
          Serial.println("ALPH (256) On");
        } 
      }
      c=IGNORE_KEYCODE;
    }
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

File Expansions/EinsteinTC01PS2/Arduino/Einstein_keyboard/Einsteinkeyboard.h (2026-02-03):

/*
  Einsteinkeyboard - Tatung Einstein TC-01 / Einstein Remix Keyboard Library
  Adapted by Ian Cudlip

  Based on C64keyboard - Commodore Keyboard library by Hartland PC LLC
  Copyright (c) 2022 Hartland PC LLC
  Written by Robert VanHazinga

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
  You should have received a copy of the GNU Lesser General Public
  License along with this library; if not, write to the Free Software
  Foundation, Inc., 51 Franklin St, Fifth Floor, Boston, MA  02110-1301  USA
*/

#ifndef Einsteinkeyboard_h
#define Einsteinkeyboard_h

#if defined(ARDUINO) && ARDUINO >= 100
#include "Arduino.h"
#else
#include "WProgram.h"
#endif
#define Einstein_KEYMAP_SIZE 	   152 // Size of each array in the key maps

#include "keymapping.h"

#define debug   false    // Set true for serial monitor of Einstein keycodes and PS/2 keycodes

#define MT8808  false    // This has to be set to false now as we use more lines than the MT8808 provides

//PS2 communication pins
#define DATA_PIN				12 // Data pin for PS2 keyboard
#define IRQ_PIN					3  // Interrupt pin for PS2 keyboard

//Scan code value to enable a key map. Default is key map 1.
#define KEY_MAP_1				0x6B // F11?
#define KEY_MAP_2				0x6C // F12?

//Key map value to ignore key press
#define IGNORE_KEYCODE			0x154 //(DEC 340) (Must be > 128)

// Key map value to reset the MT88xx chip
#define MT_RESET        0x6c // F12 activates MT88XX reset

//MT88xx control pins
#define ANALOG_SW_DATA        2 // Sets selected cross switch on/off (Old 13)
#define ANALOG_SW_STROBE      4 // Strobe timing pulse
#define ANALOG_SW_RESET       13 // Reset all MT88XX cross switches to off (Old 2)
#define ANALOG_SW_ARRAY_START 5 // First pin of 6 bit switch addressing. AY2-0 & AX2-0
#define ANALOG_SW_ARRAY_END   10 // Last pin of 6 bit switch addressing. AY2-0 & AX2-0
#define ANALOG_SW_AX3         11 // Pin that controls AX3 (MT8812 & MT8816) 

//Einstein Special Keys
#define EinsteinGRPH_PIN     A3
#define EinsteinSHIFT_PIN    A0
#define EinsteinKRESET_PIN   A1       // Remix
#define EinsteinCTRL_PIN     A2
#define EinsteinALPH_PIN     A4       // Remix (256)

// Key map value for capslock
#define CAPSLOCK_KEY    0x03 // CapsLock key 
#define CAPSLOCK_TRIG   72   // Einstein TC-01 Alph

#define EinsteinGRPH    0x0e
#define EinsteinLSHIFT  0x06
#define EinsteinRSHIFT  0x07
#define EinsteinCTRL    0x08
#define EinsteinCTRL2   0x09
#define EinsteinKRESET  0x04
#define EinsteinALPH    0x0a

class Einsteinkeyboard {
  public:
    Einsteinkeyboard();
    
    static void begin(const EinsteinKeymap_t &map = EinsteinKeymap_main);
};
#endif

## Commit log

2025-11-13 TMS9929 Adapter
    [TMSAdapterTC01-B_Cu.gbr, TMSAdapterTC01-B_Mask.gbr, TMSAdapterTC01-B_Paste.gbr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]
2025-12-06 Images of PS/2 boards
2025-12-06 PS/2 Boards and Code
    [EinsteinTC01PS2-B_Cu.gbr, EinsteinTC01PS2-B_Mask.gbr, EinsteinTC01PS2-B_Paste.gbr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]
2025-12-16 v1.1 Additional Footprints and Symbols update only
    [EinsteinTC01.kicad_sch, einstein_addressing.kicad_sch, einstein_analogue.kicad_sch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]
2025-12-16 V9958 v1.3 Adapter
    [V9958AdapterTC01-B_Cu.gbr, V9958AdapterTC01-B_Mask.gbr, V9958AdapterTC01-B_Paste.gbr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]
2025-12-28 TC-02 Mini v1
    [TC02Mini-B_Cu.gbr, TC02Mini-B_Mask.gbr, TC02Mini-B_Paste.gbr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]
2026-01-25 Einstein CE v1.1
    [EinsteinCE-B_Cu.gbr, EinsteinCE-B_Mask.gbr, EinsteinCE-B_Paste.gbr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]
2026-03-14 v1.1 Project Update
    [einstein_cpu.kicad_sch, einstein_rgb.kicad_sch, einstein_videoout.kicad_sch]
2026-03-14 TC01 Tandy Joystick Adapter
    [TC01TandyJoystick-B_Cu.gbr, TC01TandyJoystick-B_Mask.gbr, TC01TandyJoystick-B_Paste.gbr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]
2026-03-15 Atari Joystick Interface
    [TC01AtariJoystick-B_Cu.gbr, TC01AtariJoystick-B_Mask.gbr, TC01AtariJoystick-B_Paste.gbr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]
2026-03-16 Wrong Directions!
    [TC01AtariJoystick-B_Cu.gbr, TC01AtariJoystick-B_Mask.gbr, TC01AtariJoystick-B_Paste.gbr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]
2026-03-23 Atari Joystick Adapter v1.1
    [TC01AtariJoystick-B_Cu.gbr, TC01AtariJoystick-B_Mask.gbr, TC01AtariJoystick-B_Paste.gbr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]
